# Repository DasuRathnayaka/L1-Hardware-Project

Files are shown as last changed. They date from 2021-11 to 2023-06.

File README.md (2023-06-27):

# Automated Camera Stand
## What is this?
This is an Automated camera stand which possible to guide using GPS coordinates with an obstacle avoidance navigation system. This is made to help wildlife photographers to take good photographs in insecure environments.

## Why is this?
We mainly focused on avoiding danger for the wildlife photographer and the safety of the camera. In this period many wildlife photographers are facing danger while taking photos due to animal attacks. We are going to introduce a new device to avoid such a problem.

## 3D Model




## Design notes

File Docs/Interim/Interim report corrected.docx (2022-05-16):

Faculty of Information Technology

Automated Camera Stand

Group 47

P.A.U.D. Herath | 204074M
P.H.P. Jayathilaka | 204087F
D.M.B.M. Dissanayake | 204047J
S.P.S.N. Pathirana | 204150T
A.M.D.B. Rathnayaka | 204179N
Supervisor’s Name: Mr. B.H. Sudantha Dean/Senior Lecturer Faculty of Information Technology Signature of Supervisor: ……………………………. | Ms. Chanduni Gamage Lecturer Dept. of Information Technology …………………………….

Date of Submission: 30/11/2021

# Table of Content

# Table of Figures

# 1 Introduction

Wildlife photography is a popular category of photography, done by beginners, enthusiasts, and professionals. When taken technically, it involves capturing any type of animal, from birds to insects to butterflies to mammals. But wildlife photographers most commonly take photos of mammals, reptiles, amphibians, and birds. Wildlife photography is a loosely defined profession that demands a passion for nature and art. These photographers make a career of traveling to remote areas and taking pictures of wild animals and natural scenery with a risk.[01]

Wildlife photographers are some of the world’s most valued professionals. According to the U.S. Bureau of Labor Statistics, the average annual wage of most wildlife photographers was $50,290 per year, or $24.18 per hour, as of May 2020. So, this is a higher-paying job. Due to this reason, many new photographers have come to this field. And most wildlife photographers are freelancers. The amount of money that a freelance wildlife photographer makes is largely determined by his talent and ability to get decent-paying work. From all these things it is crystal clear that wildlife photography is one of the best careers in the world.

Wildlife photography is one of the most dangerous professions in the world. The following instances are examples of the dangerous which happen for wildlife photographers. One such incident happened in May of 2000 when a female wildlife photographer was attacked and partially eaten by a 112-pound female black bear in Tennessee. Last year in Colorado a wildlife biologist and photographer, Tom Mussel, got too close to a cow elk and her calf, and he was attacked when he stumbled as he tried to escape the charging cow. Elk and deer will attack humans when they feel cornered or threatened. A southern California man killed by a grizzly bear in Alaska's backcountry was shooting photos of the animal that killed him just moments before the attack, a National Park Service official said Sunday. The bear that killed Richard White, 49, was still with his body when rangers found him in Danail National Park, the official said. Photographs found in his camera revealed that White was watching the bear for at least eight minutes near a river before the attack [02].

From our project, we mainly focused on avoiding the danger for the wildlife photographer and the safety of the camera. In this period many wildlife photographers are dying while taking photos due to animal attacks. We are going to introduce a new device to avoid such a problem.

It is an Automated Camera Stand.

# 2 Literature Survey

In modern cameras, we have the feature to take remote photos. We call it remote photography. Therefore, we can take pictures even if we are far from the camera. But there is no way to bring the camera near to the animals rather than a person carrying the camera.

From the photographer’s side:

- Danger to the life of the photographer.
- Time wastage of the photographer.
- Can’t find a good angle to take a photo.
- Can’t get close enough to the animal.
- Constantly changing lighting conditions.
- No safety to the camera.

From the animal’s side:

- Animals get scared when we try to reach them.
- The behaviors of the animals may change. From the environment side:
- Bad impact on biodiversity.

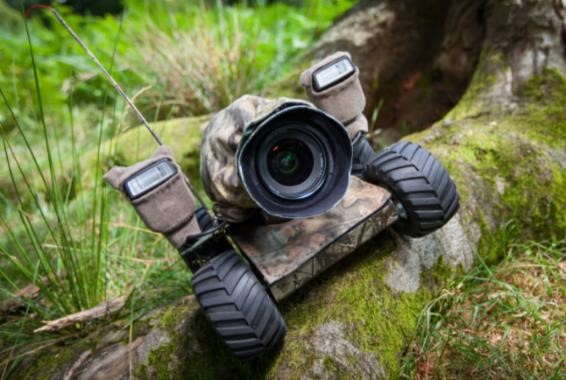
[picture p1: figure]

Therefore, when we try to find out a solution for this we came across with some similar projects.

## 2.1 Beetle cam for wildlife photography

Beetle cam has designed to take wildlife photographs. Wildlife photographer Will Burrard-Lucas had long wanted to add up-close-and-personal images of iconic African animals to his portfolio. But to get those intimate shot of lions and leopards, he would need to crawl up right next to their sharp-toothed faces [03]

Figure 2-1 Beetle cam

This beetle cam can move forward and backward by using the remote controller. And also, beetle cam can be turned by using the wheels.

In our product we have all the functionalities same as the beetle cam. But there are some uncommon functionalities rather than this beetle cam. There is a special feature that can move the camera to the location easily by using GPS location guiding and can avoid obstacles itself. And also, can rotate the camera vertically using the remote controller. There is a siren for the safety of the camera.

## 1.1 VCT-VPR1 Remote Control Tripod

This tripod has been designed to hold a camera and this is controlled by a remote controller. This tripod can check vertical and horizontal alignment using a grid line button. And also bring the subject closer with the zoom controller in the remote.

# 3 Aim & Objectives

## 3.1 Aim

This project aims to the distance photography process to make sure it is safer and effective.

## 3.2 Objectives

The objectives of the project are as follows,

- Rotate the camera both vertically and horizontally.
- Move the stand according to the given GPS coordinates.
- Reach the target safely.
- Protect the camera from the animals by using the alarm.
- Control the camera holder using a remote controller.

# 4 Analysis and Design

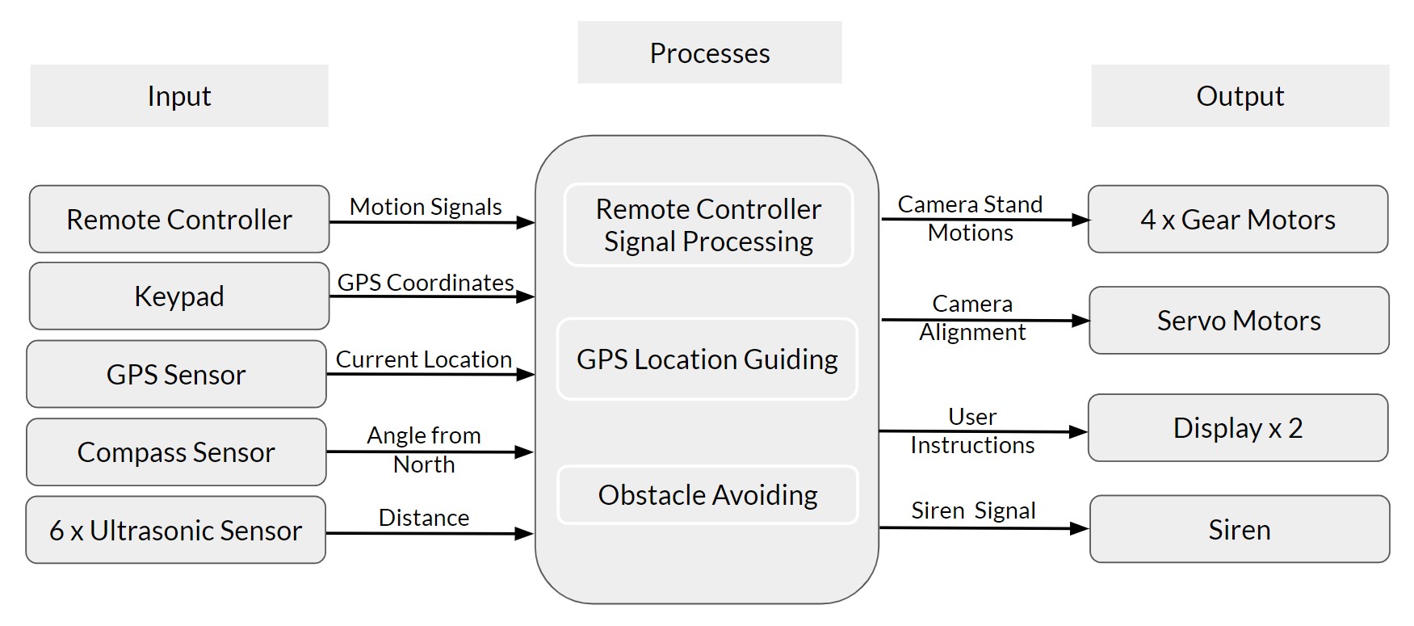
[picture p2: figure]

Figure 4-1 Block Diagram of Proposed System

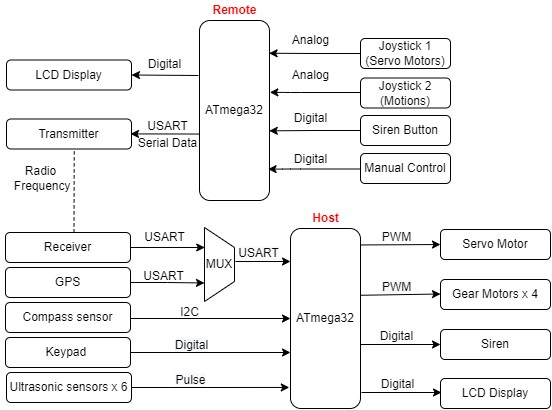
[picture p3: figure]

Figure 4-2 System Diagram of Proposed System

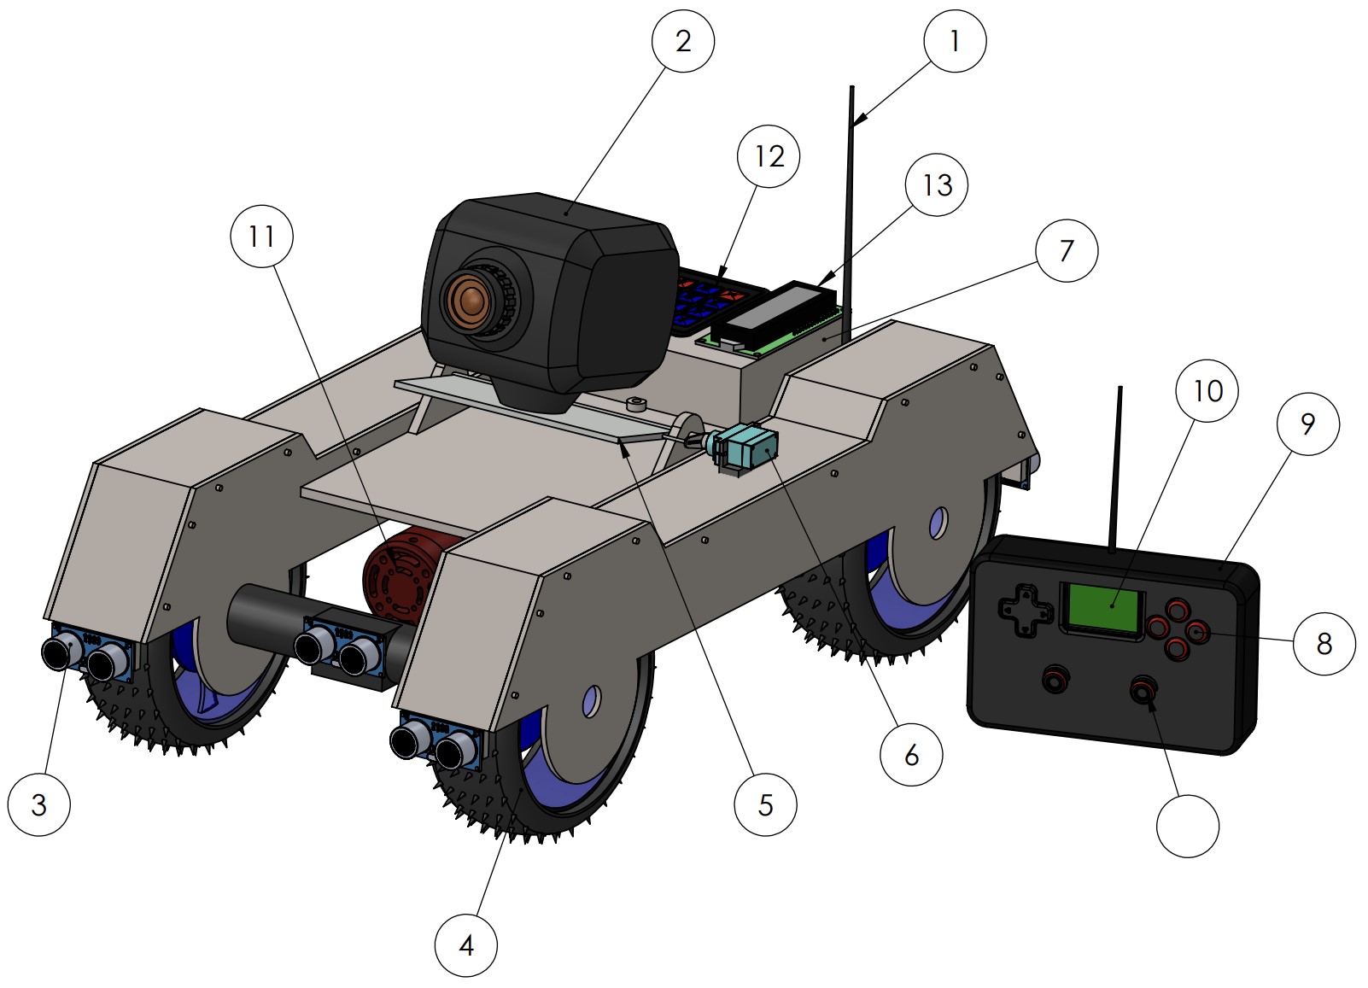
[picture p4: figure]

14

Figure 4-7 Named Camera Stand 3D view

1. RF Antenna
2. Camera
3. Ultrasonic sensors
4. Wheels with gear motors
5. Universal camera mount
6. Servo motor
7. Project box
  a. Atmega32 IC
  b. Compass sensor
  c. RF receiver
  d. GPS module
8. Remote controller buttons
9. Remote controller
10. LCD Display
11. Siren
12. 4x4 Numpad
13. LCD Display
14. Joystick

# 5 Testing and Implementation

In our project, there are two ATmega32 microcontrollers, one is for remote controller and the other one is for the host (Camera stand). The microcontroller takes inputs related to motions and angles from two joysticks. The microcontroller of the remote processes the data and transmit from remote to host through RF (Radio Frequency) modules.

Then the microcontroller of the host gets data from the RF receiver module and GPS module using a 2×1 multiplexer. And also, the microcontroller of the host takes inputs from ultrasonic sensors, compass sensor and the keypad. The microcontroller of the host processes that data and send data to the servo motors and gear motors. And also send digital signals to the display and the siren.

## 5.1 Thumb Joystick

These joystick modules are used to control movements of the camera stand and the vertical camera angle.

Joystick is an input device. Analog joystick is sometimes called as Control Stick. It is used to control the pointer movement in 2-dimension axis. It is made by mounting two potentiometers at a 90 degrees angle to read user’s input. The potentiometers are connected to a short stick centered by springs. One potentiometer is used to get the analog output voltage for X-Direction movement related to move the camera stand forward backward and the other potentiometer is used to get the analog output voltage for Y-Direction movement related to move the camera stand left right. The potentiometers are connected between +VCC and Ground. They simply behave as voltage divider network. The joystick has one freewheeling Holder. According to the holder movement, the potentiometer knob changes its position and resistance of the potentiometer. This module produces an output of around 2.5V from X and Y when it is in resting position. Moving the joystick will cause the output to vary from 0v to 5V depending on its direction. If we connect this module to a microcontroller, we can expect to read a value of around 512 in its resting position. When we move the joystick, we should see the values change from 0 to 1023 depending on its position. Operating Voltage is 5V. Operating current is 3.5 mA. Internal potentiometer value is 10kΩ.Operating Temperature is 0 to 70°C. There are five pins such that Ground pin, Vcc, VRx, VRy and Switch pin.

## 5.2 Liquid Crystal 16 × 2 Display

These LCD displays are used to show GPS coordinates and the current remote's configurations. By using this we can convert camera stand more user friendly.

## 5.3 Motor drive

Motor drive is used to amplify the PWM signal from the Atmega32 and supply it to the gear motors.

## 5.4 Servo Motor

This servo motor is used to change the vertical angle of the camera. Servo motor is used to change the vertical angle of the camera. A servo motor is an electromechanical device that produces torque and the velocity based on the supplied current and voltage. A servo motor works as part of a closed loop system providing torque and velocity as command from a servo controller utilizing a feedback device to close the loop. The feedback device supplies information such as current, velocity or position to the servo controller, which adjusts the motor action depending on the command parameters.

In our project, Servo motors is used for changing the vertical angle of the camera within 90 degrees. When we take a photo of a wild animal, we have to change the orientation of the camera according to the orientation of the animal.

When the signal is received to the Atmega32 microcontroller in the host, it provides a signal to the servo motors to make the correct angle of the servo motors. For that we use the PWM method to process that.

Servo motor has three colour wires. The red colour wire should be connected to the power supply. Brown colour wire connects to the Ground and the Orange colour wire connects to the PWM signal given by the Atmega32 in the host. These are the specifications of the servo motor, speed is 0.1 per second, torque is 2.5kg per cm, weight is 14.7 g and operating voltage is 4.8V to 6V.

## 5.5 Siren

The siren is used to protect the camera stand. when the wild animals come to the attack the camera stand, just sound the siren for run off the animals. These are the specifications of the siren , operating maximum voltage is 12V, operating maximum current is 6 A, Sound intensity is 112 -116 decibels and speed is 1000 rpm.

## 5.6 RF Receiver and Transmitter

We use a 433 MHz RF module to maintain the communication between the remote controller and the host. RF module, as the name suggests, uses radio frequency to send signals. These signals are transmitted at a particular frequency and a baud rate. A receiver can receive these signals only if it is configured for that frequency. Out of that I am responsible for transmitter module. The transmitter module takes serial input and transmits these signals through RF.

The transmitter module consists of four pins namely Vcc, ground, ATAD, and optional ANT pin as shown. The Vcc pin has a wide range input voltage from 3V to 12V. The transmitter consumes a minimum current of 9mA and can go as high as 40mA during transmission. The ATAD pin is the data pin to transmit the signal. This signal modulated and then sent on air at a frequency of 433MHz. This module has an antenna pin which helps to connect the external wire to extend the range up to 100 meters. The size of the antenna will depend on the operating frequency.

The RF transmitter receives serial data and transmits it wirelessly through its RF antenna. The transmission occurs at the rate of 1 Kilobits per second to 10 Kilobits per second.

## 5.7 Gear motor

A gear motor is an all-in-one combination of a motor and gearbox. The addition of a gear head to a motor reduces the speed while increasing the torque output. The most important parameters in regard to gear motors are speed (rpm), torque and efficiency. In order to select the most suitable gear motor load, speed and torque required for the application have to be measured correctly. Most of DC motors can be complemented with unique gearheads.

Reference for the gear motor: https://islproducts.com/design-note/dc-motor-dc-gear-motor-basics/

## 5.8 Ultrasonic sensor

An ultrasonic sensor is an electronic device which measures the distance to an object by emitting an ultrasonic sound wave and converts the reflected sound into an electrical signal. Ultrasonic waves travel faster than the speed of audible sound. Ultrasonic sensors have two parts as the transmitter and receiver. Transmitter send an ultrasonic sound wave and then the receiver receives that wave and calcite the time took to come back to the receiver. And using these data ultrasonic sensor calculates the distance which have to that particular object. This is the way how the ultrasonic sensor works.

Reference for the gear motor: https://www.fierceelectronics.com/sensors/what-ultrasonic-sensor

## 5.9 4x4 Keypad

This is consist of 4 rows and 4 columns which consist of

## 5.10 GPS module

The GPS module uses the USART technology to communicate with the microcontroller. And when taking the specifications of the microcontroller, the operating voltage lies between 2.7V to 3.6V.In the GPS module, there is a GPS antenna to take GPS signals through Radio Frequency which are sent from the GPS satellites. Its serial baud rate lies between 4800 bits per second to two lakhs thirty thousand four hundred bits per second. But the default serial baud rate is nine thousand six hundred. The max supply current for this module is 67 mA.

When taking the pin configuration of the GPS module, there are 4 pins. Vcc pin is for power supply and GND pin is used to ground the GPS module. TXD pin is for the transmission of data and the RXD pin is for the receiving of data. In this project, I have only to transfer data from the GPS module to the Atmega32 chip, and therefore I was only needed to connect the TXD pin of the GPS module with the atmega32 RXD pin. RXD pin is the 14th pin. This is all about the pin configuration of the GPS module.

## 5.11 Compass sensor

For the GPS location guiding algorithm, identifying the current facing direction of the camera stand is a must. The module used is the HMC5883L magnetometer module. This uses the I2C protocol for communication with the Atmega32 microcontroller. According to the documentation, the supply voltage for the magnetometer module lies between 2.7 V to 6.5 V. The max voltage is 6.5 V. The frequency to pass serial data is up to 400kHz and the operating temperature is between -22 to 185 Fahrenheit. The pin configuration is that there are 5 pins in the magnetometer module. The Vcc pin takes power to the module, and the GND pin is to ground. SCL is the serial clock pin, and the SDA is the serial data pin. DRDY is the data-ready interrupt pin.

# 6 Previous Action Plan

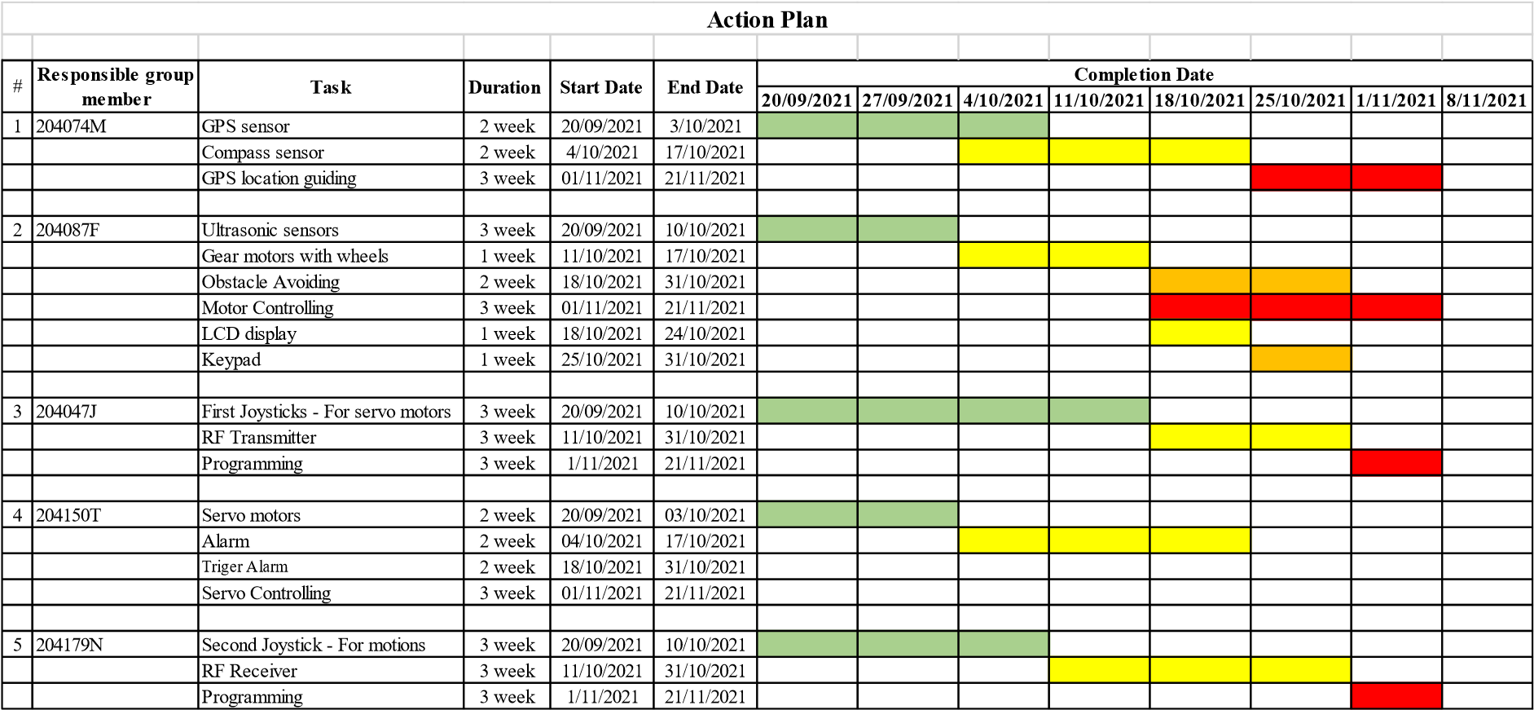
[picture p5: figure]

# 7 Action Plan for Remaining Work

| | | Action Plan
| Responsible group member | Task | Duration | Start Date | End Date | Completion Date
| | | | | | 31/12/2021 | 31/1/2022 | 1/2/2022 | 1/3/2022 | 1/4/2022 | 9/5/2022
1 | 204074M | Compass sensor | 1 month | 31/12/2021 | 31/1/2022
| | GPS location guiding | 1 month | 1/2/2022 | 1/3/2022
| | Test and implementation | 2 months | 2/3/2022 | 9/5/2022
2 | 204087F | Obstacle Avoiding | 1 month | 31/12/2021 | 31/1/2022
| | Motor Controlling | 1 month | 1/2/2022 | 1/3/2022
| | Test and implementation | 2 months | 2/3/2022 | 9/5/2022
3 | 204047J | First Joysticks - For servo motors | 1 month | 31/12/2021 | 31/1/2022
| | RF Transmitter | 1 month | 1/2/2022 | 1/3/2022
| | Test and implementation | 2 months | 2/3/2022 | 9/5/2022
4 | 204150T | Servo motors | 1 month | 31/12/2021 | 31/1/2022
| | Test and implementation | 1 month | 1/2/2022 | 1/3/2022
| | Trigger Alarm | 1 month | 2/3/2022 | 1/4/2022
| | Servo Controlling | 1 month | 2/4/2022 | 9/5/2022
5 | 204179N | Second Joystick - For motions | 1 month | 31/12/2021 | 31/1/2022
| | RF Receiver | 1 month | 1/2/2022 | 1/3/2022
| | Test and implementation | 2 months | 2/3/2022 | 9/5/2022

# Appendix A

# 8 Cost Estimation and Expenditure so far

Component | Unit Price | Quantity | Price (LKR)
68mm RC Car Tire Wheel | Rs. 300.00 | 4 | Rs. 1,200.00
Liquid Crystal 16x2 Display Module | Rs. 300.00 | 1 | Rs. 300.00
2 Pin Switch | Rs. 15.00 | 2 | Rs. 30.00
Thumb Joystick Module | Rs. 150.00 | 2 | Rs. 300.00
RF 433MHz Transmitter/Receiver | Rs. 200.00 | 1 | Rs. 200.00
GY-271 Electronic Triple Axis Compass Module | Rs. 700.00 | 1 | Rs. 700.00
Membrane Keypad - 16 Key | Rs. 180.00 | 1 | Rs. 180.00
HC-SR04 Ultrasonic Sensor Module | Rs. 200.00 | 6 | Rs. 1,200.00
NEO-6M GPS Module | Rs. 1,850.00 | 1 | Rs. 1,850.00
L298N DC Motor Driver Module | Rs. 350.00 | 2 | Rs. 700.00
Servo Motor | Rs. 750.00 | 1 | Rs. 750.00
Atmega32 Microcontroller | Rs. 550.00 | 2 | Rs. 1,100.00
11.1V 2200mAh 3S 25C Li-Po Battery | Rs. 2,800.00 | 1 | Rs. 2,800.00
12V 2000mAh Li-Po Battery | Rs. 1,750.00 | 1 | Rs. 1,750.00
DC Gear Motor 12v 180 RPM | Rs. 950.00 | 4 | Rs. 3,800.00
| | Total | Rs. 16,860.00

[4],[5]

# Appendix B

# 9 Individual Contribution to the Project

## 9.1 P.A.U.D. Herath - 204074M

I studied about the GPS module. Studied about the way how the GPS signals generate and the way of GPS working. Learned about the theory regarding the USART communication. Understood the theory behind the multiplexer to connect the GPS module and the compass sensor module.

### 9.1.1 GPS module (NEO-6M)

The GPS module has a GPS antenna, battery, an EEPROM and a position fix LED indicator. The pins in the NEO-6M are VCC, Tx, Rx and GND. Understood that the D0 and D1 pins must be used to take the serial data using the GPS module. Specifications are that the Operating Voltage is 2.7V - 3.6V. The serial Baud rate lies between 4800 and 230400. The default baud rate is 9600. The operating current of the NEO-6M GPS module is 45mA.

### 9.1.2 Multiplexer

When taking the inputs related to the GPS module and the receiver, I had to use the same pins D0 and D1. Therefore, I used a multiplexer to carry this out.

### 9.1.3 USART communication

To take the serial inputs from the GPS module, I used the USART method.

## 9.2 P.H.P. Jayathilaka 204087F

I have studied about Ultrasonic sensors, Display, Keypad, ADC, PWM. I have started studying about USART. Also, started to study interfacing components with the ATmega32 microcontroller and how to connect components to the microcontroller.

### 9.2.1 Ultrasonic sensor (HC-SR04)

I am using 6 ultrasonic sensors to avoid obstacles. There are 4 pins in the ultrasonic sensor. (VCC, Trig Pin, Echo Pin, GND)

These are the specifications of Ultrasonic sensor. The working power of the ultrasonic sensor is DC 5Vand 15mA,

Working frequency is 40Hz, accurate range is 2cm – 40cm,

Measuring angle is 15 degrees, trigger input signal is 10µS TTL pulse

echo output signal input TTL lever signal and the range in proportion

### 9.2.2 Gear Motors

Due to lack of eight PWM pins for four motors, I had to couple motors as left and right. Then needed PWM pins reduced to four. Furthermore, I used only one PWM pin and a digital pin per side. It is configured by code.

These are the specifications of gear motors

the working voltage is 12V DC, Speed is 180 RPM,

It is a high torque motor and use L298NH – bridge motor drive

## 9.3 D.M.B.M. Dissanayake - 204047J

I have studied about Joystick, RF Transmitter and ADC. I have started to study interfacing components with the ATmega32 microcontroller and how to connect components to the microcontroller.

In our project, I used a joystick to get inputs related to the angle of servo motors. The microcontroller of the remote gets analog inputs from this joystick. We need knowledge about ADC on AVR ATmega32 to process that analog signal. To get this analog input, I had to use A0 pin in the ATmega32 microcontroller. Furthermore, I used a 433 MHz RF transmitter to transmit the above-processed data from the microcontroller.

### 9.3.1 Thumb Joystick

There are 5 pins in the joystick module.

VCC, GND, VRx, VRy, SW

Specifications of thumb joystick module, operating voltage is 5V. Internal potentiometer value is 10kΩ. Operating Temperature is 0 to 70 C֩.

There is no joystick module in proteus. Therefore, I used a variable resistor to connect with the microcontroller.

## 9.4 S.P.S.N. Pathirana 204150T

As a member of our group, I have to work with a servo motor and a siren. First, I studied about the servo motor, and the siren. Second, I selected a suitable type of servo motor and a siren. After that, I started to learn about how they are working. Finally ,started to learn about how they are interfacing with Atmega32 microcontroller

In this project, servo motor is used to change the vertical angle of the camera, according to the signal of the joystick.

### 9.4.1 Servo Motors

These are the specifications of servo motor:

The speed of the servo motor is 0.1 per second.

Torque is 2.5 kg/cm. The weight is 14.7g and

the voltage is 4.8V – 6V

### 9.4.2 Siren

We used a siren to protect the camera stand. when the wild animals come to the attack the camera stand, we just sound the siren for run off the animals. The siren sounds according to the signal given by the siren button in the remote controller. These are the specifications of the siren, operating maximum voltage is 12V, operating maximum current is 6 A, Sound intensity is 112 -116 decibels and speed is 1000 rpm.

## 9.5 A.M.D.B. Rathnayaka 204179N

I studied about the joystick, RF receiver, ADC Technology and started to learn about how the components are working and interfacing with ATmega32 microcontroller. In our project, I have to give inputs to the ATmega32 microcontroller of the remote from the joystick. Moreover, it gives inputs to the microcontroller of the host from the RF receiver.

### 9.5.1 433 MHz Receiver

Receiver uses the USART communication to communicate with the Atmega32 microcontroller of the host. The operating frequency is 433 MHz, the operating voltage is 5V and the supply current is 3.5 mA.

### 9.5.2 Thumb Joystick

There are 5 pins in the joystick module. And the pins in this module are VCC, GND, VRx, VRy, SW. The Operating Voltage is 5V. The Internal potentiometer value is 10kΩ and the operating temperature is 0 to 70 C֩. There is no joystick module in proteus. Therefore, I used two variable resistors to connect with the microcontroller.

# Appendix C

# References

[1] A. Duke, “Hiker photographs bear just before fatal grizzly attack,” CNN, 26-Aug-2012.
[2] J. Dempsey, “Introduction to wildlife photography: A guide for beginners,” Phototraces.com, 03-Jan-2020. [Online]. Available:

https://www.phototraces.com/b/wildlife-photography/. [Accessed: 28-Nov-2021].

[3] M. Gallucci, “These robots are transforming how we see wildlife,” Mashable, 12-Jan2017. [Online]. Available: https://mashable.com/article/robots-wildlife-photography. [Accessed: 28-Nov-2021].
[4] “Microchip.lk – one stop for all your electronics…,” Microchip.lk. [Online]. Available: https://microchip.lk/. [Accessed: 28-Nov-2021].
[5] “TRONIC.LK,” Lankatronics.com. [Online]. Available: https://lankatronics.com/. [Accessed: 28-Nov-2021].

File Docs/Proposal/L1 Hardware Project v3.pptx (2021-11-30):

## Automated Camera Stand

IN 1900 (ICT Project)

Group - 47

Hardware Project

## Group Members

Name | Registration Number | Photos
P.A.U.D. Herath (Team Leader) | 204074M
D.M.B.M. Dissanayake | 204047J
P.H.P. Jayathilaka | 204087F
S.P.S.N. Pathirana | 204150T
A.M.D.B.Rathnayaka | 204179N

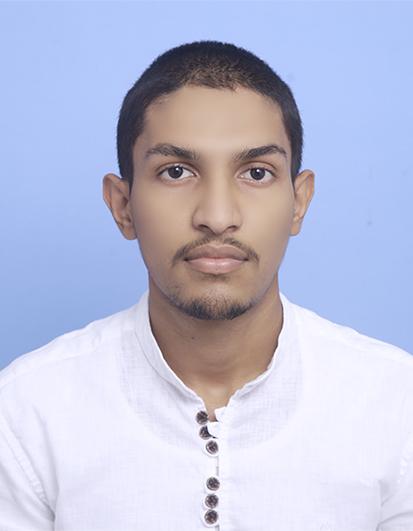
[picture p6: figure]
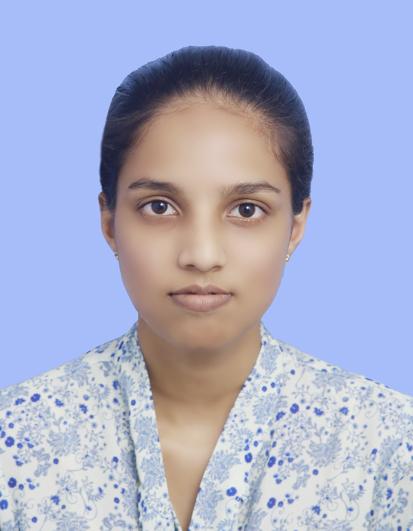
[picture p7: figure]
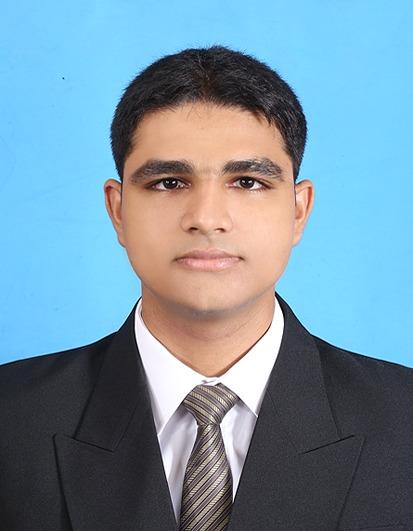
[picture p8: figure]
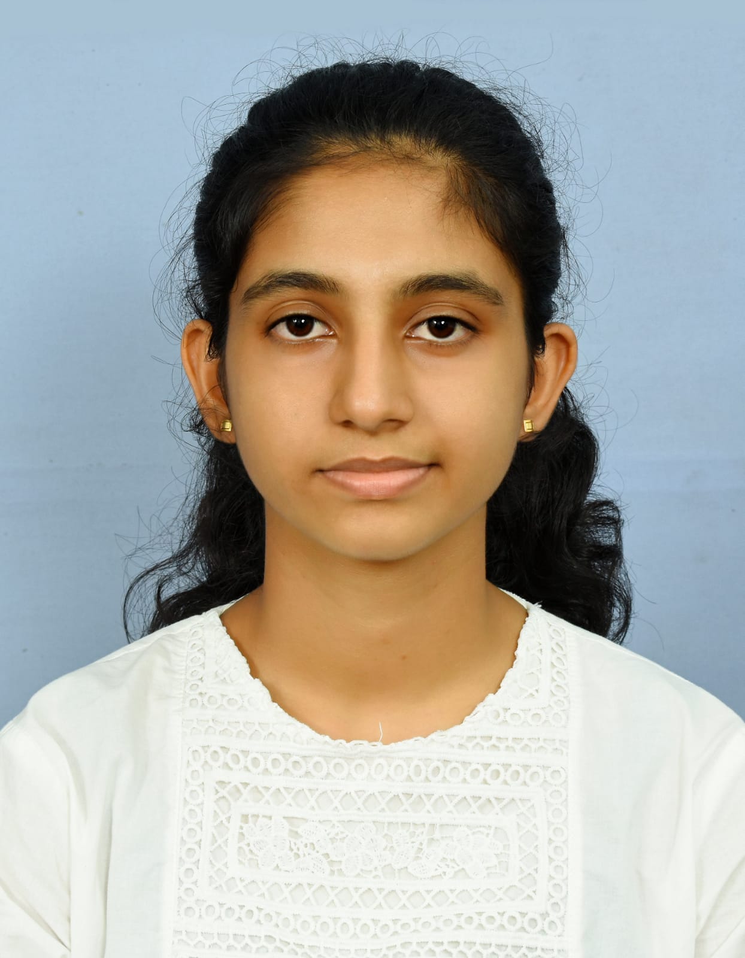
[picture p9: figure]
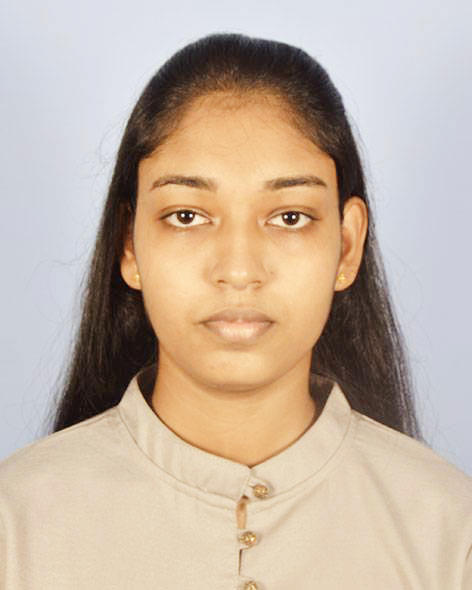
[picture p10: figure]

## Problem in Brief…

Not having a proper mechanism to bring the camera near to the required places or animals rather than a person carrying the camera.

- From photographer’s side :
  - Danger to the life.
  - Time wastage.
  - Can’t find a good angle.
  - Can’t get close enough.
  - Constantly changing lighting conditions.
- From animal’s side :
  - Animals get fear when we try to reach them.
  - Behaviours of the animals may get changed.
- From environment side :
  - Bad impact on biodiversity.

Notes: In modern cameras we have the feature to take remote photos (remote photography). Therefore, we can take pictures even we are far from the camera. But there is not a way to bring the camera near to the animals rather than a person carry the camera.
When we analyze the problem we found 3 main sides of this problem.
When we take from the photographer’s side; Imagine we need to capture a very close wild animal photo, we can’t reach it. Because It will be very dangerous. In past few years many wildlife photographers has died due to animal attacks.
We have to spend lot of time, until the required animals come, to capture their photos.
When the photographer need to take a good quality photograph, taking a close correct angle is an essential thing. But the photographers can’t go near the animals to achieve those requirements.
From animal’s side : If the animal is an innocent one, it does not stay until we go near them.

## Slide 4

Project Aim

- Automate the distance photography process to make sure it is safer and effective.

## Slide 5

Project Objectives

- Rotate the camera both vertically and horizontally.
- Move the stand according to given GPS coordinates.
- Reach the target safely.
- Adjust the height of the rod.
- Protect the camera from the animals by using the alarm.
- Control the camera holder using a remote controller.

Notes: If an animal try to attack the camera holder then we can sound the alarm. Like that we can ensure the safety of the camera.

## Proposed Solution

Processes

Remote Controller Signal Processing

GPS Location Guiding

Obstacle Avoiding

Input

Output

Remote Controller

Motion Signals

Camera Stand Motions

4 x Gear Motors

Keypad

GPS Coordinates

Camera Alignment

Servo Motors

GPS Sensor

Current Location

Compass Sensor

Angle from North

User Instructions

Display x 2

6 x Ultrasonic Sensor

Distance

Siren Signal

Siren

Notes: Remote Controller sends motion signals and processes the remote controller signals to rotate the motors and also the alarm.
We can input the GPS coordinates by using the Keypad.

## Sketch of the camera stand

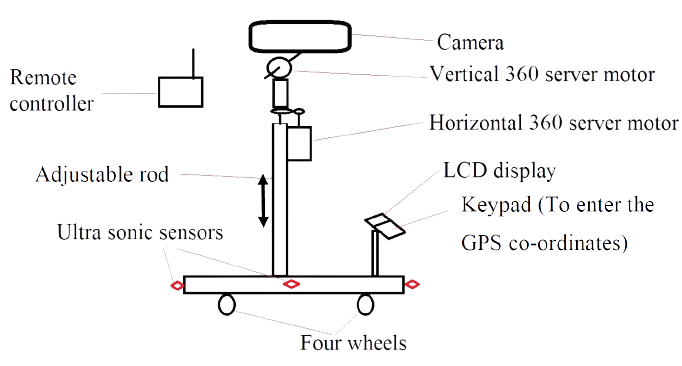
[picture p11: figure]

Siren

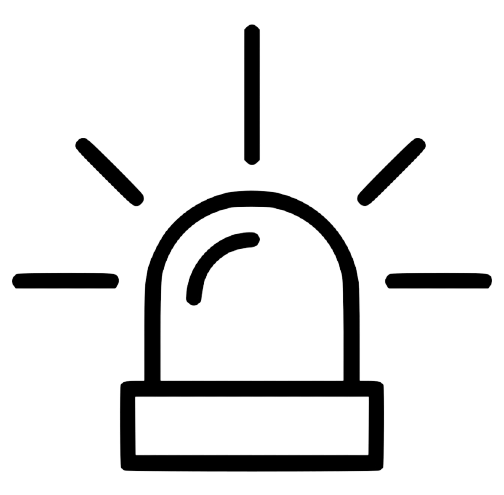
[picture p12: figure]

Project Box

- This head section fits with the stage

))

RF antenna

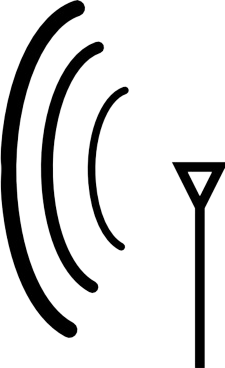
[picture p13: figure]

## Resources (Software)

- Atmel Studio (Microcontroller Coding)

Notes: Up to this state we identified only these softwares. And it may be changed. The softwares are ; 1. 2. 3.

## Resources (Hardware)

- Microcontroller
- GPS Module
- RF Transmitter and Receiver
- Ultrasonic sensor
- Gear Motors
- Servo Motors
- LCD Module
- Motor Driver Module
- Electronic Compass Module
- Keypad
- Li-Po Batteries
- Joystick Module

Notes: These are the hardwares which we suppose to use.

## Cost Estimation

Component | Unit Price | Quantity | Price (LKR)
Membrane Keypad - (https://lankatronics.com/Membrane-Keypad-16-key) 16 Key (https://lankatronics.com/Membrane-Keypad-16-key) | 180 | 1 | 180
HC (https://lankatronics.com/HC-SR04-Ultrasonic-Sensor-module)-SR (https://lankatronics.com/HC-SR04-Ultrasonic-Sensor-module)04 Ultrasonic Sensor Module (https://lankatronics.com/HC-SR04-Ultrasonic-Sensor-module) | 200 | 6 | 1200
NEO-6M GPS Module (https://lankatronics.com/index.php?route=product/product&product_id=469&search=gps&description=true) | 1850 | 1 | 1850
L298N DC Motor Driver Module (https://lankatronics.com/L298-DC-Motor-Driver-Module-Normal) | 350 | 2 | 700
Servo Motor (https://lankatronics.com/MG995-Servo-Digital-Metal-Gear-Servo-Motor) | 750 | 2 | 1500
Atmega32 Microcontroller (https://lankatronics.com/Atmega32A-PU-PDIP) | 550 | 2 | 1100
11.1V 2200mAh 3S 25C Li-Po Battery (https://microchip.lk/product/11-1v-2200mah-3s-25c-lipo-battery-local/) | 2800 | 1 | 2800
12V 2000mAh Li-Po Battery (https://microchip.lk/product/12v-2000mah-rechargeable-lithium-polymer-battery-li-po-lipo-li-po/) | 1750 | 1 | 1750
DC Gear Motor 12v 180 RPM (https://lankatronics.com/370-DC-Gear-Motor-12V-180rpm) | 950 | 4 | 3800

## Cost Estimation (Contd.)

Component | Unit Price | Quantity | Price (LKR)
68mm RC Car Tire Wheel (https://lankatronics.com/68mm-RC-Car-Tire-Wheel) | 300 | 4 | 1200
Liquid Crystal 16x2 Display Module (https://lankatronics.com/index.php?route=product/product&product_id=480) | 300 | 1 | 300
2 Pin Switch (https://lankatronics.com/Rocker-Switch-ON-OFF) | 15 | 2 | 30
Thumb Joystick Module (https://lankatronics.com/index.php?route=product/product&product_id=434) | 150 | 2 | 300
RF 433MHz Transmitter/Receiver (https://lankatronics.com/433Mhz-RF-transmitter-and-receiver-kit) | 200 | 1 | 200
28BYJ-48 Stepper Motor with Driver (https://microchip.lk/product/28byj-48-stepper-motor-with-driver/) | 370 | 1 | 370
GY-271 Electronic Triple Axis Compass Module (https://microchip.lk/product/gy-271/) | 700 | 1 | 700
Total | | | 17,980

Lankatronics (Pvt) Ltd (https://lankatronics.com), Microchip.lk

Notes: The total cost which we suppose to spend for this project is Seven thousand nine hundred and eighty rupees.
And we took all these unit prices referring the Lanka tronics private limited and Microchip.lk web sites.

## How the works are divided…?

| Hardware Part | Software Part
Member - 01 | Servo motors Alarm | Servo Controlling Trigger Alarm
Member - 02 | GPS sensor Compass sensor | GPS location guiding
Member - 03 | Ultrasonic sensors Gear motors with wheels. LCD display and Keypad. | Obstacle Avoiding Motor Controlling Get Inputs from keypad and display
Member - 04 , 05 | Custom remote controller RF Transmitter and Receiver | Communication between Remote and Camera stand

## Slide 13

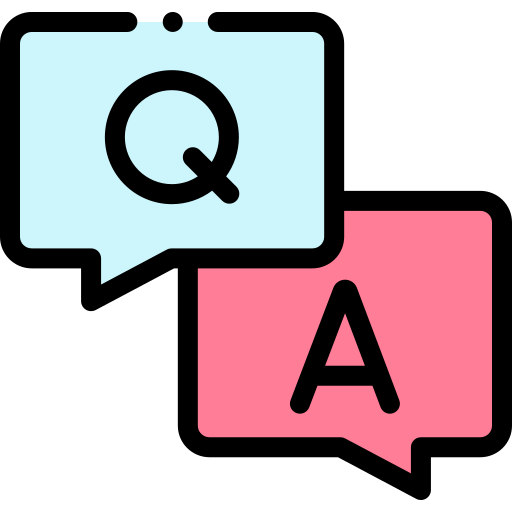
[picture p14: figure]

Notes: Sir , madam ; If there are any questions about the project we will be happy to answer them.

https://www.youtube.com/watch?v=cZm4ZjE-zaU

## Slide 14

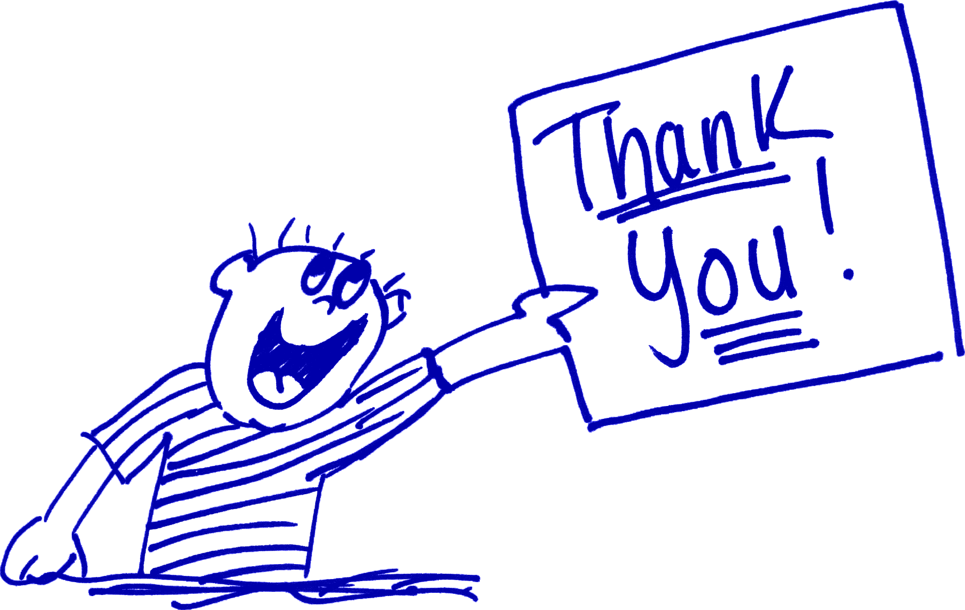
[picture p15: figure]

Group - 47

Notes: Our presentation is over, thank you !!

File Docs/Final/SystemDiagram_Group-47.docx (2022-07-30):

System Diagram

System Diagram of Remote Controller

Digital Signal

Display the auto and manual mode of the camera stand

Auto/Manual Button

DistanceJJ

Digital Signal

Changing the current state of the camera stand as auto and manual.

Siren Button

DistanceJJ

Digital Signal

On and off the siren in the camera stand.

16 x 2 LCD Display

User Instructions

nRF24L01 Transceiver Module

Distance

Sending the Radio Frequency signals to the camera stand through the nRF24L01 module of the remote controller.

Serial Data

Joystick-1

DistanceJJ

Analog Signal

Changing the vertical angle of the camera within 90 degrees.

Joystick-2

DistanceJJ

Analog Signal

Moving the camera stand forward and backward as well as left and right.

Output

Input

Processes

Process 3: Send serial data to the transceiver module using SPI.

Process 1: Get analog signal from two joysticks and convert it to Digital value using ADC.

Process 2: Get digital signals from two buttons and display it using I2C.

Maintain the connection with the Camera stand by using Radio Frequency

See Next Page

See Next Page

4 x Gear Motors

Camera Stand Motions

Digital Signal

To move the camera, stand by rotating the wheels.

Serial Data

NEO-6M GPS Module

To take the real time GPS coordinates which we need to calculate the angle to the user inputted GPS coordinate (user inputted GPS coordinates through the keypad.)

Digital Signal

Keypad

To take the GPS coordinates of the place which we need to move our camara stand.

Serial Data

HMC5883L Magnetometer

To take the current facing direction of the camera stand according to the true North.

Digital Pulse

4 x Ultrasonic Sensor

To detect and avoid obstacles while camera stand is moving.

Siren

Digital Signal

To chase away harmful animals when they try to attack the camera stand.

16 x 2 LCD Display

Serial Data

To display GPS coordinates, to display the status (auto or manual) and to display user messages.

Servo Motor

Camera Alignment

Digital Signal

To lift the camera according to the given angle by the remote controller.

Receiving the Radio Frequency signals which are coming from the nRF module of the remote controller.

Serial Data

nRF24L01 Transceiver Module

Distance

Process 3: If the mode is auto, the GPS coordinates will take from the user.

Process 2: If the mode is manual, get serial data from transceiver (related to joysticks) using SPI and process them.

Process 1: Get received serial data (related to auto/manual button) from transceiver module and according to that, initialize the manual and auto mode.

Process 4: By taking inputs from the GPS module, magnetometer module, and ultrasonic sensor detect the correct path to move the camera stand.

Process 6: While happening this process when the RF module sends a signal siren will be sounded.

Process 5: While finding the correct path according to the process-4 moving the camera stand by using the gear motors (wheels).

Process 7: While happening all these processes the user instructions are given through the LCD Display to the users.

System Diagram of Camera Stand

Group-47 IN1900 Hardware Project

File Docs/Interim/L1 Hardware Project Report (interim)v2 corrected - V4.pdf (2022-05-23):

## Faculty of Information Technology

## Automated Camera Stand

Group 47

P.A.U.D. Herath | 204074M
P.H.P. Jayathilaka | 204087F
D.M.B.M. Dissanayake | 204047J
S.P.S.N. Pathirana | 204150T
A.M.D.B. Rathnayaka | 204179N
Supervisor’s Name: | Mr. B.H. Sudantha
| Dean/Senior Lecturer
| Faculty of Information Technology
Signature of Supervisor: |

Ms. Chanduni Gamage
Lecturer
Dept. of Information Technology

Date of Submission: 30/11/2021

i

Table of Content

ii

Table of Figures

### 1 Introduction

Wildlife photography is a popular category of photography, done by beginners, enthusiasts,

and professionals. When taken technically, it involves capturing any type of animal, from birds

to insects to butterflies to mammals. But wildlife photographers most commonly take photos

of mammals, reptiles, amphibians, and birds. Wildlife photography is a loosely defined

profession that demands a passion for nature and art. These photographers make a career of

traveling to remote areas and taking pictures of wild animals and natural scenery with a risk.[01]

Wildlife photographers are some of the world’s most valued professionals. According to the

U.S. Bureau of Labor Statistics, the average annual wage of most wildlife photographers was

$50,290 per year, or $24.18 per hour, as of May 2020. So, this is a higher-paying job. Due to

this reason, many new photographers have come to this field. And most wildlife photographers

are freelancers. The amount of money that a freelance wildlife photographer makes is largely

determined by his talent and ability to get decent-paying work. From all these things it is crystal

clear that wildlife photography is one of the best careers in the world.

Wildlife photography is one of the most dangerous professions in the world. The following

instances are examples of the dangers which happen for wildlife photographers. One such

incident happened in May of 2000 when a female wildlife photographer was attacked and

partially eaten by a 112-pound female black bear in Tennessee. Last year in Colorado a wildlife

biologist and photographer, Tom Mussel, got too close to a cow elk and her calf, and he was

attacked when he stumbled as he tried to escape the charging cow. Elk and deer will attack

humans when they feel cornered or threatened. A southern California man killed by a grizzly

bear in Alaska's backcountry was shooting photos of the animal that killed him just moments

before the attack, a National Park Service official said Sunday. The bear that killed Richard

White, 49, was still with his body when rangers found him in Danail National Park, the official

said. Photographs found in his camera revealed that White was watching the bear for at least

eight minutes near a river before the attack [02].

From our project, we mainly focused on avoiding danger for the wildlife photographer and the

safety of the camera. In this period many wildlife photographers are dying while taking photos

due to animal attacks. We are going to introduce a new device to avoid such a problem.

It is an Automated Camera Stand.

### 2 Literature Survey

In modern cameras, we have the feature to take remote photos. We call it remote photography.

Therefore, we can take pictures even if we are far from the camera. But there is no way to bring

the camera near to the animals rather than a person carrying the camera.

From the photographer’s side:

- Danger to the life of the photographer.
- Time wastage of the photographer.
- Can’t find a good angle to take a photo.
- Can’t get close enough to the animal.
- Constantly changing lighting conditions.
- No safety to the camera.

From the animal’s side:

- Animals get scared when we try to reach them.
- The behaviors of the animals may change. From the environment side:
- Bad impact on biodiversity.

Therefore, when we try to find out a solution for this, we come across with some similar

projects as following.

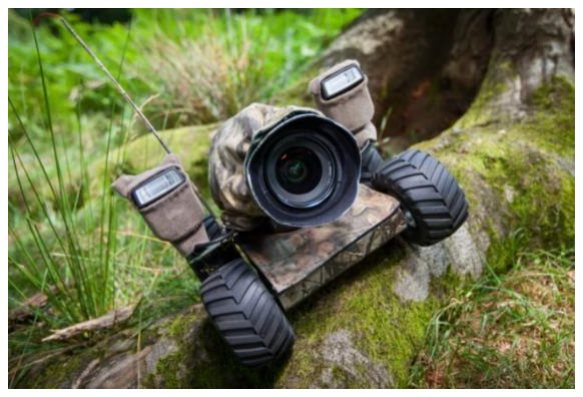
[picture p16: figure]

### 2.1 Beetle cam for wildlife photography

Beetle cam has designed to take wildlife photographs.

Wildlife photographer Will Burrard-Lucas had long

wanted to add up-close-and-personal images of iconic

African animals to his portfolio. But to get those

intimate shot of lions and leopards, he would need to

crawl up right next to their sharp-toothed faces [03]

This beetle cam can move forward and backward by

using the remote controller. And also, beetle cam can be turned by using the wheels.

Figure 2-1 Beetle Cam

### 2.2 VCT-VPR1 Remote Control Tripod

This tripod has been designed to hold a camera and this is controlled by a remote controller.

This tripod can check vertical and horizontal alignment using a grid line button. And also bring

the subject closer with the zoom controller in the remote.

In our product we have all the functionalities same as the beetle cam and the VCT-VPR1

Remote Control Tripod. But there are some uncommon functionalities rather than these

products. In our project, there is a special feature that can move the camera to the location

easily by using GPS location guiding and can avoid obstacles itself. And also, can rotate the

camera vertically using the remote controller. There is a siren for the safety of the camera. Both

these products are foreign products. And we were unable to find out a Sri Lankan product.

### 3 Aim & Objectives

### 3.1 Aim

This project aims to the distance photography process to make sure it is safer and effective.

### 3.2 Objectives

The objectives of the project are as follows,

- Rotate the camera both vertically and horizontally.
- Move the stand according to the given GPS coordinates.
- Reach the target safely.
- Protect the camera from the animals by using the alarm.
- Control the camera holder using a remote controller.

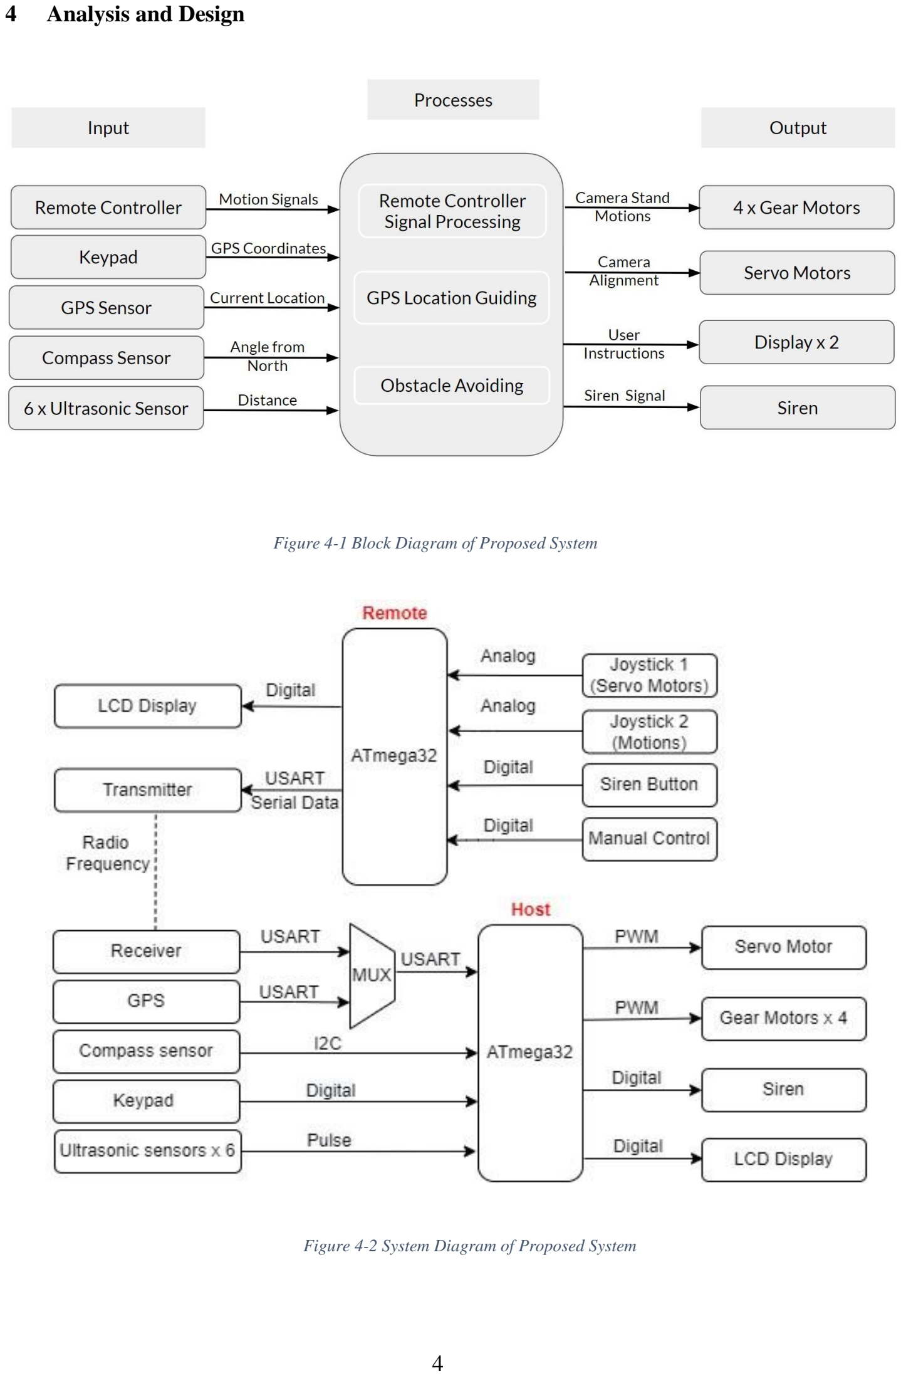
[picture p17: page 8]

### 4 Analysis and Design

Figure 4-1 Block Diagram of Proposed System

Figure 4-2 System Diagram of Proposed System

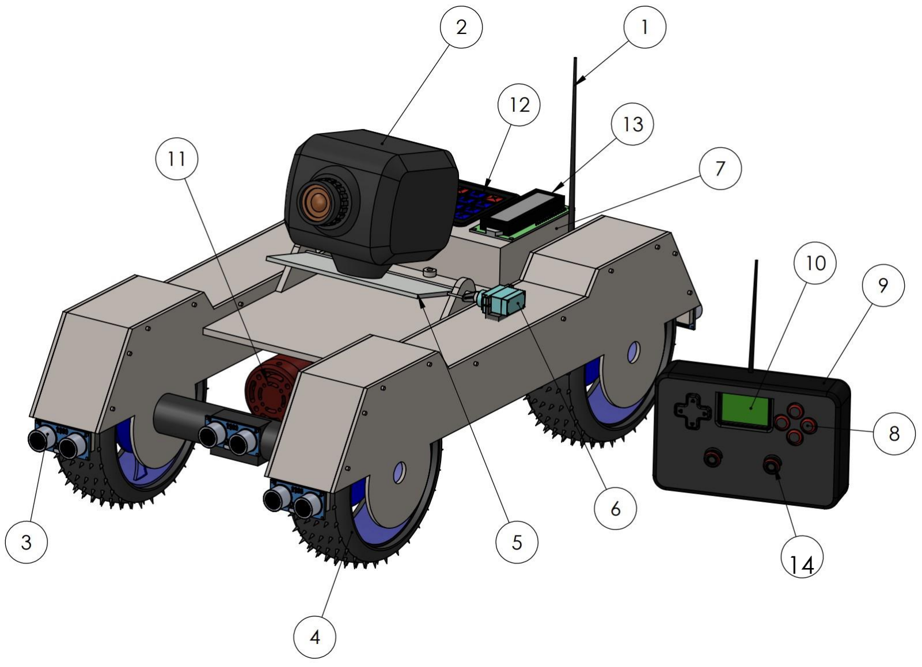
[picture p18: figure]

Figure 4-7 Named Camera Stand 3D view

1. RF Antenna
2. Camera
3. Ultrasonic sensors
4. Wheels with gear motors
5. Universal camera mount
6. Servo motor
7. Project box
a. Atmega32 IC
b. Compass sensor
c. RF receiver
d. GPS module
8. Remote controller buttons
9. Remote controller
10. LCD Display
11. Siren
12. 4x4 Numpad
13. LCD Display
14. Joystick

### 5 Testing and Implementation

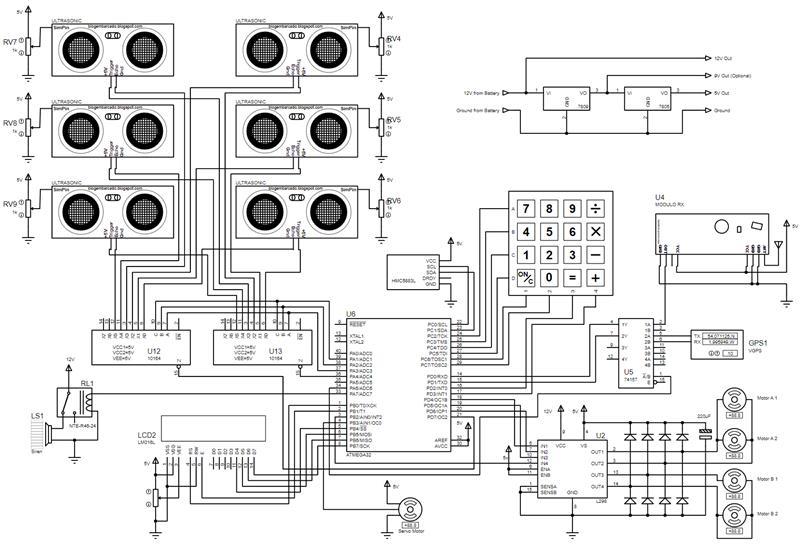
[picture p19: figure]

Figure 5-1 Schematic View of Circuit Diagram

In our project, there are two ATmega32 microcontrollers, one is for remote controller and the other

one is for the host (Camera stand). The microcontroller takes inputs related to motions and angles

from two joysticks. The microcontroller of the remote processes the data and transmits from remote

to host through RF (Radio Frequency) modules.

Then the microcontroller of the host gets data from the RF receiver module and GPS module using

a 2×1 multiplexer. And also, the microcontroller of the host takes inputs from ultrasonic sensors,

compass sensor, and the keypad. The microcontroller of the host processes that data and send data

to the servo motors and gear motors. And also send digital signals to the display and the siren.

### 5.1 Thumb Joystick

Joystick is an input device. It is used to control the pointer movement in 2-direction axis. It is made

by mounting two potentiometers at a 90 degrees angle to read user’s input. The potentiometers are

connected between +VCC and Ground. They simply behave as voltage divider network. The joystick

has one freewheeling holder. According to the holder movement, the potentiometer knob changes

its position and resistance of the potentiometer. This module produces an output of around 2.5V

from X and Y when it is in resting position. The output varies from 0v to 5V depending on its

direction according to the holder movements. If this module connect to a microcontroller, then can

expect to read a value of around 512 in its resting position. Operating Voltage is 5V. Operating

current is 3.5 mA. Internal potentiometer value is 10kΩ. Operating Temperature is 0 to 70°C. There

are five pins such that Ground pin, Vcc, VRx, VRy and Switch pin. In the project, thumb joysticks

are used to get the analog output voltage related to move the camera stand forward backward, to get

the analog output voltage related to move the camera stand left right and to give the analog inputs

to the servo motor related to changing the angle.

### 5.2 Liquid Crystal 16 × 2 Display

LCD displays are used to show GPS coordinates and the current remote's configurations. By using

this LCD display, the camera stand becomes more user friendly. The LCDs have a parallel interface

that the microcontroller has to manipulate several interface pins at once to control the display.

The interface consists of many numbers of pins. A register selection (RS) pin that controls writing

data in the LCD's memory. There is a capability of selecting either the data register, which holds

what goes on the screen, or an instruction register, which is where the LCD's controller looks for

instructions on what to do next. There is a pin named Read/Write (R/W) to select the reading mode

or writing mode and has an enable pin that enables writing to the registers. There are 8 data pins (D0

-D7). The states of these pins (high or low) are the bits that user is writing to a register when write,

or the values user is reading when read. There is a display contrast pin (Vo), power supply pins (+5V

and GND) and LED Backlight pins that can use to power the LCD, control the display contrast, and

turn on and off the LED backlight, respectively. The process of controlling the display involves

putting the data that formsthe image of what user wantsto display into the data registers, then putting

instructions in the instruction register.

### 5.3 Motor drive

Motor drive is used to amplify the PWM signal from the Atmega32 and supply it to the gear motors.

This drive can handle up to 50V and a maximum of 2.5A. Maximum logical supply and enable

voltages are 7V. This is a dual full-bridge driver. So, both sides can be handled by a single drive.

Pin configuration is quite simple. There are two input pins, two output pins and a single enable pin

for each side.

### 5.4 Servo Motor

Servo motor is used to change the vertical angle of the camera within 90 degrees. A servo motor is

an electromechanical device that produces torque and velocity based on the supplied current and

voltage. A servo motor works as part of a closed loop system providing torque and velocity as

command from a servo controller utilizing a feedback device to close the loop. The feedback device

supplies information such as current, velocity or position to the servo controller, which adjusts the

motor action depending on the command parameters. When taking a photo of a wild animal, have

to change the direction of the camera according to the direction of the animal.

When the signal is received to the Atmega32 microcontroller in the host, it provides a signal to the

servo motors to make the correct angle of the servo motors. To process that we use the PWM method.

Servo motor has three wires with different. The red colour wire should be connected to the power

supply. Brown colour wire connects to the Ground and the orange colour wire connects to the PWM

signal given by the Atmega32 in the host. These are the specifications of the servo motor, speed is 0.1 per second, torque is 2.5kgcm⁻¹
, weight is 14.7 g and operating voltage is 4.8V to 6V.

### 5.5 Siren

The siren is used to protect the camera stand. When the wild animals come to attack the camera

stand, then sound the siren to run off the animals. The specifications of the siren are the operating

maximum voltage is 12V, operating maximum current is 6A, sound intensity is 112 -116 decibels,

and the speed is 1000 rpm.

### 5.6 RF Receiver and Transmitter

In this project there is a 433 MHz RF module to maintain communication between the remote

controller and the host. RF module, as the name suggests, uses radio frequency to send signals. These

signals are transmitted at a particular frequency and a baud rate. A receiver can receive these signals

only if it is configured for that frequency. The transmitter module takes serial input and transmits

these signals through RF.

The transmitter module consists of four pins namely Vcc, Ground, ATAD, and optional ANT pin as

shown. The Vcc pin has a wide range of input voltage from 3V to 12V. The transmitter consumes a

minimum current of 9mA and can go as high as 40mA during transmission. The ATAD pin is the data

pin to transmit the signal. This signal modulated and then sent on air at a frequency of 433MHz.

This module has an antenna pin which helps to connect the external wire to extend the range up to

100 meters. The size of the antenna will depend on the operating frequency.

The RF transmitter receives serial data and transmits it wirelessly through its RF antenna. The

transmission occurs at the rate of 1 Kbps to 10 Kbps.

RF receiver gets signal from the RF transmitter and gives data to the microcontroller. The receiver

module receives the data in the form of a signal and sends it to the data pin. The data received by

the module is always in an encoded form which can be decoded by using the microcontroller.

Receiver operating voltage is 3V to 12V. Receiver operating current is 5.5mA. And the operating

frequency is 433 MHz. There are five pins such that Vcc pin, GND pin, two Data pins and antenna

pin.

### 5.7 Gear motor

A gear motor is an all-in-one combination of a motor and gearbox. The addition of a gear head to a

motor reduces the speed while increasing the torque output. The most important parameters

regarding gear motors are speed (rpm), torque and efficiency. To select the most suitable gear motor

load, speed and torque required for the application have to be measured correctly. Most DC motors

can be complemented with unique gearheads.

By considering all these features in the gear motor, it’s better to use that type of motor for the wheels

of the camera holder. [2]

### 5.8 Ultrasonic sensor

An ultrasonic sensor is an electronic device which measures the distance to an object by emitting an

ultrasonic sound wave and converts the reflected sound into an electrical signal. Ultrasonic waves

travel faster than the speed of audible sound. Ultrasonic sensors have two parts as the transmitter

and receiver. Transmitter sends an ultrasonic sound wave and then the receiver receives that wave

and calculate the time took to come back to the receiver. And using these data, ultrasonic sensor

calculates the distance which has to that particular object. This is the way how the ultrasonic sensor

works.

By considering all these features of the ultrasonic sensor it can be used to detect obstacles.[7]

5.9 4x4 Keypad

The working voltage of the keypad is 5V. This consists of four rows and four columns and due to

that there are sixteen buttons too. Keypad is used to take GPS coordinates as the user inputs from

the user.

### 5.10 NEO -6M GPS module

The GPS module uses the USART technology to communicate with the microcontroller. And when

taking the specifications of the GPS module, the operating voltage lies between 2.7V to 3.6V. In the

GPS module, there is a GPS antenna to take GPS signals through Radio Frequency which are sent

from the GPS satellites. Its serial baud rate lies between 4800 bits per second to two lakhs thirty

thousand four hundred bits per second. But the default serial baud rate is nine thousand six hundred.

The max supply current for this module is 67 mA.

When taking the pin configuration of the GPS module, there are 4 pins. Vcc pin is for power supply

and GND pin is used to ground the GPS module. TXD pin is for the transmission of data and the

RXD pin is for the receiving of data. In this project, the only target is to transfer data from the GPS

module to the Atmega32 chip, and therefore it is only needed to connect the TXD pin of the GPS module with the atmega32 RXD pin. RXD pin is the 14th pin. This is all about the pin configuration

of the GPS module.

### 5.11 Compass sensor

For the GPS location guiding algorithm, identifying the current facing direction of the camera stand

is a must. The module used is the HMC5883L magnetometer module. This uses the I2C protocol for

communication with the Atmega32 microcontroller. According to the documentation, the supply

voltage for the magnetometer module lies between 2.7 V to 6.5 V. The max voltage is 6.5 V. The

frequency to pass serial data is up to 400kHz and the operating temperature is between -22 to 185

Fahrenheit. The pin configuration is that there are 5 pins in the magnetometer module. The Vcc pin

takes power to the module, and the GND pin is to ground. SCL is the serial clock pin, and the SDA

is the serial data pin. DRDY is the data-ready interrupt pin.

### 6 Previous Action Plan

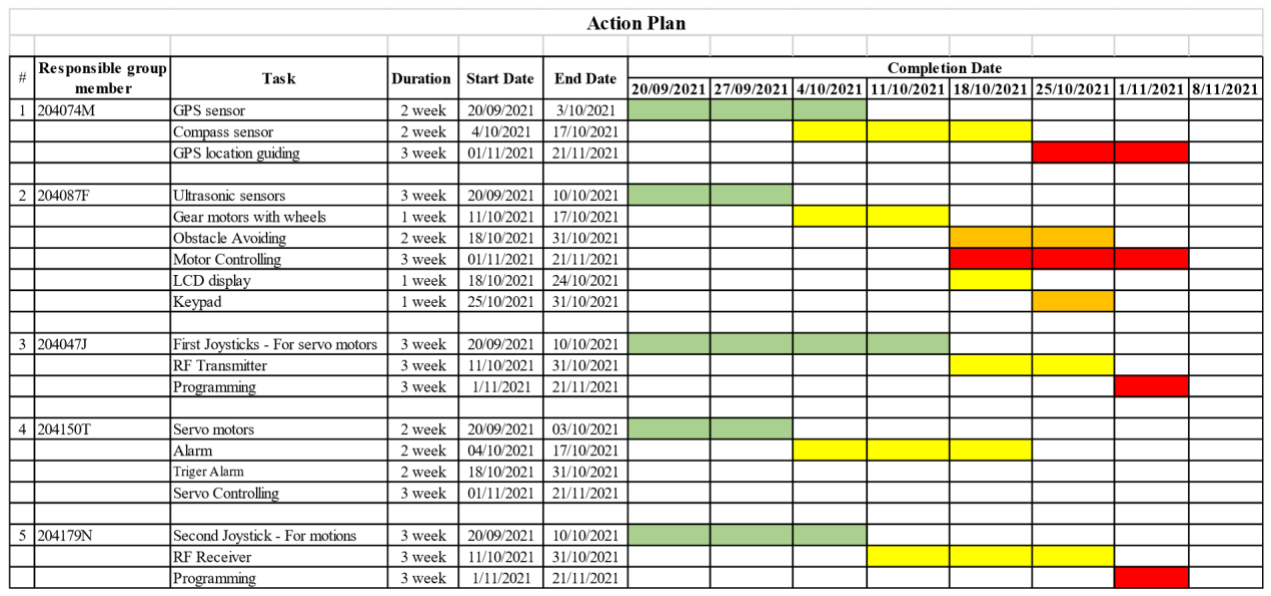
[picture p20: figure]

### 7 Action Plan for Remaining Work

Action Plan

| Responsible group member | Task | Duration | Start Date | End Date | Completion Date
31/12/2021 | 31/1/2022 | 1/2/2022 | 1/3/2022 | 1/4/2022 | 9/5/2022
1 | 204074M | Compass sensor | 1 month | 31/12/2021 | 31/1/2022
| | GPS location guiding | 1 month | 1/2/2022 | 1/3/2022
| | Test and implementation | 2 months | 2/3/2022 | 9/5/2022
2 | 204087F | Obstacle Avoiding | 1 month | 31/12/2021 | 31/1/2022
| | Motor Controlling | 1 month | 1/2/2022 | 1/3/2022
| | Test and implementation | 2 months | 2/3/2022 | 9/5/2022
3 | 204047J | First Joysticks - For servo motors | 1 month | 31/12/2021 | 31/1/2022
| | RF Transmitter | 1 month | 1/2/2022 | 1/3/2022
| | Test and implementation | 2 months | 2/3/2022 | 9/5/2022
4 | 204150T | Servo motors | 1 month | 31/12/2021 | 31/1/2022
| | Test and implementation | 1 month | 1/2/2022 | 1/3/2022
| | Trigger Alarm | 1 month | 2/3/2022 | 1/4/2022
| | Servo Controlling | 1 month | 2/4/2022 | 9/5/2022
5 | 204179N | Second Joystick - For motions | 1 month | 31/12/2021 | 31/1/2022
| | RF Receiver | 1 month | 1/2/2022 | 1/3/2022
| | Test and implementation | 2 months | 2/3/2022 | 9/5/2022

Appendix A

### 8 Cost Estimation and Expenditure so far

Component | Unit Price | Quantity | Price (LKR)
68mm RC Car Tire Wheel | Rs. 300.00 | 4 | Rs. 1,200.00
Liquid Crystal 16x2 Display Module | Rs. 300.00 | 1 | Rs. 300.00
2 Pin Switch | Rs. 15.00 | 2 | Rs. 30.00
Thumb Joystick Module | Rs. 150.00 | 2 | Rs. 300.00
RF 433MHz Transmitter/Receiver | Rs. 200.00 | 1 | Rs. 200.00
GY-271 Electronic Triple Axis Compass Module | Rs. 700.00 | 1 | Rs. 700.00
Membrane Keypad - 16 Key | Rs. 180.00 | 1 | Rs. 180.00
HC-SR04 Ultrasonic Sensor Module | Rs. 200.00 | 6 | Rs. 1,200.00
NEO-6M GPS Module | Rs. 1,850.00 | 1 | Rs. 1,850.00
L298N DC Motor Driver Module | Rs. 350.00 | 2 | Rs. 700.00
Servo Motor | Rs. 750.00 | 1 | Rs. 750.00
Atmega32 Microcontroller | Rs. 550.00 | 2 | Rs. 1,100.00
11.1V 2200mAh 3S 25C Li-Po Battery | Rs. 2,800.00 | 1 | Rs. 2,800.00
12V 2000mAh Li-Po Battery | Rs. 1,750.00 | 1 | Rs. 1,750.00
DC Gear Motor 12v 180 RPM | Rs. 950.00 | 4 | Rs. 3,800.00
Total | | | Rs. 16,860.00

[4],[5]

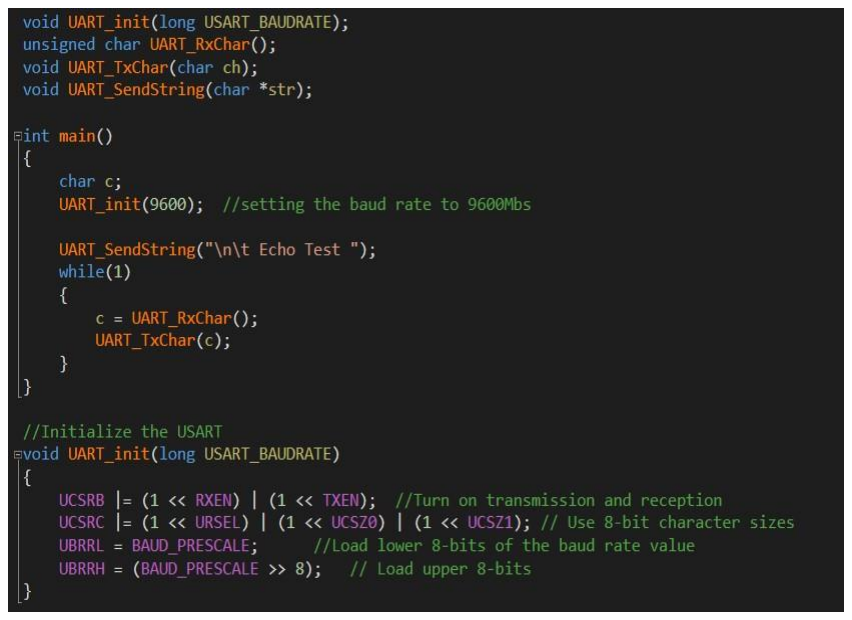
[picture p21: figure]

14

Appendix B

### 9 Individual Contribution to the Project

### 9.1 P.A.U.D. Herath - 204074M

I studied about the GPS module. Studied about the way how the GPS signals generate, and the way

GPS works. Learned about the theory regarding the USART communication. Understood the theory

behind the multiplexer to connect the GPS module and the compass sensor module.

### 9.1.1 GPS module (NEO-6M)

The GPS module has a GPS antenna, battery, an EEPROM and a position fix LED indicator. The

pins in the NEO-6M are Vcc, Tx, Rx and GND. Understood that the D0 and D1 pins must be used

to take the serial data using the GPS module. Specifications are that the operating voltage is 2.7V -

3.6V. The serial baud rate lies between 4800 and 230400. The default baud rate is 9600. Theoperating

current of the NEO-6M GPS module is 45mA.

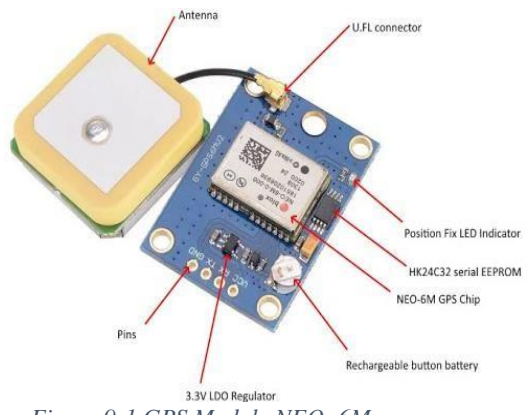
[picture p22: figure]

### 9.1.2 Multiplexer

When taking the inputs related to the GPS module and the

receiver, I had to use the same pins D0 and D1. Therefore, I

used a multiplexer to carry this out.

### 9.1.3 USART communication

To take the serial inputs from the GPS module, I used the

USART method.

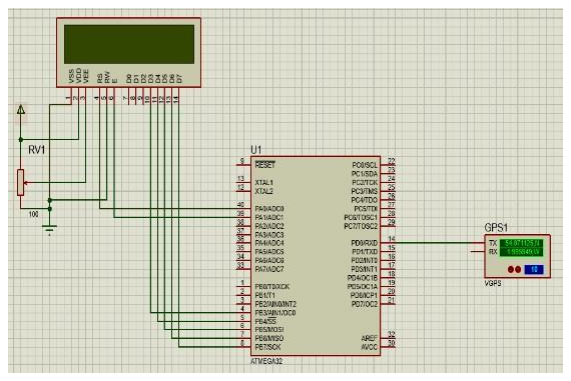
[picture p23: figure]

Figure 9-2 GPS Module Proteus Schematic View

Figure 9-3 USART Sample Code

Figure 9-1 GPS Module NEO -6M

15

### 9.2 P.H.P. Jayathilaka 204087F

I have studied about ultrasonic sensors, display, keypad, ADC, PWM. I have started studying about

USART. Also, started to study interfacing components with the ATmega32 microcontroller and how

to connect components to the microcontroller.

### 9.2.1 Ultrasonic sensor (HC-SR04)

I am using 6 ultrasonic sensors to avoid obstacles. There are 4 pins in the ultrasonic sensor. (VCC,

Trig Pin, Echo Pin, GND)

The working power of the ultrasonic sensor is DC 5V and operating current 15mA. The working

frequency is 40Hz, accurate range is 2cm – 40cm, the measuring angle is 15 degrees, trigger input

signal is 10µS TTL pulse echo output signal input TTL lever signal and the range in proportion.

### 9.2.2 Gear Motors

Due to lack of eight PWM pins for four motors, I had to couple motors as left and right. Then needed

PWM pins reduced to four. Furthermore, I used only one PWM pin and a digital pin per side. It is

configured by code.

The working voltage is 12V DC. Speed is 180 RPM.

It is a high torque motor and using L298NH – bridge

motor drive.

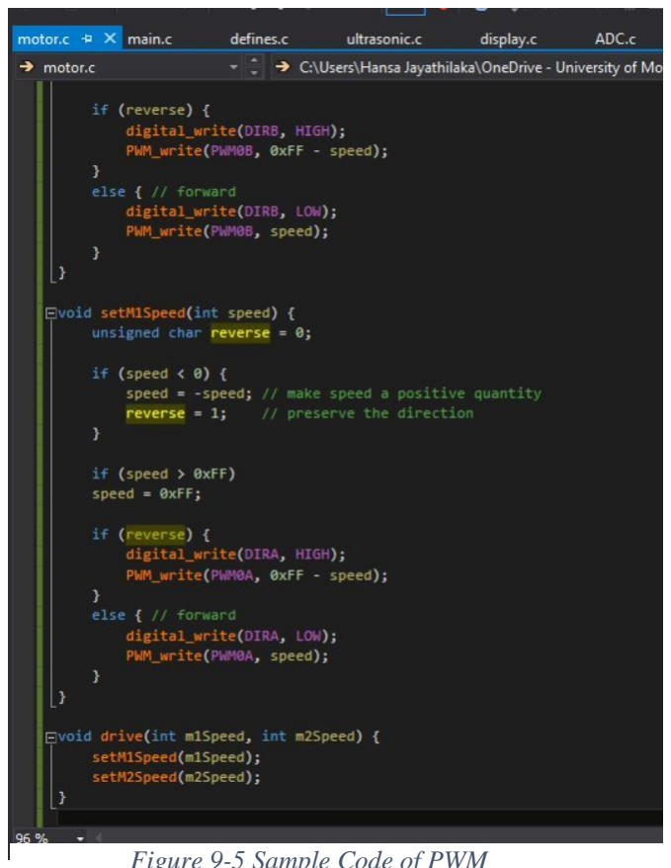
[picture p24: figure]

Figure 9-4 Sample Code of Ultrasonic Sensor | Figure 9-5 Sample Code of PWM


16

### 9.3 D.M.B.M. Dissanayake - 204047J

I have studied about Joystick, RF Transmitter and ADC. I have started to study interfacing

components with the ATmega32 microcontroller and how to connect components to the

microcontroller.

In our project, I used a joystick to get inputs related to the angle of servo motors. The

microcontroller of the remote gets analog inputs from this joystick. We need knowledge about

ADC on AVR ATmega32 to process that analog signal. To get this analog input, I had to use

A0 pin in the ATmega32 microcontroller. Furthermore, I used a 433 MHz RF transmitter to

transmit the above-processed data from the microcontroller.


### 9.3.1 Thumb Joystick

There are 5 pins in the joystick module. There are VCC, GND,

VRx, VRy, SW.

The operating voltage is 5V. Internal potentiometer value is 10kΩ

and the operating Temperature is 0 to 70 C֩.

There is no joystick module in proteus. Therefore, I used a

variable resistor to connect with the microcontroller.

Figure 9-7 Use Variable Resister for Joystick


Figure 9-8 ADC configuration and Read

Figure 9-6 Thumb Joystick Physical View


17

### 9.4 S.P.S.N. Pathirana 204150T

As a member of our group, I have to work with a servo motor and a siren. I studied about the servo

motor, and the siren. Then, I selected a suitable type of servo motor and a siren. After that, I started

to learn about how they are working and interfacing with Atmega32 microcontroller.

In this project, servo motor is used to change the vertical angle of the camera, according to signal

of the joystick.

### 9.4.1 Servo Motors

These are the specifications of servo motor: The speed of the

servo motor is 0.1 per second. The torque is 2.5 kg/cm. The

weight is 14.7g and the voltage is 4.8V – 6V.

### 9.4.2 Siren

We used a siren to protect the camera stand. When the wild

animals come to attack the camera stand, we just sound the siren

to run off the animals. The siren sounds according to the signal

given by the siren button in the remote controller.

Figure 9-9 Motor Controlling Code

These are the specifications of the siren, operating maximum

voltage is 12V, operating maximum current is 6 A, sound intensity is 112 -116 decibels, and the

speed is 1000 rpm.


Figure 9-12 Physical View of Siren

Figure 9-10 Sample Code of Servo Motors

Figure 9-11 Siren Proteus schematic view

18

### 9.5 A.M.D.B. Rathnayaka 204179N

I studied about the joystick, RF receiver, ADC Technology and started to learn about how the

components are working and interfacing with ATmega32 microcontroller. In our project, I have to

give inputs to the ATmega32 microcontroller of the remote from the joystick. Moreover, it gives


inputs to the microcontroller of the host from the RF receiver.

9.5.1 433 MHz Receiver

Receiver uses the USART communication to communicate

with the Atmega32 microcontroller of the host. The operating

frequency is 433 MHz, the operating voltage is 5V and the

supply current is 3.5 mA.

### 9.5.2 Thumb Joystick

There are 5 pins in the joystick module. And the pins in this module are VCC, GND, VRx, VRy,

SW. The Operating Voltage is 5V. The Internal potentiometer value is 10kΩ and the operating

temperature is 0 to 70 C֩. There is no joystick module in proteus. Therefore, I used two variable

resistors to connect with the microcontroller.

Figure 9-13 RF Receiver Physical view


Figure 9-14 ADC initializing code

19

Appendix C

References

[1] A. Duke, “Hiker photographs bear just before fatal grizzly attack,” CNN, 26-Aug-2012.
[2] "DC Motor & DC Gear Motor Basics | ISL Products International Ltd.", ISL Products
International, 2022. [Online]. Available: https://islproducts.com/design-note/dc-motor-dc-gear-motor-basics/.
[3] J. Dempsey, “Introduction to wildlife photography: A guide for beginners,” Phototraces.com, 03-Jan-2020. [Online]. Available:

https://www.phototraces.com/b/wildlife-photography/.

[4] M. Gallucci, “These robots are transforming how we see wildlife,” Mashable, 12-Jan2017. [Online]. Available: https://mashable.com/article/robots-wildlife-photography.
[5] “Microchip.lk – one stop for all your electronics…,” Microchip.lk. [Online]. Available: https://microchip.lk/.
[6] “TRONIC.LK,” Lankatronics.com. [Online]. Available: https://lankatronics.com/.
[7] "What is an Ultrasonic Sensor?", Fierce Electronics, 2022. [Online]. Available: https://www.fierceelectronics.com/sensors/what-ultrasonic-sensor.

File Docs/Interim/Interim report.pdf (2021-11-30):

## Faculty of Information Technology

## Automated Camera Stand

Group 47

P.A.U.D. Herath | 204074M
P.H.P. Jayathilaka | 204087F
D.M.B.M. Dissanayake | 204047J
S.P.S.N. Pathirana | 204150T
A.M.D.B. Rathnayaka | 204179N
Supervisor’s Name: | Mr. B.H. Sudantha
| Dean/Senior Lecturer
| Faculty of Information Technology
Signature of Supervisor: |

Date of Submission: 24/09/2021

Ms. Chanduni Gamage
Lecturer
Dept. of Information Technology

i

Table of Content

ii

Table of Figures

iii

Introduction

Wildlife photography is a popular category of photography, done by beginners, enthusiasts,

and professionals. When taken technically, it involves capturing any type of animal, from birds

to insects to butterflies to mammals. But wildlife photographers most commonly take photos

of mammals, reptiles, amphibians, and birds. Wildlife photography is a loosely defined

profession that demands a passion for nature and art. These photographers make a career of

traveling to remote areas and taking pictures of wild animals and natural scenery with a risk.[01]

Wildlife photographers are some of the world’s most valued professionals. According to the

U.S. Bureau of Labor Statistics, the average annual wage of most wildlife photographers was

$50,290 per year, or $24.18 per hour, as of May 2020. So, this is a higher-paying job. Due to

this reason, many new photographers have come to this field. And most wildlife photographers

are freelancers. The amount of money that a freelance wildlife photographer makes is largely

determined by his talent and ability to get decent-paying work. From all these things it is crystal

clear that wildlife photography is one of the best careers in the world.

Wildlife photography is one of the most dangerous professions in the world. The following

instances are examples of the dangerous which happen for wildlife photographers. One such

incident happened in May of 2000 when a female wildlife photographer was attacked and

partially eaten by a 112-pound female black bear in Tennessee. Last year in Colorado a wildlife

biologist and photographer, Tom Mussel, got too close to a cow elk and her calf, and he was

attacked when he stumbled as he tried to escape the charging cow. Elk and deer will attack

humans when they feel cornered or threatened. A southern California man killed by a grizzly

bear in Alaska's backcountry was shooting photos of the animal that killed him just moments

before the attack, a National Park Service official said Sunday. The bear that killed Richard

White, 49, was still with his body when rangers found him in Danail National Park, the official

said. Photographs found in his camera revealed that White was watching the bear for at least

eight minutes near a river before the attack [02].

From our project, we mainly focused on avoiding the danger for the wildlife photographer and

the safety of the camera. In this period many wildlife photographers are dying while taking

photos due to animal attacks. We are going to introduce a new device to avoid such a problem.

It is an Automated Camera Stand.

Literature Survey

In modern cameras, we have the feature to take remote photos. We call it remote photography.

Therefore, we can take pictures even if we are far from the camera. But there is no way to bring

the camera near to the animals rather than a person carrying the camera.

From the photographer’s side:

- Danger to the life of the photographer.
- Time wastage of the photographer.
- Can’t find a good angle to take a photo.
- Can’t get close enough to the animal.
- Constantly changing lighting conditions.
- No safety to the camera.
From the animal’s side:
- Animals get scared when we try to reach them.
- The behaviors of the animals may change. From the environment side:
- Bad impact on biodiversity.

Therefore, when we try to find out a solution for this we came across with some similar

projects.

Beetle cam for wildlife photography

Beetle cam has designed to take wildlife photographs.

Wildlife photographer Will Burrard-Lucas had long

wanted to add up-close-and-personal images of iconic

African animals to his portfolio. But to get those

intimate shot of lions and leopards, he would need to

crawl up right next to their sharp-toothed faces [03].


This beetle cam can move forward and backward by using the remote controller. And also,

beetle cam can be turned by using the wheels.

In our product we have all the functionalities same as the beetle cam. But there are some

uncommon functionalities rather than this beetle cam. There is a special feature that can move

the camera to the location easily by using GPS location guiding and can avoid obstacles itself.

And also, can rotate the camera vertically using the remote controller. There is a siren for the

safety of the camera.

Figure 1 Beetle cam

Aim & Objectives

Aim

This project aims to the distance photography process to make sure it is safer and effective.

Objectives

The objectives of the project are as follows,

- Rotate the camera both vertically and horizontally.
- Move the stand according to the given GPS coordinates.
- Reach the target safely.
- Protect the camera from the animals by using the alarm.
- Control the camera holder using a remote controller.


Analysis and Design

Figure 2 Block Diagram of Proposed System

Figure 3 System Diagram of Proposed System


Figure 6 Back upper 3D view | Figure 7 Front lower 3D view
Figure 4 Back lower 3D view | Figure 5 Remote controller 3D view


14

1. RF Antenna
2. Camera
3. Ultrasonic sensors
4. Wheels with gear motors
5. Universal camera mount
6. Servo motor
7. Project box
a. Atmega32 IC
b. GPS module
c. Compass sensor
d. RF receiver
8. Remote controller buttons
9. Remote controller
10. LCD Display
11. Siren
12. 4x4 Numpad
13. LCD Display
14. Joystick

Figure 8 Named Camera Stand 3D view


Figure 9 Atmega32 Pin Configuration

Testing and Implementation

In our project, there are two ATmega32 microcontrollers, one is for remote controller and the

other one is for the host (Camera stand). The microcontroller takes inputs related to motions

and angles from two joysticks. The microcontroller of the remote processes the data and

transmit from remote to host through RF (Radio Frequency) modules.

Then the microcontroller of the host gets data from the RF receiver module and GPS module

using a 2×1 multiplexer. And also, the microcontroller of the host takes inputs from ultrasonic

sensors, compass sensor and the keypad. The microcontroller of the host processes that data

and send data to the servo motors and gear motors. And also send digital signals to the display

and the siren.

ATmega32 Microcontroller

Thumb Joystick

These joystick modules are used to

control movements of the camera

stand and the vertical camera angle.

Figure 10 Atmega32 Physical view


Figure 12 Thumb Joystick | Figure 11 Read ADC value code sample


Liquid Crystal 16 × 2 Display

These LCD displays are used to show GPS coordinates and

the current remote’s configurations. By using this we can

convert camera stand more user friendly.

Figure 14 Code for LCD Display

Figure 13 LCD Display Physical view


Servo motor

This servo motor is used to change the vertical angle of the camera.

Moter drive

Motor drive is used to amplify the PWM signal from the Atmega32 and supply it to the gear motors.

Figure 15 Servo motor Physical view

Figure 16 Servo motors proteus schematic view

Figure 17 L298N IC Config for motors


Screen shots of the project.

Figure 19 Digital input and output code

Figure 18 4x4 Keypad and RF receiver Proteus view

Figure 20 Remote controller circuit Proteus schematic view

Previous Action Plan

20/09/2021 | 27/09/2021 | 4/10/2021 | 11/10/2021 | 18/10/2021 | 25/10/2021 | 1/11/2021 | 8/11/2021
1 | 204074M | GPS sensor | 2 week | 20/09/2021 | 3/10/2021
| | Compass sensor | 2 week | 4/10/2021 | 17/10/2021
| | GPS location guiding | 3 week | 01/11/2021 | 21/11/2021
2 | 204087F | Ultrasonic sensors | 3 week | 20/09/2021 | 10/10/2021
| | Gear motors with wheels | 1 week | 11/10/2021 | 17/10/2021
| | Obstacle Avoiding | 2 week | 18/10/2021 | 31/10/2021
| | Motor Controlling | 3 week | 01/11/2021 | 21/11/2021
| | LCD display | 1 week | 18/10/2021 | 24/10/2021
| | Keypad | 1 week | 25/10/2021 | 31/10/2021
3 | 204047J | First Joysticks - For servo motors | 3 week | 20/09/2021 | 10/10/2021
| | RF Transmitter | 3 week | 11/10/2021 | 31/10/2021
| | Programming | 3 week | 1/11/2021 | 21/11/2021
4 | 204150T | Servo motors | 2 week | 20/09/2021 | 03/10/2021
| | Alarm | 2 week | 04/10/2021 | 17/10/2021
| | Triger Alarm | 2 week | 18/10/2021 | 31/10/2021
| | Servo Controlling | 3 week | 01/11/2021 | 21/11/2021
5 | 204179N | Second Joystick - For motions | 3 week | 20/09/2021 | 10/10/2021
| | RF Receiver | 3 week | 11/10/2021 | 31/10/2021
| | Programming | 3 week | 1/11/2021 | 21/11/2021

Action Plan

# | Responsible group

member | Task | Duration | Start Date | End Date | Completion Date

Action Plan for Remaining Work

31/12/2021 | 31/1/2022 | 1/2/2022 | 1/3/2022 | 1/4/2022 | 9/5/2022
1 | 204074M | Compass sensor | 1 month | 31/12/2021 | 31/1/2022
| | GPS location guiding | 1 month | 1/2/2022 | 1/3/2022
| | Test and implementation | 2 month | 2/3/2022 | 9/5/2022
2 | 204087F | Obstacle Avoiding | 1 month | 31/12/2021 | 31/1/2022
| | Motor Controlling | 1 month | 1/2/2022 | 1/3/2022
| | Test and implementation | 2 month | 2/3/2022 | 9/5/2022
3 | 204047J | First Joysticks - For servo motors | 1 month | 31/12/2021 | 31/1/2022
| | RF Transmeter | 1 month | 1/2/2022 | 1/3/2022
| | Test and implementation | 2 month | 2/3/2022 | 9/5/2022
4 | 204150T | Servo motors | 1 month | 31/12/2021 | 31/1/2022
| | Test and implementation | 1 month | 1/2/2022 | 1/3/2022
| | Trigger Alarm | 1 month | 2/3/2022 | 1/4/2022
| | Servo Controlling | 1 month | 2/4/2022 | 9/5/2022
5 | 204179N | Second Joystick - For motions | 1 month | 31/12/2021 | 31/1/2022
| | RF Receiver | 1 month | 1/2/2022 | 1/3/2022
| | Test and implementation | 2 month | 2/3/2022 | 9/5/2022

Action Plan

Responsible group member | Task | Duration | Start Date | End Date | Completion Date #

References

[1] A. Duke, “Hiker photographs bear just before fatal grizzly attack,” CNN, 26-Aug-2012.
[2] J. Dempsey, “Introduction to wildlife photography: A guide for
beginners,” Phototraces.com, 03-Jan-2020. [Online]. Available: https://www.phototraces.com/b/wildlife-photography/. [Accessed: 28-Nov-2021].
[3] M. Gallucci, “These robots are transforming how we see wildlife,” Mashable, 12-Jan-2017. [Online]. Available: https://mashable.com/article/robots-wildlife-photography. [Accessed: 28-Nov-2021].
[4] “Microchip.lk – one stop for all your electronics…,” Microchip.lk. [Online]. Available: https://microchip.lk/. [Accessed: 28-Nov-2021].
[5] “TRONIC.LK,” Lankatronics.com. [Online]. Available: https://lankatronics.com/. [Accessed: 28-Nov-2021].

APPENDIX A

Cost Estimation and Expenditure so far

Component | Unit Price | Quantity | Price (LKR)
68mm RC Car Tire Wheel | Rs. 300.00 | 4 | Rs. 1,200.00
Liquid Crystal 16x2 Display Module | Rs. 300.00 | 1 | Rs. 300.00
2 Pin Switch | Rs. 15.00 | 2 | Rs. 30.00
Thumb Joystick Module | Rs. 150.00 | 2 | Rs. 300.00
RF 433MHz Transmitter/Receiver | Rs. 200.00 | 1 | Rs. 200.00
GY-271 Electronic Triple Axis Compass Module | Rs. 700.00 | 1 | Rs. 700.00
Membrane Keypad - 16 Key | Rs. 180.00 | 1 | Rs. 180.00
HC-SR04 Ultrasonic Sensor Module | Rs. 200.00 | 6 | Rs. 1,200.00
NEO-6M GPS Module | Rs. 1,850.00 | 1 | Rs. 1,850.00
L298N DC Motor Driver Module | Rs. 350.00 | 2 | Rs. 700.00
Servo Motor | Rs. 750.00 | 1 | Rs. 750.00
Atmega32 Microcontroller | Rs. 550.00 | 2 | Rs. 1,100.00
11.1V 2200mAh 3S 25C Li-Po Battery | Rs. 2,800.00 | 1 | Rs. 2,800.00
12V 2000mAh Li-Po Battery | Rs. 1,750.00 | 1 | Rs. 1,750.00
DC Gear Motor 12v 180 RPM | Rs. 950.00 | 4 | Rs. 3,800.00
Total | | | Rs. 16,860.00

[4],[5]

APPENDIX B

Individual Contribution to the Project

P.A.U.D. Herath - 204074M

- Studied about the GPS module.
- Studied about the way how the GPS signals generate and the way of GPS working.
- Learnt about the theory regarding the USART communication.
- Understood the theory behind the multiplexer.

GPS module (NEO-6M)

The GPS module has a GPS antenna, battery, an EEPROM and a position fix LED indicator.

The pins in the NEO-6M are Vcc, Tx, Rx and GND. Understood that the D0 and D1 pins

Figure 21 GPS Module NEO-6M

must be used to take the serial data using the GPS module.

Specifications are,

- Operating Voltage: 2.7V - 3.6V
- Serial Baud Rate: 4800-230400(default 9600)
- Operating Current: 45mA

Multiplexer

When taking the inputs related to the GPS module and the

receiver, I have to use the same pins (D0, D1). Therefore, I

used a multiplexer to carry this out.

USART communication

To take the serial inputs from the GPS module, I used the USART method.


Figure 22 USART sample code


Figure 23 GPS Module Proteus Schematic view

Figure 26 Motor Controlling code

Figure 27 High torque gear motor Physical view

P.H.P. Jayathilaka 204087F

- Studied about Ultrasonic sensors
- Studied about Display, Keypad, ADC, PWM
- Started studying about USART
- Started to study interfacing components with the ATmega32 microcontroller and how

to connect components to the microcontroller.

Ultrasonic sensor (HC-SR04)


I am using 6 ultrasonic sensors to avoid obstacles. There are 4 pins in the

ultrasonic sensor. (VCC, TrigPin, EchoPin, GND)

Specifications of Ultrasonic sensor:

- Working Power: DC 5V; 15mA
- Working Frequency: 40Hz
- Accurate Range: 2cm – 40cm
- Measuring Angle: 15 degrees
- Trigger Input Signal: 10µS TTL pulse
- Echo Output Signal Input TTL lever signal and

the range in proportion

Gear Motors

Due to the lack of 8 PWM pins for four motors, I had to

couple motors as left and right. Then needed PWM pins

reduced to 4. furthermore, I used only 1 PWM pin and a

digital pin per side. It is configured by code.

Specifications of Gear motors:

- Working voltage: 12v DC
- Speed: 180RPM
- High torque motors
- Use L298N H-bridge motor drive

Figure 24 Ultrasonic sensor Physical view

Figure 25 Ultrasonic sensor Code

D.M.B.M. Dissanayake - 204047J

- Studied about Joystick and RF Transmitter
- Studied about ADC
- Started to study interfacing components with the ATmega32 microcontroller and how

to connect components to the microcontroller.

In our project, I used a joystick to get inputs related to the angle of servo motors. The

microcontroller of the remote gets analog inputs from this joystick. We need knowledge

about ADC on AVR ATmega32 to process that analog signal. To get this analog input, I had

to use A0 pin in the ATmega32 microcontroller. Furthermore, I used a 433 MHz RF

transmitter to transmit the above-processed data from the microcontroller.

Thumb Joystick

There are 5 pins in the joystick module.

VCC, GND, VRx, VRy, SW

Specifications:

- Operating Voltage: 5V
- Internal potentiometer value: 10kΩ
- Operating Temperature: 0 to 70 ֩C

Figure 28 Thumb Joystick Physical view

There is no joystick module in proteus. Therefore, I used a variable resistor to connect with

the microcontroller.


Figure 30 Use variable resister for Joystick


Figure 29 ADC configuration and read


Figure 31 Servo motor physical view

Figure 34 Siren Proteus schematic view

S.P.S.N. Pathirana 204150T

- Studied about the Servo motors
- Studied about the Siren
- Started to learn about how they are working
- Started to learn about how they are interfacing with Atmega32 microcontroller

In this project, Servo motor is used to change the angle of the camera, according to the signal

of joystick.

Servo Motor

- Speed: 0.1 s
- Torque: 2.5 kg/cm
- Weight: 14.7 g
- Voltage: 4.8v - 6v

Siren

The siren is used for protecting the camera stand from the wild animals. When they come to

attack it. The siren sounds according to the signal given by the siren button in the remote

controller.

Figure 32 Servo motor sample code

Figure 33 Servo motor Proteus schematic view

Figure 35 Siren Physical view

A.M.D.B. Rathnayaka 204179N

- Studied about the joystick
- Studied about the RF receiver
- Started to study about ADC
- Started to learn about how the components are working and interfacing with

ATmega32 microcontroller

In our project, I have to give inputs to the ATmega32 microcontroller of the remote from

joystick. Moreover, it gives inputs to the microcontroller of the host from the RF receiver.

433 MHz Receiver

Receiver uses the USART communication to communicate

with the Atmega32 microcontroller of the host.

Specifications:

- Frequency: 433 MHz
- Operating voltage: 5V
- Supply current: 3.5 mA

Thumb Joystick


There are 5 pins in the joystick module. And the pins in this module are VCC, GND, VRx,

VRy, SW.

Specifications:

- Operating Voltage: 5V
- Internal potentiometer value: 10kΩ
- Operating Temperature: 0 to 70 ֩C

Figure 36 RF Receiver Physical view


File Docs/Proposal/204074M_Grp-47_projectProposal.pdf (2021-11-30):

## Faculty Of Information Technology

## Automated Camera Stand

Group 47

P.A.U.D. Herath | 204074M
P.H.P. Jayathilaka | 204087F
D.M.B.M. Dissanayake | 204047J
S.P.S.N. Pathirana | 204150T
A.M.D.B. Rathnayaka | 204179N
Supervisor’s Name: | Mr. B.H. Sudantha Dean/Senor Lecturer Faculty of Information Technology
| Ms. Chanduni Gamage Lecturer Dept. Of Information Technology
Date of Submission: | 24/09/2021

Signature of Supervisor:

Table of Content

Introduction

1

Problem In Brief

2

Aim & Objectives

3

Project Aim

3

Project Objectives

3

Proposed Solution

4

Block Diagram

5

Resource Requirement

5

Action Plan (Appendix)

6

References

7

Introduction

Wildlife photography is a popular category of photography, done by beginners, enthusiasts, and professionals. When taken technically, it involves shooting any type of animal. From birds to insects to butterflies to mammals. But wildlife photographers most commonly take photos of mammals, reptiles, amphibians, and birds. Wildlife photography is a loosely defined profession that demands a passion for nature and art. These photographers make a career of traveling to remote areas and taking pictures of wild animals and natural scenery with a risk.

Wildlife photographers are some of the world’s most valued professionals. According to the U.S. Bureau of Labor Statistics, the average annual wage of most wildlife photographers was $50,290 per year, or $24.18 per hour, as of May 2020. So, this is a higher-paying job. Due to this reason, many new photographers have come to this field. And most wildlife photographers are freelancers. The amount of money that a freelance wildlife photographer makes is largely determined by his talent and ability to get decent-paying work. From all these things it is crystal clear that wildlife photography is one of the best careers in the world.

Wildlife photography is one of the most dangerous professions in the world. The following instances are examples of the dangerous which happen for wildlife photographers. One such incident happened in May of 2000 when a female wildlife photographer was attacked and partially eaten by a 112-pound female black bear in Tennessee. Last year in Colorado a wildlife biologist and photographer, Tom Mussel, got too close to a cow elk and her calf, and he was attacked when he stumbled as he tried to escape the charging cow. Elk and deer will attack humans when they feel cornered or threatened. A southern California man killed by a grizzly bear in Alaska's backcountry was shooting photos of the animal that killed him just moments before the attack, a National Park Service official said Sunday. The bear that killed Richard White, 49, was still with his body when rangers found him in Danail National Park, the official said. Photographs found in his camera revealed that White was watching the bear for at least eight minutes near a river before the attack.

From our project, we mainly focused on avoiding the danger for the wildlife photographer and the safety of the camera. In this period many wildlife photographers are dying while taking photos due to animal attacks. We are going to introduce a new device to avoid such a problem. It is an Automated Camera Stand.

Problem In Brief

In modern cameras, we have the feature to take remote photos. We call it remote photography. Therefore, we can take pictures even if we are far from the camera. But there is no way to bring the camera near to the animals rather than a person carrying the camera.

❖ | From the photographer’s side: ○ Danger to the life of the photographer. ○ Time wastage of the photographer. ○ Can’t find a good angle to take a photo. ○ Can’t get close enough to the animal. ○ Constantly changing lighting conditions. ○ No safety to the camera.
❖ | From the animal’s side: ○ Animals get scared when we try to reach them. ○ The behaviors of the animals may change.
❖ | From the environment side: ○ Bad impact on biodiversity

Aim & Objectives

Project Aim

Automate the distance photography process to make sure it is safer and effective.

Project Objectives

- Rotate the camera both vertically and horizontally.
- Move the stand according to the given GPS coordinates.
- Reach the target safely.
- Protect the camera from the animals by using the alarm.
- Control the camera holder using a remote controller.

Proposed Solution

As the input, we use a Remote Controller, Keypad, GPS Sensors, Compass Sensors, and six Ultrasonic Sensors. The output devices are Gear Motors, Servo Motors, Display, and a Siren.

In these processes, the remote controller provides the motion signals to gear motors and servo motors. We use radiofrequency technology to communicate with remote controller and camera stand. And provides a signal to sound the siren when the animals come to attack the camera stand. By rotating these servo motors, we can rotate the camera 360 degrees horizontally and vertically using the remote controller. The camera stand can move forward using gear motors.

The keypad gets the GPS coordinates that need to go to a required place. To find the current location we use GPS sensors. Then the camera stand finds the current location and reaches the required place accurately. When we get GPS coordinate inputs form the user, we can see these coordinates in the LCD display. By using the compass sensor, we can take the angle which we need to implement a GPS location guiding algorithm. By using ultrasonic sensors, the camera stand can avoid obstacles and go ahead according to the given GPS coordinates. This is our overall proposed solution.

Things which we can do using the remote controller are as follows. We can rotate the camera vertically and horizontally 360 degrees. And we can move the camera using the wheels (That part can also be done using the GPS guiding method too). And the siren works only by using the remote controller.


Block Diagram


Resource Requirement

- Atmel Studio (Microcontroller Coding)
- Membrane Keypad - 16 Key
- HC-SR04 Ultrasonic Sensor Module
- NEO-6M GPS Module
- L298N DC Motor Driver Module
- Servo Motor
- Atmega32 Microcontroller
- 11.1V 2200mAh 3S 25C Li-Po Battery
- 12V 2000mAh Li-Po Battery
- 68mm RC Car Tire Wheel
- Liquid Crystal 16x2 Display Module
- 2 Pin Switch
- Thumb Joystick Module
- RF 433MHz Transmitter/Receiver
- GY-271 Electronic Triple Axis Compass Module

Action Plan (Appendix)

Responsible group member | Task | Duration | Start Date | End Date
1 | 204074M | GPS sensor | 2 week | 20/09/2021 | 3/10/2021
| | Compass sensor | 2 week | 4/10/2021 | 17/10/2021
| | LCD display | 1 week | 18/10/2021 | 24/10/2021
| | Keypad | 1 week | 25/10/2021 | 31/10/2021
| | GPS location guiding | 3 week | 01/11/2021 | 21/11/2021
2 | 204087F | Ultrasonic sensors | 3 week | 20/09/2021 | 10/10/2021
| | Gear motors with wheels | 1 week | 11/10/2021 | 17/10/2021
| | Obstacle Avoiding | 2 week | 18/10/2021 | 31/10/2021
| | Motor Controlling | 3 week | 01/11/2021 | 21/11/2021
3 | 204047J | First Joysticks - For servo motors | 3 week | 20/09/2021 | 10/10/2021
| | RF Transmitter | 3 week | 11/10/2021 | 31/10/2021
| | Programming | 3 week | 1/11/2021 | 21/11/2021
4 | 204150T | Servo motors | 2 week | 20/09/2021 | 03/10/2021
| | Alarm | 2 week | 04/10/2021 | 17/10/2021
| | Triger Alarm | 2 week | 18/10/2021 | 31/10/2021
| | Servo Controlling | 3 week | 01/11/2021 | 21/11/2021
5 | 204179N | Second Joystick - For motions | 3 week | 20/09/2021 | 10/10/2021
| | RF Receiver | 3 week | 11/10/2021 | 31/10/2021
| | Programming | 3 week | 1/11/2021 | 21/11/2021

Action Plan

Completion Date

References

[01] https://www.phototraces.com/b/wildlife-photography/
[02] https://lankatronics.com/
[03] https://microchip.lk/
[04] https://edition.cnn.com/2012/08/26/us/alaska-bear-attack/index.html

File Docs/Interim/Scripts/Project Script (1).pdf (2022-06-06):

# Presentation Script

1

st slide: Title

Good morning, madam/sir, I’m Binari Dissanayake.

In this period many wildlife photographers are facing severe threats while taking photos due to animal attacks. So, we are going to introduce a new device to avoid such kind of problem. It is Automated Camera Stand.

2

nd slide: Group Members

These are our group members.

3

rd slide: Problem In brief

Let’s go through our problem.

In modern cameras, we have the feature to take remote photos we called it remote photography. Therefore, we can take pictures even we are far from the camera. But there is no way to bring the camera near to the animals rather than a person carry the camera.

- When we analyze the problem, we found 3 main sides of this problem.
- When we take from the photographer’s side; Imagine we need to capture a very close wild animal photo, we can’t reach the animal. Because it will be very dangerous. In the past few years, many wildlife photographers have died due to animal attacks.
- We have to spend a lot of time, until the required animals come, to capture their photos.
- When the photographer needs to take a good quality photograph, taking a close correct angle is an essential thing. But the photographers can’t go near the animals to achieve those requirements. Furthermore, from time to time light conditions is constantly changed.
- From the animal’s side: If the animal is an innocent one, it does not stay until we go near them.
- When we get the environmental side: the photographer’s behavior caused to change the biodiversity.

This is our problem in brief.

4

th slide: Project Aim
Now we come to our project aim. Our aim is Automate the distance photography process to make sure it is safer and effective.

5

th slide: Objectives
When we discuss our project objectives, we mainly expect 6 objectives.
Those are ,
- Rotate the camera both vertically and horizontally,
- Move the stand according to given GPS coordinates,
- Reach the target safely,
- If an animal tries to attack the camera holder, then we can sound the siren. Like that we can ensure the safety of the camera.

- Control the camera holder using a remote controller.

6

th slide: Proposed solution

Let’s move to proposed solution.

As the input we use Remote Controller, Keypad, GPS Sensors, magnetometer module and four Ultrasonic Sensors. The output devices are gear motors, servo motors, Display and siren.

In these processes,

- The Remote Controller provides the signals related to motions Gear motors and Servo motors. We use radio frequency technology to communicate with remote controller and camera stand. And also, provides signals to sound the siren when the animals come to attack the camera stand.
- By rotating these servo motors,, we can rotate the camera 90 degrees vertically.
- The camera stand can move forward, backward and left and right .
- The keypad gets the GPS coordinates which need to go to a required place. To find the current location we use the GPS sensors. When the camera stand finds the current location and reaches the required place accurately. When we get user GPS coordinates inputs, we can see these coordinates in the LCD Display.
- By using the magnetometer module, we can take the angle from the north which we need to implement GPS location guiding algorithm.
- By using Ultrasonic Sensors, the camera stand can avoid the obstacles and go ahead.

- This is our overall proposed solution.

Thank you, I give my chance to Dasuni Rathanayake.

Thank you Binari

Lets see how this works In the real time scenario

- Capturing the amazing photographs and the behavior of the wild life is the dream of a wildlife photographer.
- So, our invention reveals the path to that amazing work.
- Lets take a scenario like this.
- Okay lets assume that we are seeing a beautiful bird is on a tree branch too much far away and we want to take a photograph of it.
- But practically there may be lots of difficulties to reach that place where the bird is. as an example, bird may be frightened and flies away.
- So that is the best time to get the usage of our invention.
- First we send our device that means the camera stand in auto mode to the desired destination very easily avoiding obstacles.
- we use GPS coordinates for ease of that process. But if the user prefers to send the camera stand manually through the remote controller it is also possible in our device.
- Now it's time to capture wildlife photographs.
- Before that, the user should change the mode to manual mode.
- And the camera should be a remote controlled camera. It is required.
- Then we can change the angle to focus the camera to the bird using the joystick in the remote controller.
- Not only that then let's assume a big animal as an example an elephant comes near to our camera stand and tries to harm it.
- Okay we can avoid that harm by using the siren. The sound of the siren is enough to chase away harmful animals.

## Upeksha

I’m Upeksha

## Circuit Diagram

In our project, the automated camera stand, mainly there are two parts. They are the Host and the remote controller. Therefore, we designed two circuit diagrams. One for the host and the other one for the remote controller. And also, there is a power circuit too. We use each ATmega32 microcontroller for the host and the remote controller.

Now let’s move to the circuit diagram of the remote controller.

## Remote

This is the circuit diagram of the remote controller. Here we have used two joysticks to give inputs to ADC pins of the microcontroller. And the LCD display is connected to SDA and SCL pins using I2C to give digital outputs. The nRF transceiver module is connected to SPI pins that facilitate serial data communication. And also, there is one switch connected to configure the mode of auto/manual and the other switch for configure the siren’s on and off status. These two switches are connected to Port D. We have supply power for each and every component by using the power supply circuit.

## Circuit Diagram (camera stand) - pins

These are the pins of different components which are connected to the atmega32 which is in the remote controller.

### Camera Stand

Now let’s move to the circuit diagram of the Camera stand. Here we have used another ATmega32 microcontroller to connect the components of the camera stand’s circuit. There is a 4x4 keypad that is connected using 8 pins of Port A. And the nRF transceiver has connected to the SS,MISO,MOSI,SCK,INT2 and PB1 pins. And the GPS module has connected to the RXD and TXD which are facilitated for serial data communication. 4 ultrasonic sensors have been connected by using one multiplexer due to the lack of pins. Trigger pins of all the four ultrasonic sensors are connected through a multiplexer to PC6. And all four echo pins are connected from the multiplexer through the INT0 pin.

We use the Magnetometer module to detect the facing direction of the camera stand according to the true North.

We connected the servo motor to the PWM pin, that means the PB3 pin. And also, 5V power supply has been supplied for each of the above components.

And also, the 4 gear motors have connected to the motor driver module and the motor driver module has connected to the PD4, PD5, PD6 and PD7 pins. 12V and 5V are supplied to the motor driver. The siren connected to the PA7 pin and 12V has been supplied for that pin.

## Circuit Diagram (camera stand) - pins

These are the pins of different components which are connected to the atmega32 in the camera stand.

I’m Sadini Pathirana,

Let’s move to the 3D Animation of the camera stand.

1st animation-this is the infront of the camera stand ,here you can see ultrasonic sensors.the red colour one is the siren.
there is a camera on the camera stand,which is connected to the servo motor.these are lcd display and the keypad.
this is the backside of the camera stand.

2nd Animation-In this video,you can see the functionality of the camera stand,
the wheels are working with the help of the gear motors.the camera changes the vertical angle with help of servo motors.

3rd Animation-In this video,you can see how the internal parts are fixed together.
This is the project box,it has magnetometer module,motor drive,atmega32 ,nRF transceiver and the GPS module

Now you can see how the camera stand avoid the obstacles.
Next you can see how the camera capture the objects by changing the vertical angle.

Resources-Software

These softwares are,
proteus -for circuit simulation
Solidworks and blender -to design the 3D diagram and animation Microchip studio-Microcontroller coding
Git -GitHub-for version controlling
KiCad - PCB layout designing

Resourse - Hardware

These are the h to use
Microcontroller - ATmega32 GPS Module
nRF transceiver
Ultrasonic sensors
Gear Motors
Servo Motor
LCD display
Motor Driver Module
Magnetometer Module
4x4 Keypad
Li-Po Batteries
Joystick Module
siren

Cost Estimation

Our expected cost estimation is nineteen thousand seven hundred and forty rupees.
These all prices of components are taken by referring Lanka tronics Pvt Ltd and microchip.lk,Tronics.lkwebsite.
It’s time to test and implement. I’ll hand over this presentation to Upeksha to carry out

## Upeksha

# Test and Implementation

In our project, there are mainly two components, and one is the remote controller, and that part is done by two members and the other part is the host and that is done by three members.

Ok, let’s go to my individual contribution. I’m Upeksha

I’m responsible for the NEO-6M GPS module and the HMC5883L Magnetometer module in our project. Therefore, I have to understand the concepts of USART and I2C protocol. Because the GPS module communicates with the microcontrollers using the USART communication and the magnetometer module communicates with the microcontroller using the I2C protocol.

GPS module

If I go through with the GPS module this uses the USART communication to communicate with the microcontroller. And when thinking about the specifications of the microcontroller, the operating voltage is 3.3V.

Its serial baud rate lies between 4800 bits per second to two lacks thirty thousand four hundred bits per second. But the default serial baud rate is nine thousand six hundred. I used that value for my coding stuff too.

The max supply current for this module is 67 mA.

When taking the pin configuration of the GPS module, there are 4 pins. Vcc pin is for power supply and GND pin is used to ground the GPS module. TXD pin is for the transmission of data and the RXD pin is for the receiving of data. In this project, I have only to transfer data from the GPS module to the Atmega32 chip, and therefore I was only needed to connect the TXD pin of the GPS module with the atmega32 RXD pin. RXD pin is the 14

th pin.
This is all about the pin configuration of the GPS module.

Internal structure of the GPS module

In the GPS module, there is a GPS antenna to take GPS signals through Radio Frequency which are sent from the GPS satellites. The SAW filter is placed in the GPS antenna. This SAW filter is known as the GPS filter too.

RF front end, short for radio frequency front end, is a generic term for all the circuitry between a receiver's antenna and the particular module.

A digital filter is a system that performs mathematical operations on a sampled, discrete-time signal to reduce or enhance certain aspects of that signal.

SRAM or static ram is use to store the gps coordinates or whatever the data temporarily inside the GPS module.

GPS engine provides superior navigation performance under dynamic conditions in areas with limited sky view like urban canyons.

The ARM7TDMI processor implements the ARMv4 instruction set. And this is a 16 bit fast ICE.

The backup RAM is a volatile memory. The backup RAM provides a limited number of bytes of RAM that are retained during the Lightning Protection Measures System.

A real-time clock (RTC) is a battery-powered clock that is included in a microchip in a computer motherboard. This microchip is usually separate from the microprocessor and other chips and is often referred to simply as "the CMOS" .

This is the internal structure of the GPS module.

From the GPS module it will transfer series of characters and when taking GPS coordinates we have to filter the correct characters which we need by using conditional statements with the help of USART communication.

Circuit Diagram

When talking about the circuit diagram. For USART communication we use four pins in the Atmega32 microcontroller. They are RX, TX, XCK and XDIR. Here RX pin is used to take inputs to the Atmega32 in the USART communication and the TX pin is used to transmit data from the Atmega32 microcontroller in the USART communication. XCK pin is used to send the clock signal and the XDIR pin is used to set the direction. When we take the Atmega32 microcontroller RXD pin is the 14

th pin. I only needed to take inputs from the GPS module and that’s why I only used RXD pin. I connected the GPS module’s TX pin to the Atmega RXD pin. Then the GPS module’s output will be taken as an input in the microcontroller. That’s how this circuit diagram works.

As the inputs for the GPS module, we only supply the power. As the outputs from the GPS module, I take the latitude and longitude values. Because we need the current location’s GPS coordinates to build our GPS location guiding algorithm.

Here I have used a 16 by 2 LCD-display module to display the latitude and longitude values that are outputted from the GPS module. That goanna bee uses for testing purposes.

Compiled Code

This is the compiled code that I used for the UART. USART stands for Universal Synchronous Asynchronous Receiver Transmitter. To do the serial communication we use USART technology. Here we do not need the Synchronous data transmission to work with the GPS module. Because we do not need the clock for taking outputs from the GPS module. And therefore, there will be no synchronous data transmission between the GPS module and the microcontroller. That’s why we can say that there is a UART communication in here.

For the UART communication, we use 5 basic registers. They are the UDR register, UCSRA register, UCSRB register, UCSRC register, and the UBRR register. Here I have used two macros to define the USART board rate and the BAUD_PRESCALE. Here first, we have to initialize the UART, it’s just like that we make the path between the GPS module and the microcontroller. For that, I wrote the function UART_init. The data are passed like characters in this communication method. And therefore, to receive a character from the USART Dara Register I wrote a function called UART_RxChar, and to transmit a character wrote a function called UART_TxChar. To send a whole string through UART I wrote the function UART_sendString.

Magnetometer module

For the GPS location guiding algorithm, we need to identify the current facing direction of the camera stand. For that, I’m using an HMC5883L magnetometer module. This uses the I2C protocol for communication with the Atmega32 microcontroller.

According to the documentation, the supply voltage for the magnetometer module is 3.6V. The frequency to pass serial data is up to 400kHz and the operating temperature is between -22 to 185 Fahrenheit. And the supply current is 2 micro Ampiers. And the power consumed by this module is 360 micro wot.

Magnetometer module pin configuration

When we think about the pin configuration there are 5 pins in the magnetometer module. The Vcc pin takes power to the module, and the GND pin is to ground. SCL is the serial clock pin, and the SDA is the serial data pin. DRDY is the data-ready interrupt pin. But I only needed the SCL and SDA pins to connect with the I2C buss.

Internal Structure Magnetometer module (HMC5883L)

Earth’s magnetic field is present in space which points towards the magnetic north. Current carrying conductor also generates a magnetic field around itself. Hence, whenever a current carrying conductor is placed in space, it experiences the effect of the earth’s magnetic field affecting the flow of the electrons through that conductor. These changes in the flow of the electrons are used for identifying the heading or direction of the magnetic field. This is the basic working principle of the magnetometer.
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

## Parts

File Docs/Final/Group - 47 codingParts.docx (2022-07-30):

IN1900 - Hardware Project

Batch 20 – IT

Group 47

2021 - 2022

# Herath P.A.U.D – 204074M

/*

* CFile1.c

*

* Created: 11/29/2021 5:49:16 AM

* Author: Upeksha Herath

*/

#include "../defines.h"

#define BAUD_PRESCALE (((F_CPU / (USART_BAUDRATE * 16UL))) - 1)

/*

To initialize the USART connection between two components

=========================================================

UCSRB register the most used bits are the RXEN and TXEN

UCSRC and the UBRRH share same address. To select the UCSRC we have to give 1 to URSEL else it will write in UBRRH register (because default value is 0).

UCSZ0 and UCSZ1 sets the frame size. We have set that to 8 bits in this function 2nd line.

*/

void UART_init(long USART_BAUDRATE) {

UCSRB |= (1 << RXEN) | (1 << TXEN); // Enable USART transmission (of transmitter) and reception (of receiver)

UCSRC |= (1 << URSEL) | (1 << UCSZ0) | (1 << UCSZ1); // Use 8-bit character sizes

UBRRL = BAUD_PRESCALE; // Load lower 8-bits of the baud rate value

UBRRH = (BAUD_PRESCALE >> 8); // Load upper 8-bits

}

/*

To receive data

===============

*/

unsigned char UART_RxChar() {

while ((UCSRA & (1 << RXC)) == 0); // Wait till data is received

return(UDR); // Return the byte

}

/*

To Transmit data

=================

*/

void UART_TxChar(char ch) {

while (! (UCSRA & (1<<UDRE))); // Wait for empty transmit buffer

UDR = ch ;

}

/*

To send String data

===================

*/

void UART_SendString(char *str) {

unsigned char j=0; //because int allocate more memory unsigned char can be used to store the int values

while (str[j]!=0) { // Send string till null

UART_TxChar(str[j]);

j++;

}

}

/*

GPS Information extraction using ATmega16/32

Author : Upeksha Herath

*/

#include "../defines.h"

#define BAUD 9600 //BAUDRATE = 9600

//This will initialize the GPS values according to the current GPS coordinates

void GPS_init() {

int flag = 0;

while (flag != 1) {

value = UART_RxChar();

if (value == '$') {

value = UART_RxChar();

if (value == 'G') {

value = UART_RxChar();

if (value == 'P') {

value = UART_RxChar();

if (value == 'G') {

value = UART_RxChar();

if (value == 'G') {

value = UART_RxChar();

if (value == 'A') {

value = UART_RxChar();

if (value == ',') {

value = UART_RxChar();

while (value != ',') {

value = UART_RxChar();

}

lati_value[0] = UART_RxChar();

value = lati_value[0];

for (int i = 1; value != ','; i++) {

lati_value[i] = UART_RxChar();

value = lati_value[i];

}

lati_dir = UART_RxChar();

value = UART_RxChar();

while (value != ',') {

value = UART_RxChar();

}

longi_value[0] = UART_RxChar();

value = longi_value[0];

for(int i = 1; value != ','; i++) {

longi_value[i] = UART_RxChar();

value = longi_value[i];

}

longi_dir = UART_RxChar();

flag = 1;

} else {

continue;

}

} else {

continue;

}

} else {

continue;

}

} else {

continue;

}

} else {

continue;

}

} else {

continue;

}

} else {

continue;

}

}

}

//give latitude value as a string

char* get_lati_str() {

return lati_value; //lati_value;

}

//give longitude value as a string

char* get_longi_str() {

return longi_value; //longi_value;

}

//give latitude value as a double

float get_lati_float() {

for (int i = 0; i < 15; i++) {

if (lati_value[i] == ',') {

lati_value[i] = '0';

}

}

float correct_lati_value = atof(lati_value) / 100;

return correct_lati_value;

}

//give longitude value as a double

float get_longi_float() {

for (int i = 0; i < 15; i++) {

if (longi_value[i] == ',') {

longi_value[i] = '0';

}

}

/*how to convert a latitude value to degrees*/

float correct_longi_value = atof(longi_value) / 100;

return correct_longi_value;

}

/* take the inputed GPS coordinate and value and compare with inputted*/

int angle_from_north(float lati_input, float longi_input) {

float dy = lati_input - get_lati_float();

float dx = cos(PI / 180 * get_lati_float()) * (longi_input - get_longi_float());

float angle = dy / dx;

int temp = angle;

return angle;

}

/*

* I2C.c

*

* Created: 5/10/2022 8:59:24 PM

* Author: Hansa Jayathilaka, Upeksha Herath

*/

#include "../defines.h"

void I2C_wait_to_process() {

while ((TWCR & (1 << TWINT)) == 0);

}

/************************************************************************/

/* Master */

/************************************************************************/

void I2C_master_init() {

TWBR = 0x62; // Baud rate is set by calculating

TWCR = (1 << TWEN); // Enable I2C

TWSR = 0x00; // Pre-scaler set to 1

}

//Start condition

void I2C_start() {

TWCR = (1 << TWINT) | (1 << TWEN) | (1 << TWSTA); //start condition

I2C_wait_to_process();

}

//I2C stop condition

void I2C_write(unsigned char x) {

TWDR = x; //Move value to I2C

TWCR = (1 << TWINT) | (1 << TWEN); //Enable I2C and clear interrupt

I2C_wait_to_process();

}

void I2C_select_slave(unsigned char address, int mode) {

I2C_write(address + mode);

}

void I2C_stop() {

TWCR = (1 << TWINT) | (1 << TWEN) | (1 << TWSTO);

// while((TWCR & (1<<TWSTO)) == 1); // No need to wait

}

void I2C_master_write_buffer(unsigned char address, char* buffer, int length) {

I2C_start();

I2C_select_slave(address, WRITE);

for(char* i = buffer; i < buffer + length; i++) {

I2C_write(*i);

}

I2C_stop();

}

/************************************************************************/

/* End Master */

/************************************************************************/

/************************************************************************/

/* Slave */

/************************************************************************/

void I2C_slave_init(unsigned char address) {

TWAR = address; // Set slave address

}

void I2C_listen(void) {

TWCR = (1 << TWEN) | (1 << TWINT) | (1 << TWEA); // Enable; Interrupt; Acknowledgment;

I2C_wait_to_process();

}

// Read byte with NACK

unsigned char I2C_read() {

TWCR = (1 << TWEN) | (1 << TWINT) | (1 << TWEA); // Enable; Interrupt; Acknowledgment;

I2C_wait_to_process();

return TWDR;

}

void I2C_slave_read_buffer(char* buffer, int length) {

I2C_listen();

for(char* i = buffer; i < buffer + length; i++) {

*i = I2C_read();

}

I2C_listen();

}

/************************************************************************/

/* End Slave */

/************************************************************************/

/*

* magnetometer.c

*

* Created: 5/20/2022 9:53:22 AM

* Author: Upeksha Herath

*/

#include "../defines.h"

/* Define declination of location from where measurement going to be done. we can get it from http://www.magnetic-declination.com */

#define Declination -0.00669

void Magneto_init() /* Magneto initialize function */

{

I2C_select_slave(0x3C, WRITE); /* Start and write SLA+W */

I2C_write(0x00); /* Write memory location address */

I2C_write(0x70); /* Configure register A as 8-average, 15 Hz default, normal measurement */

I2C_write(0xA0); /* Configure register B for gain */

I2C_write(0x00); /* Configure continuous measurement mode in mode register */

I2C_stop(); /* Stop I2C */

}

int Magneto_GetHeading()

{

int x, y, z;

double Heading;

I2C_start();

I2C_select_slave(0x3C, WRITE);

I2C_write(0x3C); /* Start and wait for acknowledgment */

I2C_write(0x03); /* Write memory location address */

/* Read 16 bit x,y,z value (2's complement form) */

x = (((int)I2C_read()<<8) | (int)I2C_read());

z = (((int)I2C_read()<<8) | (int)I2C_read());

y = (((int)I2C_read()<<8) | (int)I2C_read());

I2C_stop(); /* Stop I2C */

Heading = atan2((double)y,(double)x) + Declination;

if (Heading>2*PI) /* Due to declination check for >360 degree */

Heading = Heading - 2*PI;

if (Heading<0) /* Check for sign */

Heading = Heading + 2*PI;

return (Heading* 180 / PI);/* Convert into angle and return */

}

# Dissanayake D.M.B.M – 204047J

/*

* joystick.c

*

* Created: 5/18/2022 7:53:34 PM

* Author: Dasuni Rathnayaka, Binari Dissanayake

*/

#include "../defines.h"

void joystick_init(void) {

pin_mode(A0, INPUT); // Up / Down

pin_mode(A1, INPUT); // Left / Right

pin_mode(A2, INPUT); // Forward / Backward

}

/*

* Get angle for camera

*/

uint8_t get_joystick_up_down() {

return ADC_read(A0);

}

/*

* Get turn

*/

uint8_t get_joystick_left_right() {

return ADC_read(A1);

}

/*

* Get forward and backward speed

*/

uint8_t get_joystick_forward_backward() {

return ADC_read(A2);

}

/* nrf24101_reg.h

*

* Created: 5/12/2022 7:53:26 AM

* Author: Binari Dissanayake, Dasuni Rathnayaka

*/

/**

* Register definitions with bit definitions for the nRF24L01

*

*/

#ifndef NRF24L01_REG_H

#define NRF24L01_REG_H

/* nRF24L01 Instruction Definitions */

#define WRITE_REG 0x20

#define RD_RX_PLOAD_W 0x60

#define RD_RX_PLOAD 0x61

#define WR_TX_PLOAD 0xA0

#define WR_ACK_PLOAD 0xA8

#define WR_NAC_TX_PLOAD 0xB0

#define FLUSH_TX 0xE1

#define FLUSH_RX 0xE2

#define REUSE_TX_PL 0xE3

#define LOCK_UNLOCK 0x50

#define NOP 0xFF

/* nRF24L01 Register address definitions */

#define CONFIG 0x00

#define EN_AA 0x01

#define EN_RXADDR 0x02

#define SETUP_AW 0x03

#define SETUP_RETR 0x04

#define RF_CH 0x05

#define RF_SETUP 0x06

#define STATUS 0x07

#define OBSERVE_TX 0x08

#define CD 0x09

#define RX_ADDR_P0 0x0A

#define RX_ADDR_P1 0x0B

#define RX_ADDR_P2 0x0C

#define RX_ADDR_P3 0x0D

#define RX_ADDR_P4 0x0E

#define RX_ADDR_P5 0x0F

#define TX_ADDR 0x10

#define RX_PW_P0 0x11

#define RX_PW_P1 0x12

#define RX_PW_P2 0x13

#define RX_PW_P3 0x14

#define RX_PW_P4 0x15

#define RX_PW_P5 0x16

#define FIFO_STATUS 0x17

#define DYNPD 0x1C

#define FEATURE 0x1D

/********** Register bit definitions **************/

/* STATUS Reg bits */

#define STAT_MAX_RT (1 << 4)

#define STAT_TX_DS (1 << 5)

#define STAT_RX_DR (1 << 6)

#define STAT_RX_P_NO (7 << 1)

#define STAT_TX_FULL (1 << 0)

/* CONFIG register bits */

#define CONFIG_RX_DR (1 << 6)

#define CONFIG_TX_DS (1 << 5)

#define CONFIG_MAX_RT (1 << 4)

#define CONFIG_EN_CRC (1 << 3)

#define CONFIG_CRCO (1 << 2)

#define CONFIG_PWR_UP (1 << 1)

#define CONFIG_PRIM_RX (1 << 0)

/* RF_SETUP register bit definitions */

#define RF_CONT_WAVE (1 << 7)

#define RF_DR_LOW (1 << 5)

#define RF_PLL_LOCK (1 << 4)

#define RF_DR_HIGH (1 << 3)

#define RF_PWR1 (1 << 2)

#define RF_PWR0 (1 << 1)

#define RF_LNA (1 << 0)

/* FIFO_STATUS register bits */

#define TX_REUSE (1 << 6)

#define TX_FIFO_FULL (1 << 5)

#define TX_EMPTY (1 << 4)

#define RX_FULL (1 << 1)

#define RX_EMPTY (1 << 0)

/* Operation mode */

typedef enum {

NRF_MODE_PTX = 0,

NRF_MODE_PRX

} nrf_opmode_t;

/* Output power modes */

typedef enum {

NRF_PWR_18DBM = 0,

NRF_PWR_12DBM,

NRF_PWR_6DBM,

NRF_PWR_0DBM

} nrf_power_t;

/* data rate */

typedef enum {

NRF_RATE_250KBPS = 0,

NRF_RATE_1MBPS,

NRF_RATE_2MBPS

} nrf_datarate_t;

/* pipe numbers */

typedef enum {

NRF_PIPE0 = 0,

NRF_PIPE1,

NRF_PIPE2,

NRF_PIPE3,

NRF_PIPE4,

NRF_PIPE5,

NRF_TX_PIPE,

NRF_TX_PLOAD, /* for writing tx payload */

NRF_TX_PLOAD_NOACK, /* for tx payload with no ACK */

NRF_RX_PLOAD, /* for reading rx payload */

NRF_PIPE_ALL = 0xFF

} nrf_pipe_t;

#endif // NRF24L01_REG_H

/*

* NRF24L01+ library header file

* nrf24101.h

*

* Created: 5/11/2022 6:53:26 PM

* Author: Binari Dissanayake, Dasuni Rathnayaka

*

*

*/

#include "../../defines.h"

#ifndef NRF24L01_H

#define NRF24L01_H

/* Public functions */

void nrf_init(nrf_opmode_t mode, uint8_t *address);

uint8_t nrf_transmit_packet(uint8_t *packet, uint8_t length);

uint8_t nrf_receive_packet(uint8_t *buf, uint8_t *length);

void nrf_set_ack_payload(uint8_t pipe, uint8_t *buf, uint8_t length);

void nrf_tx_data(uint8_t up_down, uint8_t left_right, uint8_t forward_backward, uint8_t siren, uint8_t auto_manual_mode);

int nrf_rx_data(uint8_t *up_down, uint8_t *left_right, uint8_t *forward_backward, uint8_t *siren, uint8_t *auto_manual_mode);

#endif // NRF24L01_H

/*

* ultrasonic.c

*

* Created: 11/1/2021 10:49:53 PM

* Author: Binari Dissanayake

*/

#include "../defines.h"

#define trigPin C6

#define echoPin D6

#define mux1 C4

#define mux2 C5

int TimerOverflow = 0;

void ultrazonic_init() {

pin_mode(trigPin, OUTPUT);

pin_mode(echoPin, INPUT_PULLUP);

pin_mode(mux1, OUTPUT);

pin_mode(mux2, OUTPUT);

}

double ultrazonic_distance(void) {

char string[10];

long count;

double distance;

uint8_t _TCCR1B = TCCR1B;

uint8_t _TCCR1A = TCCR1A;

uint8_t _TIMSK = TIMSK;

sei(); /* Enable global interrupt */

TIMSK = (1 << TOIE1); /* Enable Timer1 overflow interrupts */

TCCR1A = 0; /* Set all bit to zero Normal operation */

/* Give 10us trigger pulse on trig. pin to HC-SR04 */

digital_write(C6, HIGH);

_delay_us(10);

digital_write(C6, LOW);

TCNT1 = 0; /* Clear Timer counter */

TCCR1B = 0x41; /* Capture on rising edge, No prescaler*/

TIFR = 1<<ICF1; /* Clear ICP flag (Input Capture flag) */

TIFR = 1<<TOV1; /* Clear Timer Overflow flag */

/*Calculate width of Echo by Input Capture (ICP) */

while ((TIFR & (1 << ICF1)) == 0);/* Wait for rising edge */

TCNT1 = 0; /* Clear Timer counter */

TCCR1B = 0x01; /* Capture on falling edge, No prescaler */

TIFR = 1<<ICF1; /* Clear ICP flag (Input Capture flag) */

TIFR = 1<<TOV1; /* Clear Timer Overflow flag */

TimerOverflow = 0;/* Clear Timer overflow count */

while ((TIFR & (1 << ICF1)) == 0);/* Wait for falling edge */

count = ICR1 + (65535 * TimerOverflow); /* Take count */

/* 8MHz Timer freq, sound speed =343 m/s */

distance = (double)count / 466.47;

TCCR1B = _TCCR1B;

TCCR1A = _TCCR1A;

TIMSK = _TIMSK;

// PWM_init();

return distance;

}

int ultrazonic_error() {

digital_write(mux1, LOW);

digital_write(mux2, LOW);

double left = ultrazonic_distance();

digital_write(mux1, LOW);

digital_write(mux2, HIGH);

double right = ultrazonic_distance();

char string[16];

LCD_clear();

LCD_line_1();

dtostrf(left, 2, 2, string);/* distance to string */

strcat(string, " cm "); /* Concat unit i.e.cm */

LCD_msg(string);

dtostrf(right, 2, 2, string);/* distance to string */

strcat(string, " cm"); /* Concat unit i.e.cm */

LCD_line_2();

LCD_msg(string);

digital_write(mux1, LOW);

digital_write(mux2, LOW);

int error = right - left;

return error;

}

ISR(TIMER1_OVF_vect)

{ TimerOverflow++; /* Increment Timer Overflow count */ }

# Rathnayaka A.M.D.B – 204179N

/*

* joystick.c

*

* Created: 5/18/2022 7:53:34 PM

* Author: Dasuni Rathnayaka, Binari Dissanayake

*/

#include "../defines.h"

void joystick_init(void) {

pin_mode(A0, INPUT); // Up / Down

pin_mode(A1, INPUT); // Left / Right

pin_mode(A2, INPUT); // Forward / Backward

}

/*

* Get angle for camera

*/

uint8_t get_joystick_up_down() {

return ADC_read(A0);

}

/*

* Get turn

*/

uint8_t get_joystick_left_right() {

return ADC_read(A1);

}

/*

* Get forward and backward speed

*/

uint8_t get_joystick_forward_backward() {

return ADC_read(A2);

}

/* nrf24101_reg.h

*

* Created: 5/12/2022 7:53:26 AM

* Author: Binari Dissanayake, Dasuni Rathnayaka

*/

/**

* Register definitions with bit definitions for the nRF24L01

*

*/

#ifndef NRF24L01_REG_H

#define NRF24L01_REG_H

/* nRF24L01 Instruction Definitions */

#define WRITE_REG 0x20

#define RD_RX_PLOAD_W 0x60

#define RD_RX_PLOAD 0x61

#define WR_TX_PLOAD 0xA0

#define WR_ACK_PLOAD 0xA8

#define WR_NAC_TX_PLOAD 0xB0

#define FLUSH_TX 0xE1

#define FLUSH_RX 0xE2

#define REUSE_TX_PL 0xE3

#define LOCK_UNLOCK 0x50

#define NOP 0xFF

/* nRF24L01 Register address definitions */

#define CONFIG 0x00

#define EN_AA 0x01

#define EN_RXADDR 0x02

#define SETUP_AW 0x03

#define SETUP_RETR 0x04

#define RF_CH 0x05

#define RF_SETUP 0x06

#define STATUS 0x07

#define OBSERVE_TX 0x08

#define CD 0x09

#define RX_ADDR_P0 0x0A

#define RX_ADDR_P1 0x0B

#define RX_ADDR_P2 0x0C

#define RX_ADDR_P3 0x0D

#define RX_ADDR_P4 0x0E

#define RX_ADDR_P5 0x0F

#define TX_ADDR 0x10

#define RX_PW_P0 0x11

#define RX_PW_P1 0x12

#define RX_PW_P2 0x13

#define RX_PW_P3 0x14

#define RX_PW_P4 0x15

#define RX_PW_P5 0x16

#define FIFO_STATUS 0x17

#define DYNPD 0x1C

#define FEATURE 0x1D

/********** Register bit definitions **************/

/* STATUS Reg bits */

#define STAT_MAX_RT (1 << 4)

#define STAT_TX_DS (1 << 5)

#define STAT_RX_DR (1 << 6)

#define STAT_RX_P_NO (7 << 1)

#define STAT_TX_FULL (1 << 0)

/* CONFIG register bits */

#define CONFIG_RX_DR (1 << 6)

#define CONFIG_TX_DS (1 << 5)

#define CONFIG_MAX_RT (1 << 4)

#define CONFIG_EN_CRC (1 << 3)

#define CONFIG_CRCO (1 << 2)

#define CONFIG_PWR_UP (1 << 1)

#define CONFIG_PRIM_RX (1 << 0)

/* RF_SETUP register bit definitions */

#define RF_CONT_WAVE (1 << 7)

#define RF_DR_LOW (1 << 5)

#define RF_PLL_LOCK (1 << 4)

#define RF_DR_HIGH (1 << 3)

#define RF_PWR1 (1 << 2)

#define RF_PWR0 (1 << 1)

#define RF_LNA (1 << 0)

/* FIFO_STATUS register bits */

#define TX_REUSE (1 << 6)

#define TX_FIFO_FULL (1 << 5)

#define TX_EMPTY (1 << 4)

#define RX_FULL (1 << 1)

#define RX_EMPTY (1 << 0)

/* Operation mode */

typedef enum {

NRF_MODE_PTX = 0,

NRF_MODE_PRX

} nrf_opmode_t;

/* Output power modes */

typedef enum {

NRF_PWR_18DBM = 0,

NRF_PWR_12DBM,

NRF_PWR_6DBM,

NRF_PWR_0DBM

} nrf_power_t;

/* data rate */

typedef enum {

NRF_RATE_250KBPS = 0,

NRF_RATE_1MBPS,

NRF_RATE_2MBPS

} nrf_datarate_t;

/* pipe numbers */

typedef enum {

NRF_PIPE0 = 0,

NRF_PIPE1,

NRF_PIPE2,

NRF_PIPE3,

NRF_PIPE4,

NRF_PIPE5,

NRF_TX_PIPE,

NRF_TX_PLOAD, /* for writing tx payload */

NRF_TX_PLOAD_NOACK, /* for tx payload with no ACK */

NRF_RX_PLOAD, /* for reading rx payload */

NRF_PIPE_ALL = 0xFF

} nrf_pipe_t;

#endif // NRF24L01_REG_H

/*

* NRF24L01+ library header file

* nrf24101.h

*

* Created: 5/11/2022 6:53:26 PM

* Author: Binari Dissanayake, Dasuni Rathnayaka

*

*

*/

#include "../../defines.h"

#ifndef NRF24L01_H

#define NRF24L01_H

/* Public functions */

void nrf_init(nrf_opmode_t mode, uint8_t *address);

uint8_t nrf_transmit_packet(uint8_t *packet, uint8_t length);

uint8_t nrf_receive_packet(uint8_t *buf, uint8_t *length);

void nrf_set_ack_payload(uint8_t pipe, uint8_t *buf, uint8_t length);

void nrf_tx_data(uint8_t up_down, uint8_t left_right, uint8_t forward_backward, uint8_t siren, uint8_t auto_manual_mode);

int nrf_rx_data(uint8_t *up_down, uint8_t *left_right, uint8_t *forward_backward, uint8_t *siren, uint8_t *auto_manual_mode);

#endif // NRF24L01_H

/*

* keypad.c

*

* Created: 12/4/2021 3:50:40 PM

* Author: Dasuni Rathnayaka

*/

#include "../defines.h"

#define KEY_PRT PORTA

#define KEY_DDR DDRA

#define KEY_PIN PINA

unsigned char keypad[4][4] = {

{'7','4','1',' '},

{'8','5','2','0'},

{'9','6','3','='},

{'/','*','-','+'},

};

unsigned char colloc, rowloc;

char key_char() {

while(1) {

KEY_DDR = 0xF0; /* set port direction as input-output */

KEY_PRT = 0xFF;

do

{

KEY_PRT &= 0x0F; /* mask PORT for column read only */

asm("NOP");

colloc = (KEY_PIN & 0x0F); /* read status of column */

} while(colloc != 0x0F);

do

{

do

{

_delay_ms(20); /* 20ms key debounce time */

colloc = (KEY_PIN & 0x0F); /* read status of column */

} while(colloc == 0x0F); /* check for any key press */

_delay_ms (40); /* 20 ms key debounce time */

colloc = (KEY_PIN & 0x0F);

} while(colloc == 0x0F);

/* now check for rows */

KEY_PRT = 0xEF; /* check for pressed key in 1st row */

asm("NOP");

colloc = (KEY_PIN & 0x0F);

if(colloc != 0x0F)

{

rowloc = 0;

break;

}

KEY_PRT = 0xDF; /* check for pressed key in 2nd row */

asm("NOP");

colloc = (KEY_PIN & 0x0F);

if(colloc != 0x0F)

{

rowloc = 1;

break;

}

KEY_PRT = 0xBF; /* check for pressed key in 3rd row */

asm("NOP");

colloc = (KEY_PIN & 0x0F);

if(colloc != 0x0F)

{

rowloc = 2;

break;

}

KEY_PRT = 0x7F; /* check for pressed key in 4th row */

asm("NOP");

colloc = (KEY_PIN & 0x0F);

if(colloc != 0x0F)

{

rowloc = 3;

break;

}

}

if(colloc == 0x0E)

return(keypad[rowloc][0]);

else if(colloc == 0x0D)

return(keypad[rowloc][1]);

else if(colloc == 0x0B)

return(keypad[rowloc][2]);

else

return(keypad[rowloc][3]);

}

void key_string(char buffer[], int buff) {

UART_TxChar('\n');

for(int i = 0; i < buff; i++) {

char temp = key_char();

LCD_char(temp);

UART_TxChar(temp);

if (temp == '=') {

buffer[i] = '\0';

break;

}

buffer[i] = temp;

}

}

# Pathirana S.P.S.N – 204150T

/*

* PWM.c

*

* Created: 11/1/2021 10:09:46 PM

* Author: Pathirana S.P.S.N

*/

#include "../defines.h"

/*

* Initialize PWN settings

*

* Parameter

* - None

* Return

* - None

*/

void PWM_init(void) {

// Force compare match

TCCR0 = (1 << FOC0);

// Timer0 mode selection bit; Normal, CTC, PWM-Phase correct, [Fast PWM]

TCCR0 |= (1 << WGM00) | (1 << WGM01);

// Output Mode; Disconnected, Reserved, [Non-inverted], Inverted (This is only for Fast PWM)

TCCR0 |= (1 << COM01) | (0 << COM00);

// Clock Source Select; no pre-scaling

TCCR0 |= (0 << CS02) | (1 << CS01) | (1 << CS00);

// Enable Overflow interrupt

TIMSK |= (1 << TOIE0);

TCCR1A = (1 << COM1A1) | (0 << COM1A0); // A - Compare match mode, Non-Inverted Mode.

TCCR1A |= (1 << COM1B1) | (0 << COM1B0); // B - Compare match mode, Non-Inverted Mode.

TCCR1A |= (1 << WGM11) | (0 << WGM10); // Fast PWM mode

TCCR1B = (1 << WGM13);

TCCR1B |= (1 << WGM12); // Compare mode

TCCR1B |= (0 << CS12) | (0 << CS11) | (1 << CS10); // No pre-scaler

ICR1 = 255;

// Force compare match

TCCR2 = (1 << FOC2);

// Timer0 mode selection bit; Normal, CTC, PWM-Phase correct, [Fast PWM]

TCCR2 |= (1 << WGM20) | (1 << WGM21);

// Output Mode; Disconnected, Reserved, [Non-inverted], Inverted (This is only for Fast PWM)

TCCR2 |= (1 << COM21) | (0 << COM20);

// Clock Source Select; no pre-scaling

TCCR2 |= (0 << CS22) | (1 << CS21) | (1 << CS20);

}

/*

* Analog output from pin

*

* Parameter

* - pin (string) - Input pin eg: B3, D4, D5, D7

* - level (int) - Value between 0 - 255

* Return

* - (int) - 0 if no errors.

*/

int PWM_write(Pin pin, int dutyCyle) {

if (pin.port == 'B' && pin.pin == 3) {

OCR0 = dutyCyle;

} else if (pin.port == 'D' && pin.pin == 4) {

OCR1B = dutyCyle;

} else if (pin.port == 'D' && pin.pin == 5) {

OCR1A = dutyCyle;

} else if (pin.port == 'D' && pin.pin == 7) {

OCR2 = dutyCyle;

} else {

return -1;

}

return 0;

}

/*

* Analog output from register

*

* Parameter

* - regi (string) - Register eg: OCR0, OCR1B, OCR1A, OCR2

* - level (int) - Value between 0 - 255

* Return

* - (int) - 0 if no errors.

*/

int PWM_write_reg(void *regi, int dutyCyle) {

volatile uint8_t *_regi = regi;

*_regi = dutyCyle;

return 0;

}

/*

* servo.c

*

* Created: 5/21/2022 8:55:11 PM

* Author: Sadini Pathirana

*/

#include "../defines.h"

/*

* -90 - 14

* 90 - 31

*/

void servo_init() {

pin_mode(B3, OUTPUT);

}

void servo_write(int angle) {

float val = (31 - 14) / 255 * angle + 14;

PWM_write(B3, val);

}

//siren

// Start siren when remote siren button pressed

if (siren == 1)

digital_write(B0, HIGH);

else

digital_write(B0, LOW);

/*

* Digital output

*

* Parameter

* - pin (string) - Input pin eg: A1, B4

* - level (int) - 1 for high value, 0 for low value

* Return

* - (int) - 0 if no errors.

*/

int digital_write(Pin pin, int level) {

volatile uint8_t *regi = select_register(pin.port, &PORTA, &PORTB, &PORTC, &PORTD); // Select PORT register according to pin

if (level == 1) { // Check weather high or low

*regi |= 1 << pin.pin; // Output high value

} else {

*regi &= ~(1 << pin.pin); // Output low value

}

return 0;

}

# Jayathilaka P.H.P – 204087F

/*

* PWM.c

*

* Created: 11/1/2021 10:09:46 PM

* Author: Hansa Jayathilaka

*/

#include "../defines.h"

/*

* Initialize PWN settings

*

* Parameter

* - None

* Return

* - None

*/

void PWM_init(void) {

// Force compare match

TCCR0 = (1 << FOC0);

// Timer0 mode selection bit; Normal, CTC, PWM-Phase correct, [Fast PWM]

TCCR0 |= (1 << WGM00) | (1 << WGM01);

// Output Mode; Disconnected, Reserved, [Non-inverted], Inverted (This is only for Fast PWM)

TCCR0 |= (1 << COM01) | (0 << COM00);

// Clock Source Select; no pre-scaling

TCCR0 |= (0 << CS02) | (1 << CS01) | (1 << CS00);

// Enable Overflow interrupt

TIMSK |= (1 << TOIE0);

TCCR1A = (1 << COM1A1) | (0 << COM1A0); // A - Compare match mode, Non-Inverted Mode.

TCCR1A |= (1 << COM1B1) | (0 << COM1B0); // B - Compare match mode, Non-Inverted Mode.

TCCR1A |= (1 << WGM11) | (0 << WGM10); // Fast PWM mode

TCCR1B = (1 << WGM13);

TCCR1B |= (1 << WGM12); // Compare mode

TCCR1B |= (0 << CS12) | (0 << CS11) | (1 << CS10); // No pre-scaler

ICR1 = 255;

// Force compare match

TCCR2 = (1 << FOC2);

// Timer0 mode selection bit; Normal, CTC, PWM-Phase correct, [Fast PWM]

TCCR2 |= (1 << WGM20) | (1 << WGM21);

// Output Mode; Disconnected, Reserved, [Non-inverted], Inverted (This is only for Fast PWM)

TCCR2 |= (1 << COM21) | (0 << COM20);

// Clock Source Select; no pre-scaling

TCCR2 |= (0 << CS22) | (1 << CS21) | (1 << CS20);

}

/*

* Analog output from pin

*

* Parameter

* - pin (string) - Input pin eg: B3, D4, D5, D7

* - level (int) - Value between 0 - 255

* Return

* - (int) - 0 if no errors.

*/

int PWM_write(Pin pin, int dutyCyle) {

if (pin.port == 'B' && pin.pin == 3) {

OCR0 = dutyCyle;

} else if (pin.port == 'D' && pin.pin == 4) {

OCR1B = dutyCyle;

} else if (pin.port == 'D' && pin.pin == 5) {

OCR1A = dutyCyle;

} else if (pin.port == 'D' && pin.pin == 7) {

OCR2 = dutyCyle;

} else {

return -1;

}

return 0;

}

/*

* Analog output from register

*

* Parameter

* - regi (string) - Register eg: OCR0, OCR1B, OCR1A, OCR2

* - level (int) - Value between 0 - 255

* Return

* - (int) - 0 if no errors.

*/

int PWM_write_reg(void *regi, int dutyCyle) {

volatile uint8_t *_regi = regi;

*_regi = dutyCyle;

return 0;

}

/*

* motor.c

*

* Created: 11/30/2021 4:54:44 PM

* Author: Hansa Jayathilaka

*/

#include "../defines.h"

#define PWM0A D4 // Left Forward

#define PWM0B D5 // Right Forward

#define DIRA C3 // Left Backward

#define DIRB C7 // Right Backward

void motor_init() {

pin_mode(PWM0A, OUTPUT);

pin_mode(PWM0B, OUTPUT);

pin_mode(DIRA, OUTPUT);

pin_mode(DIRB, OUTPUT);

}

void setM2Speed(int speed) {

unsigned char reverse = 0;

if (speed < 0) {

speed = -speed; // make speed a positive quantity

reverse = 1; // preserve the direction

}

if (speed > 0xFF)

speed = 0xFF;

if (reverse) {

digital_write(DIRB, HIGH);

PWM_write(PWM0B, 0xFF - speed);

}

else { // forward

digital_write(DIRB, LOW);

PWM_write(PWM0B, speed);

}

}

void setM1Speed(int speed) {

unsigned char reverse = 0;

if (speed < 0) {

speed = -speed; // make speed a positive quantity

reverse = 1; // preserve the direction

}

if (speed > 0xFF)

speed = 0xFF;

if (reverse) {

digital_write(DIRA, HIGH);

PWM_write(PWM0A, 0xFF - speed);

}

else { // forward

digital_write(DIRA, LOW);

PWM_write(PWM0A, speed);

}

}

void drive(int m1Speed, int m2Speed) {

setM1Speed(m1Speed);

setM2Speed(m2Speed);

}

/*

* display.c

*

* Created: 10/27/2021 4:00:14 PM

* Author: Hansa Jayathilaka

*/

#include "../defines.h"

#define LCD_ADDRESS 0x70

void toggle() {

I2C_write(TWDR | 0x02); // Set enable pin 1; Latching data in to LCD data register using High to Low signal

I2C_write(TWDR & ~0x02); // Set enable pin 0;

}

void LCD_cmd_hf(char val) {

I2C_write(TWDR & ~0x01); // Set RS pin to 0; Selecting register as Command register

I2C_write(TWDR & 0x0F); // Clearing the Higher 4 bits

I2C_write(TWDR | (val & 0xF0)); //----Masking higher 4 bits and sending to LCD

toggle();

}

void LCD_cmd(char val) {

I2C_write(TWDR & ~0x01); //rs = 0; ----Selecting register as command register

I2C_write(TWDR & 0x0F); //----clearing the Higher 4 bits

I2C_write(TWDR | (val & 0xF0)); //----Masking higher 4 bits and sending to LCD

toggle();

I2C_write(TWDR & 0x0F); //----clearing the Higher 4 bits

I2C_write(TWDR | ((val & 0x0F) << 4)); //----Masking lower 4 bits and sending to LCD

toggle();

}

void LCD_dwr(char val) {

I2C_write(TWDR | 0x01); //rs = 1; ----Selecting register as command register

I2C_write(TWDR & 0x0F); //----clearing the Higher 4 bits

I2C_write(TWDR | (val & 0xF0)); //----Masking higher 4 bits and sending to LCD

toggle();

I2C_write(TWDR & 0x0F); //----clearing the Higher 4 bits

I2C_write(TWDR | ((val & 0x0F) << 4)); //----Masking lower 4 bits and sending to LCD

toggle();

}

void LCD_init() {

I2C_start();

I2C_select_slave(LCD_ADDRESS, WRITE);

LCD_cmd_hf(0x30); //-----Sequence for initializing LCD

LCD_cmd_hf(0x30); //----- " " " "

LCD_cmd_hf(0x20); //----- " " " "

LCD_cmd(0x28); //-----Selecting 16 x 2 LCD in 4Bit mode

LCD_cmd(0x0C); //-----Display ON Cursor OFF

LCD_cmd(0x01); //-----Clear display

LCD_cmd(0x06); //-----Cursor Auto Increment

LCD_cmd(0x80); //-----1st line 1st location of LCD

I2C_stop();

}

void delay(int ms) {

int i,j;

for(i=0;i<=ms;i++)

for(j=0;j<=120;j++);

}

void LCD_msg(char *c) {

I2C_start();

I2C_select_slave(LCD_ADDRESS, WRITE);

while(*c != 0) //----Wait till all String are passed to LCD

LCD_dwr(*c++); //----Send the String to LCD

I2C_stop();

}

void LCD_rig_sh() {

LCD_cmd(0x1C); //----Command for right Shift

delay(400);

}

void LCD_lef_sh() {

LCD_cmd(0x18); //----Command for Left Shift

delay(200);

}

void LCD_clear_msg(char* c) {

I2C_start();

I2C_select_slave(LCD_ADDRESS, WRITE);

LCD_cmd(0x01);

LCD_cmd(0x80);

while(*c != 0) //----Wait till all String are passed to LCD

LCD_dwr(*c++); //----Send the String to LCD

I2C_stop();

}

void LCD_clear() {

I2C_start();

I2C_select_slave(LCD_ADDRESS, WRITE);

LCD_cmd(0x01);

LCD_cmd(0x80);

I2C_stop();

}

void LCD_line_1() {

I2C_start();

I2C_select_slave(LCD_ADDRESS, WRITE);

LCD_cmd(0x80);

I2C_stop();

}

void LCD_line_2() {

I2C_start();

I2C_select_slave(LCD_ADDRESS, WRITE);

LCD_cmd(0xC0);

I2C_stop();

}

Group – 47 codes

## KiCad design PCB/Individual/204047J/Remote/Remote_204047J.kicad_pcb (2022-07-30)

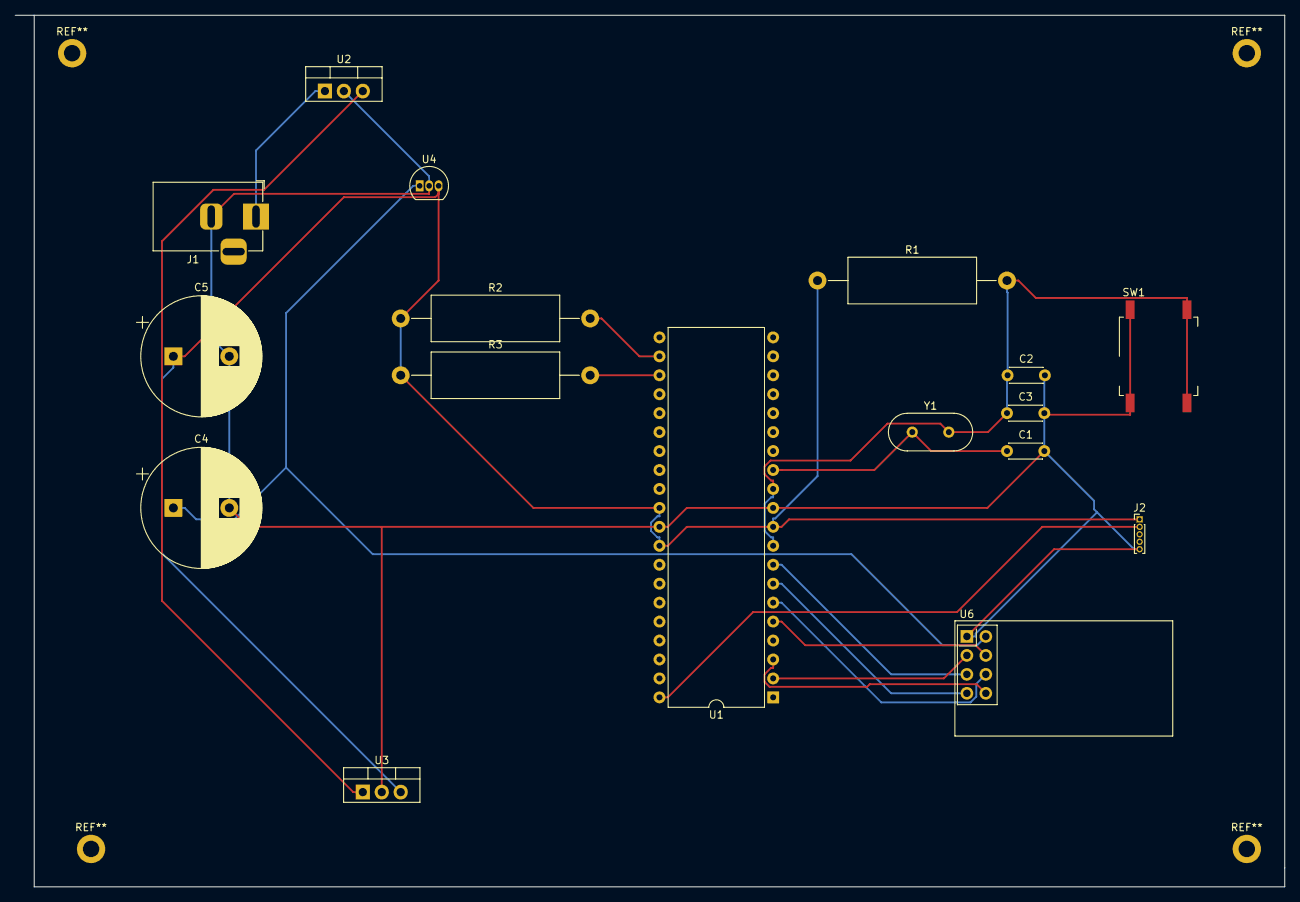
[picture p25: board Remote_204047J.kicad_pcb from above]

Board: 2 copper layers, 170.2 x 116.8 mm, 17 parts (0 on the bottom side), 10 nets.

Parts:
C1, C2: 22pF; C_Disc_D4.3mm_W1.9mm_P5.00mm
C3: 10uF; C_Disc_D4.3mm_W1.9mm_P5.00mm
C4, C5: 470uF; CP_Radial_D16.0mm_P7.50mm
J1: Barrel_Jack; BarrelJack_Horizontal
J2: Joystick (Servo); PinHeader_1x05_P1.00mm_Vertical
R1: 10k; R_Axial_DIN0617_L17.0mm_D6.0mm_P25.40mm_Horizontal
R2, R3: 4.7k; R_Axial_DIN0617_L17.0mm_D6.0mm_P25.40mm_Horizontal
SW1: Reset Button; SW_MEC_5GSH9
U1: ATmega32-16P; DIP-40_W15.24mm
U2: L7809; TO-220-3_Vertical
U3: L7805; TO-220-3_Vertical
U4: L78L33_TO92; TO-92_Inline
U6: NRF24L01; nRF24L01_Breakout
Y1: Crystal; Crystal_HC18-U_Vertical

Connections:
/Atmega32/5V: C5.1, R1.1, R2.1, R3.1, U1.10 (VCC), U1.30 (AVCC), U1.32 (AREF), U3.3 (OUT), U4.3 (VI)
/Atmega32/GND: C1.2, C2.2, C3.2, C4.2, C5.2, J1.2, SW1.1 (A), SW1.2 (A), U1.11 (GND), U1.31 (GND), U2.2 (GND), U3.2 (GND), U4.2 (GND)
/Atmega32/SCL: R2.2, U1.22 (PC0)
/Atmega32/SDA: R3.2, U1.23 (PC1)
/GND: J2.5 (GND), U6.1 (GND)
/Power Supply/3.3V: C4.1, U4.1 (VO)
/Power Supply/12V: J1.1, U2.1 (IN)
unnamed: C1.1, U1.13 (XTAL1), Y1.1
unnamed: C2.1, C3.1, R1.2, SW1.3 (B), SW1.4 (B), U1.9 (~RESET), U1.12 (XTAL2), Y1.2
unnamed: U2.3 (OUT), U3.1 (IN)

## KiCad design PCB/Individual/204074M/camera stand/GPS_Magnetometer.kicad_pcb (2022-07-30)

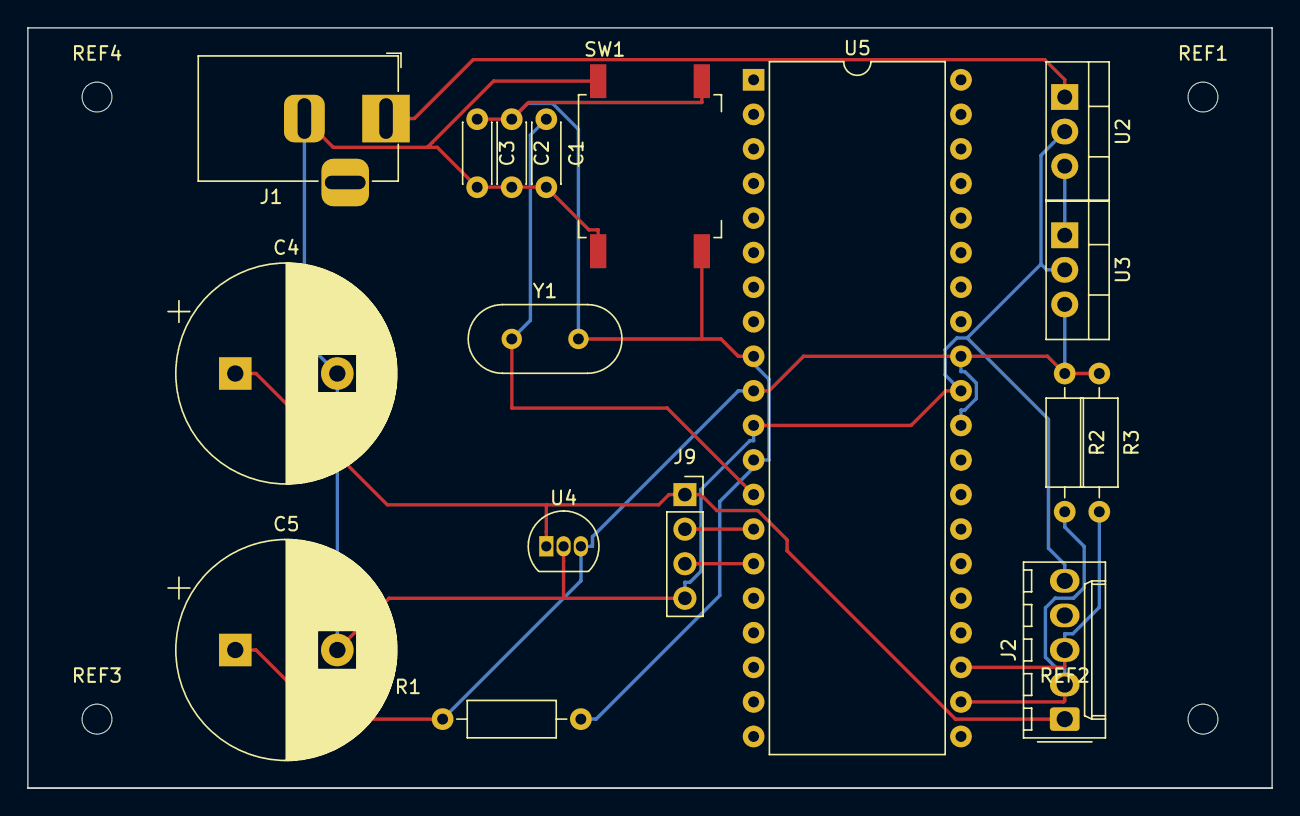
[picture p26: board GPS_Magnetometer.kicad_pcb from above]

Board: 2 copper layers, 91.4 x 55.9 mm, 21 parts (0 on the bottom side), 11 nets.

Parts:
C1, C2: 22pF; C_Disc_D4.3mm_W1.9mm_P5.00mm
C3: 10uF; C_Disc_D4.3mm_W1.9mm_P5.00mm
C4, C5: 470uF; CP_Radial_D16.0mm_P7.50mm
J1: Barrel_Jack; BarrelJack_Horizontal
J2: HMC5883L; Molex_KK-254_AE-6410-05A_1x05_P2.54mm_Vertical
J9: GPS Module; PinSocket_1x04_P2.54mm_Vertical
R1: 10k; R_Axial_DIN0207_L6.3mm_D2.5mm_P10.16mm_Horizontal
R2, R3: 4.7k; R_Axial_DIN0207_L6.3mm_D2.5mm_P10.16mm_Horizontal
REF1, REF2, REF3, REF4: MountingHole_2.2mm_M2
SW1: Reset Button; SW_MEC_5GSH9
U2: L7809; TO-220-3_Vertical
U3: L7805; TO-220-3_Vertical
U4: L78L33_TO92; TO-92_Inline
U5: ATmega32-16P; DIP-40_W15.24mm
Y1: Crystal; Crystal_HC18-U_Vertical

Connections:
/Atmega32/5V: C5.1, R1.1, R2.1, R3.1, U3.3 (OUT), U4.3 (VI), U5.10 (VCC), U5.30 (AVCC), U5.32 (AREF)
/Atmega32/GND: C1.2, C2.2, C3.2, C4.2, C5.2, J1.2, J2.5 (GND), J9.4 (GND), SW1.1 (A), SW1.2 (A), U2.2 (GND), U3.2 (GND), U4.2 (GND), U5.11 (GND), U5.31 (GND)
/Atmega32/Rx: J9.2 (Tx), U5.14 (PD0)
/Atmega32/SCL: J2.2 (SCL), R2.2, U5.22 (PC0)
/Atmega32/SDA: J2.3 (SDA), R3.2, U5.23 (PC1)
/Atmega32/Tx: J9.3 (Rx), U5.15 (PD1)
/Power Supply/3.3V: C4.1, J2.1 (VCC), J9.1 (VCC), U4.1 (VO)
/Power Supply/12V: J1.1, U2.1 (IN)
unnamed: C1.1, U5.13 (XTAL1), Y1.1
unnamed: C2.1, C3.1, R1.2, SW1.3 (B), SW1.4 (B), U5.9 (~RESET), U5.12 (XTAL2), Y1.2
unnamed: U2.3 (OUT), U3.1 (IN)

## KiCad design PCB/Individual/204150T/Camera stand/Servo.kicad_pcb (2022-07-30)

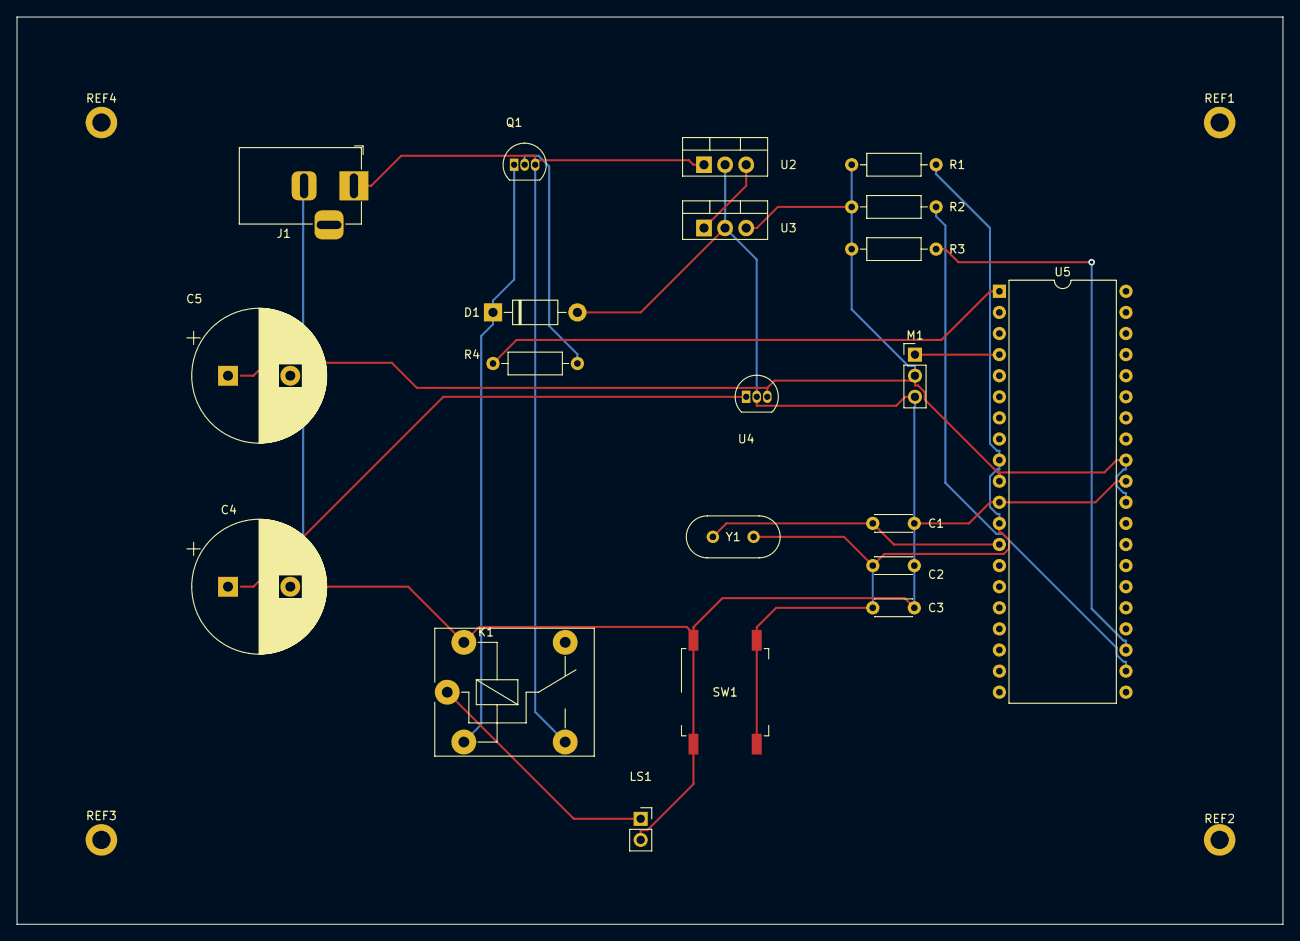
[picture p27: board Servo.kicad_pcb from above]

Board: 2 copper layers, 152.4 x 109.2 mm, 25 parts (0 on the bottom side), 14 nets.

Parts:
C1, C2: 22pF; C_Disc_D4.3mm_W1.9mm_P5.00mm
C3: 10uF; C_Disc_D4.3mm_W1.9mm_P5.00mm
C4, C5: 470uF; CP_Radial_D16.0mm_P7.50mm
D1: 1N4007; D_DO-41_SOD81_P10.16mm_Horizontal
J1: Barrel_Jack; BarrelJack_Horizontal
K1: Relay; Relay_SPDT_Finder_36.11
LS1: Speaker; PinSocket_1x02_P2.54mm_Vertical
M1: Motor_Servo; PinHeader_1x03_P2.54mm_Vertical
Q1: PN2222A; TO-92_Inline
R1: 10k; R_Axial_DIN0207_L6.3mm_D2.5mm_P10.16mm_Horizontal
R2, R3: 4.7k; R_Axial_DIN0207_L6.3mm_D2.5mm_P10.16mm_Horizontal
R4: 100k; R_Axial_DIN0207_L6.3mm_D2.5mm_P10.16mm_Horizontal
REF1: M1; MountingHole_2.2mm_M2_ISO14580_Pad
REF2: M2; MountingHole_2.2mm_M2_ISO14580_Pad
REF3: M3; MountingHole_2.2mm_M2_ISO14580_Pad
REF4: M4; MountingHole_2.2mm_M2_ISO14580_Pad
SW1: Reset Button; SW_MEC_5GSH9
U2: L7809; TO-220-3_Vertical
U3: L7805; TO-220-3_Vertical
U4: L78L33_TO92; TO-92_Inline
U5: ATmega32-16P; DIP-40_W15.24mm
Y1: Crystal; Crystal_HC18-U_Vertical

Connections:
/Atmega32/5V: C5.1, M1.2 (+), R1.1, R2.1, R3.1, U3.3 (OUT), U4.3 (VI), U5.10 (VCC), U5.30 (AVCC), U5.32 (AREF)
/Atmega32/B0: R4.1, U5.1 (PB0)
/Atmega32/B3: M1.1 (PWM), U5.4 (PB3)
/Atmega32/GND: C1.2, C2.2, C3.2, C4.2, C5.2, D1.2 (A), J1.2, K1.A2, LS1.2, M1.3 (-), SW1.1 (A), SW1.2 (A), U2.2 (GND), U3.2 (GND), U4.2 (GND), U5.11 (GND), U5.31 (GND)
/Atmega32/SCL: R2.2, U5.22 (PC0)
/Atmega32/SDA: R3.2, U5.23 (PC1)
/Power Supply/3.3V: C4.1, U4.1 (VO)
/Power Supply/12V: J1.1, K1.14, Q1.3 (C), U2.1 (IN)
unnamed: C1.1, U5.13 (XTAL1), Y1.1
unnamed: C2.1, C3.1, R1.2, SW1.3 (B), SW1.4 (B), U5.9 (~RESET), U5.12 (XTAL2), Y1.2
unnamed: D1.1 (K), K1.A1, Q1.1 (E)
unnamed: K1.11, LS1.1
unnamed: Q1.2 (B), R4.2
unnamed: U2.3 (OUT), U3.1 (IN)

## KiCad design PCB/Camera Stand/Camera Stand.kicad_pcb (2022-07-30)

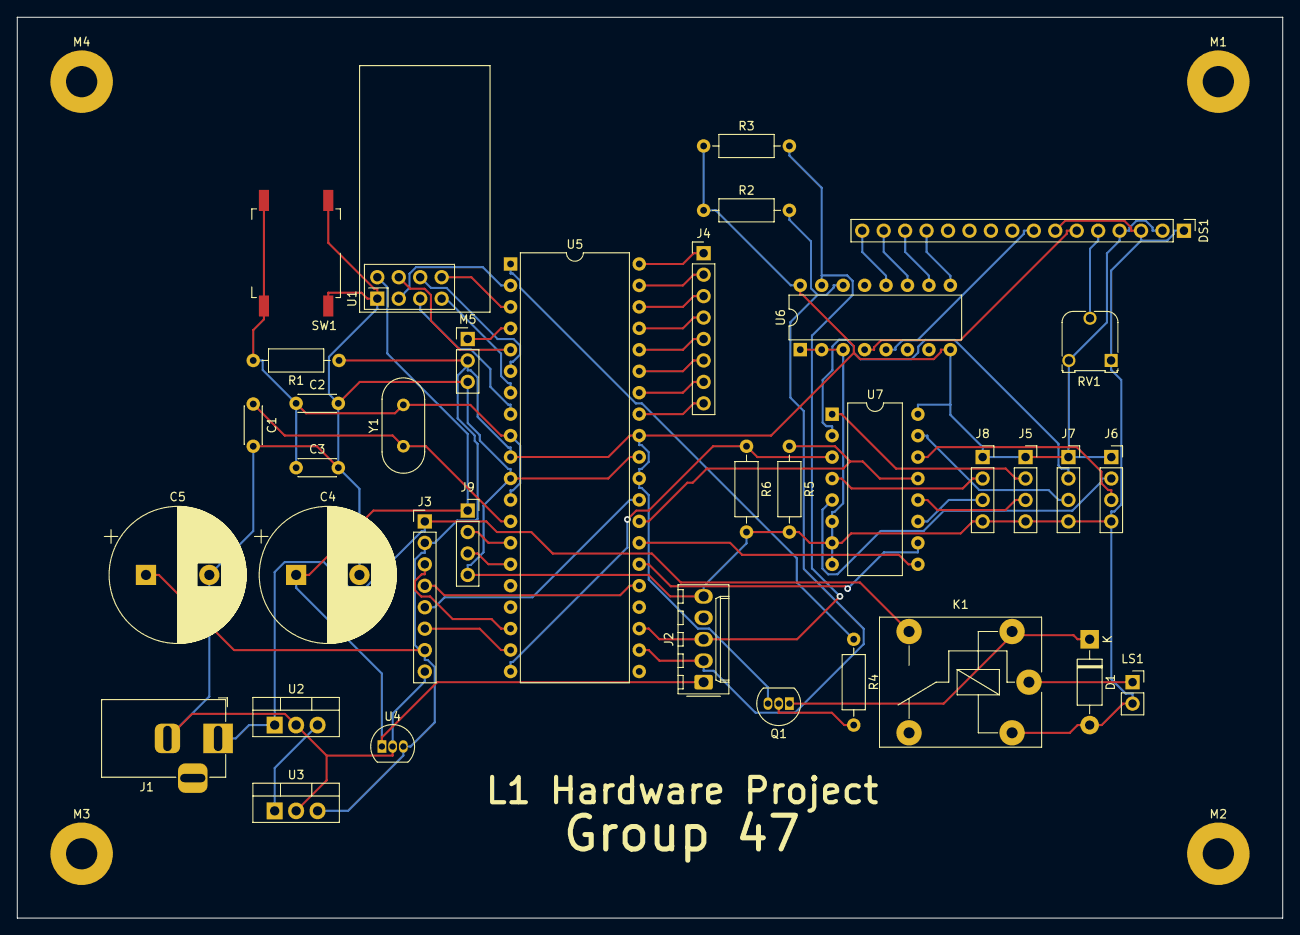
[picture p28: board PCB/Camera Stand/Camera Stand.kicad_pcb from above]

Board: 2 copper layers, 149.9 x 106.7 mm, 40 parts (0 on the bottom side), 53 nets.

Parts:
C1, C2: 22pF; C_Disc_D4.3mm_W1.9mm_P5.00mm
C3: 10uF; C_Disc_D4.3mm_W1.9mm_P5.00mm
C4, C5: 470uF; CP_Radial_D16.0mm_P7.50mm
D1: 1N4007; D_DO-41_SOD81_P10.16mm_Horizontal
DS1: HY1602E; PinHeader_1x16_P2.54mm_Vertical
J1: Barrel_Jack; BarrelJack_Horizontal
J2: HMC5883L; Molex_KK-254_AE-6410-05A_1x05_P2.54mm_Vertical
J3: Motor Drive; PinHeader_1x08_P2.54mm_Vertical
J4: Keypad 4x4; PinHeader_1x08_P2.54mm_Vertical
J5: Ultrasonic Left Front; PinSocket_1x04_P2.54mm_Vertical
J6: Ultrasonic Right Front; PinSocket_1x04_P2.54mm_Vertical
J7: Ultrasonic Left Back; PinSocket_1x04_P2.54mm_Vertical
J8: Ultrasonic Right Back; PinSocket_1x04_P2.54mm_Vertical
J9: GPS Module; PinSocket_1x04_P2.54mm_Vertical
K1: Relay; Relay_SPDT_Finder_36.11
LS1: Speaker; PinSocket_1x02_P2.54mm_Vertical
M1, M2, M3, M4: MountingHole_3.7mm_Pad
M5: Motor_Servo; PinHeader_1x03_P2.54mm_Vertical
Q1: PN2222A; TO-92_Inline
R1, R5, R6: 10k; R_Axial_DIN0207_L6.3mm_D2.5mm_P10.16mm_Horizontal
R2, R3: 4.7k; R_Axial_DIN0207_L6.3mm_D2.5mm_P10.16mm_Horizontal
R4: 100k; R_Axial_DIN0207_L6.3mm_D2.5mm_P10.16mm_Horizontal
RV1: Potentiometer; Potentiometer_Runtron_RM-065_Vertical
SW1: Reset Button; SW_MEC_5GSH9
U1: NRF24L01; nRF24L01_Breakout
U2: L7809; TO-220-3_Vertical
U3: L7805; TO-220-3_Vertical
U4: L78L33_TO92; TO-92_Inline
U5: ATmega32-16P; DIP-40_W15.24mm
U6: PCF8574A; DIP-16_W7.62mm
U7: CD4052B; DIP-16_W10.16mm
Y1: Crystal; Crystal_HC18-U_Vertical

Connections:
/Atmega32/5V: C5.1, DS1.2 (LEDA), DS1.4 (VDD), J3.2 (ENA), J3.7 (ENB), J5.1 (VCC), J6.1 (VCC), J7.1 (VCC), J8.1 (VCC), M5.2 (+), Q1.3 (C), R1.1, R2.1, R3.1, RV1.3, U3.3 (OUT), U4.3 (VI), U5.10 (VCC), U5.30 (AVCC), U5.32 (AREF), U6.8 (VSS), U6.16 (VDD), U7.16 (VDD)
/Atmega32/A0: J4.1 (Col_A), U5.40 (PA0)
/Atmega32/A1: J4.2 (Col_B), U5.39 (PA1)
/Atmega32/A2: J4.3 (Col_C), U5.38 (PA2)
/Atmega32/A3: J4.4 (Col_D), U5.37 (PA3)
/Atmega32/A4: J4.5 (Row_1), U5.36 (PA4)
/Atmega32/A5: J4.6 (Row_2), U5.35 (PA5)
/Atmega32/A6: J4.7 (Row_3), U5.34 (PA6)
/Atmega32/A7: J4.8 (Row_4), U5.33 (PA7)
/Atmega32/B0: R4.1, U5.1 (PB0)
/Atmega32/B3: M5.1 (PWM), U5.4 (PB3)
/Atmega32/C3: J3.4 (INA2), U5.25 (PC3)
/Atmega32/C4: U5.26 (PC4), U7.10 (A)
/Atmega32/C5: U5.27 (PC5), U7.9 (B)
/Atmega32/C6: R5.1, U5.28 (PC6), U7.13 (X)
/Atmega32/C7: J3.5 (INB1), U5.29 (PC7)
/Atmega32/CE: U1.3 (CE), U5.2 (PB1)
/Atmega32/CSN: U1.4 (~CSN), U5.5 (PB4)
/Atmega32/D4: J3.3 (INA1), U5.18 (PD4)
/Atmega32/D5: J3.6 (INB2), U5.19 (PD5)
/Atmega32/D6: R6.1, U5.20 (PD6), U7.3 (Y)
/Atmega32/GND: C1.2, C2.2, C3.2, C4.2, C5.2, D1.2 (A), DS1.1 (LEDK), DS1.3 (VSS), DS1.7 (R/~W), J1.2, J2.5 (GND), J3.8 (GND), J5.4 (GND), J6.4 (GND), J7.4 (GND), J8.4 (GND), J9.4 (GND), K1.A2, LS1.2, M5.3 (-), R5.2, R6.2, RV1.1, SW1.1 (A), SW1.2 (A), U1.1 (GND), U2.2 (GND), U3.2 (GND), U4.2 (GND), U5.11 (GND), U5.31 (GND), U6.1 (A0), U6.2 (A1), U6.3 (A2), U7.6 (INH), U7.7 (VEE), U7.8 (VSS)
/Atmega32/IRQ: U1.8 (IRQ), U5.3 (PB2)
/Atmega32/MISO: U1.7 (MISO), U5.7 (PB6)
/Atmega32/MOSI: U1.6 (MOSI), U5.6 (PB5)
/Atmega32/Rx: J9.2 (Tx), U5.14 (PD0)
/Atmega32/SCK: U1.5 (SCK), U5.8 (PB7)
/Atmega32/SCL: J2.2 (SCL), R2.2, U5.22 (PC0), U6.14 (SCL)
/Atmega32/SDA: J2.3 (SDA), R3.2, U5.23 (PC1), U6.15 (SDA)
/Atmega32/Tx: J9.3 (Rx), U5.15 (PD1)
/Power Supply/3.3V: C4.1, J2.1 (VCC), J9.1 (VCC), U1.2 (VCC), U4.1 (VO)
/Power Supply/12V: J1.1, J3.1 (VCC), K1.14, U2.1 (IN)
unnamed: C1.1, U5.13 (XTAL1), Y1.1
unnamed: C2.1, C3.1, R1.2, SW1.3 (B), SW1.4 (B), U5.9 (~RESET), U5.12 (XTAL2), Y1.2
unnamed: D1.1 (K), K1.A1, Q1.1 (E)
unnamed: DS1.5 (Vo), RV1.2
unnamed: DS1.6 (RS), U6.4 (P0)
unnamed: DS1.8 (E), U6.5 (P1)
unnamed: DS1.13 (DB4), U6.9 (P4)
unnamed: DS1.14 (DB5), U6.10 (P5)
unnamed: DS1.15 (DB6), U6.11 (P6)
unnamed: DS1.16 (DB7), U6.12 (P7)
unnamed: J5.2 (Echo), U7.1 (Y0)
unnamed: J5.3 (Trig), U7.12 (X0)
unnamed: J6.2 (Echo), U7.5 (Y1)
unnamed: J6.3 (Trig), U7.14 (X1)
unnamed: J7.2 (Echo), U7.2 (Y2)
unnamed: J7.3 (Trig), U7.15 (X2)
unnamed: J8.2 (Echo), U7.4 (Y3)
unnamed: J8.3 (Trig), U7.11 (X3)
unnamed: K1.11, LS1.1
unnamed: Q1.2 (B), R4.2
unnamed: U2.3 (OUT), U3.1 (IN)

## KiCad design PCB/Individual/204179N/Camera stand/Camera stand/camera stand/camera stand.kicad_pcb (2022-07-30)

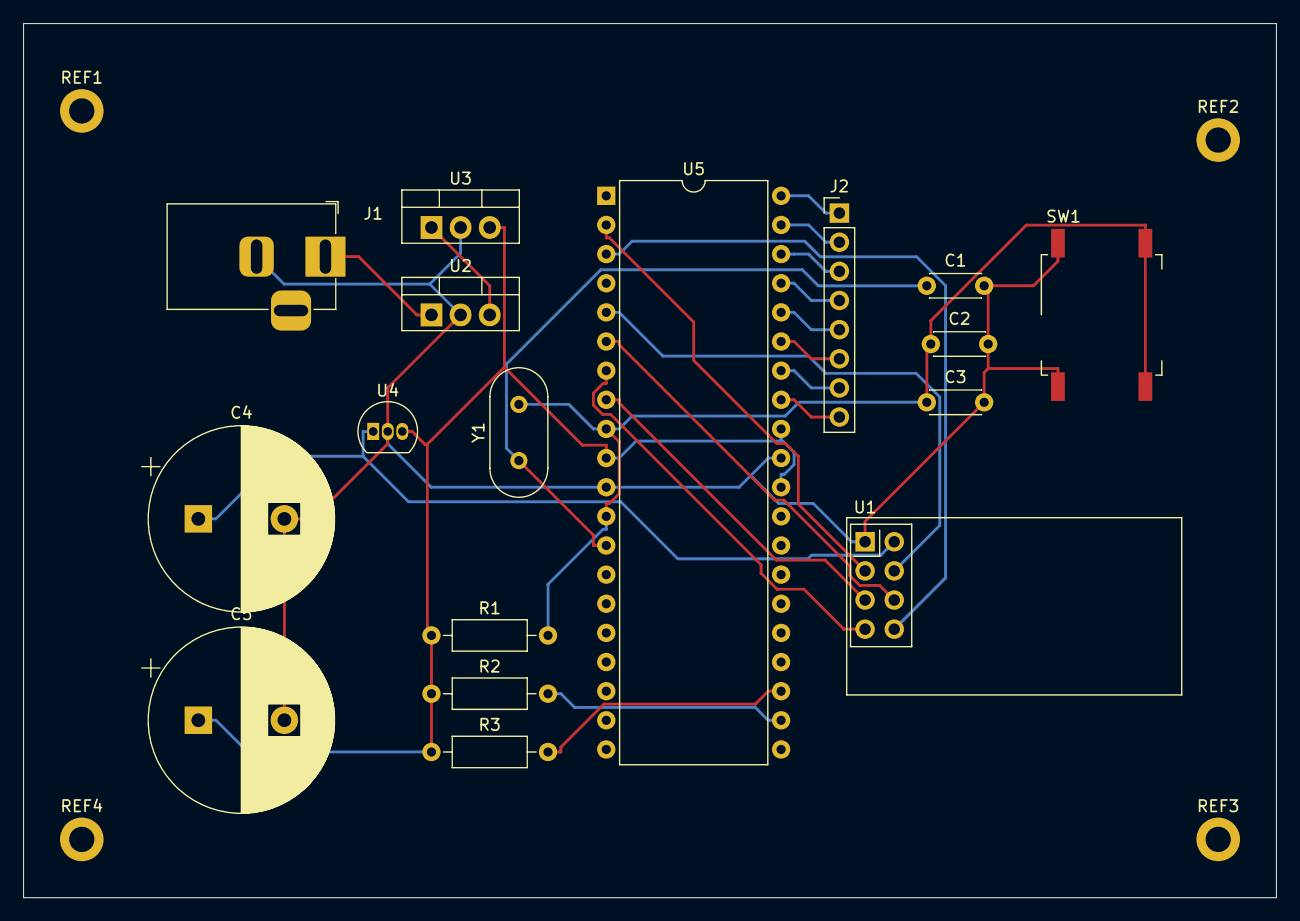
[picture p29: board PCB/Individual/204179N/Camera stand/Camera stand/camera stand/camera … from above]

Board: 2 copper layers, 109.2 x 76.2 mm, 21 parts (0 on the bottom side), 23 nets.

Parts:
C1, C2: 22pF; C_Disc_D4.3mm_W1.9mm_P5.00mm
C3: 10uF; C_Disc_D4.3mm_W1.9mm_P5.00mm
C4, C5: 470uF; CP_Radial_D16.0mm_P7.50mm
J1: Barrel_Jack; BarrelJack_Horizontal
J2: Keypad 4x4; PinHeader_1x08_P2.54mm_Vertical
R1: 10k; R_Axial_DIN0207_L6.3mm_D2.5mm_P10.16mm_Horizontal
R2, R3: 4.7k; R_Axial_DIN0207_L6.3mm_D2.5mm_P10.16mm_Horizontal
REF1: M1; MountingHole_2.2mm_M2_ISO14580_Pad
REF2: M2; MountingHole_2.2mm_M2_ISO14580_Pad
REF3: M3; MountingHole_2.2mm_M2_ISO14580_Pad
REF4: M4; MountingHole_2.2mm_M2_ISO14580_Pad
SW1: Reset Button; SW_MEC_5GSH9
U1: NRF24L01; nRF24L01_Breakout
U2: L7809; TO-220-3_Vertical
U3: L7805; TO-220-3_Vertical
U4: L78L33_TO92; TO-92_Inline
U5: ATmega32-16P; DIP-40_W15.24mm
Y1: Crystal; Crystal_HC18-U_Vertical

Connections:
/Atmega32/5V: C5.1, R1.1, R2.1, R3.1, U3.3 (OUT), U4.3 (VI), U5.10 (VCC), U5.30 (AVCC), U5.32 (AREF)
/Atmega32/A0: J2.1 (Col_A), U5.40 (PA0)
/Atmega32/A1: J2.2 (Col_B), U5.39 (PA1)
/Atmega32/A2: J2.3 (Col_C), U5.38 (PA2)
/Atmega32/A3: J2.4 (Col_D), U5.37 (PA3)
/Atmega32/A4: J2.5 (Row_1), U5.36 (PA4)
/Atmega32/A5: J2.6 (Row_2), U5.35 (PA5)
/Atmega32/A6: J2.7 (Row_3), U5.34 (PA6)
/Atmega32/A7: J2.8 (Row_4), U5.33 (PA7)
/Atmega32/CE: U1.3 (CE), U5.2 (PB1)
/Atmega32/CSN: U1.4 (~CSN), U5.5 (PB4)
/Atmega32/GND: C1.2, C2.2, C3.2, C4.2, C5.2, J1.2, SW1.1 (A), SW1.2 (A), U1.1 (GND), U2.2 (GND), U3.2 (GND), U4.2 (GND), U5.11 (GND), U5.31 (GND)
/Atmega32/IRQ: U1.8 (IRQ), U5.3 (PB2)
/Atmega32/MISO: U1.7 (MISO), U5.7 (PB6)
/Atmega32/MOSI: U1.6 (MOSI), U5.6 (PB5)
/Atmega32/SCK: U1.5 (SCK), U5.8 (PB7)
/Atmega32/SCL: R2.2, U5.22 (PC0)
/Atmega32/SDA: R3.2, U5.23 (PC1)
/Power Supply/3.3V: C4.1, U1.2 (VCC), U4.1 (VO)
/Power Supply/12V: J1.1, U2.1 (IN)
unnamed: C1.1, U5.13 (XTAL1), Y1.1
unnamed: C2.1, C3.1, R1.2, SW1.3 (B), SW1.4 (B), U5.9 (~RESET), U5.12 (XTAL2), Y1.2
unnamed: U2.3 (OUT), U3.1 (IN)

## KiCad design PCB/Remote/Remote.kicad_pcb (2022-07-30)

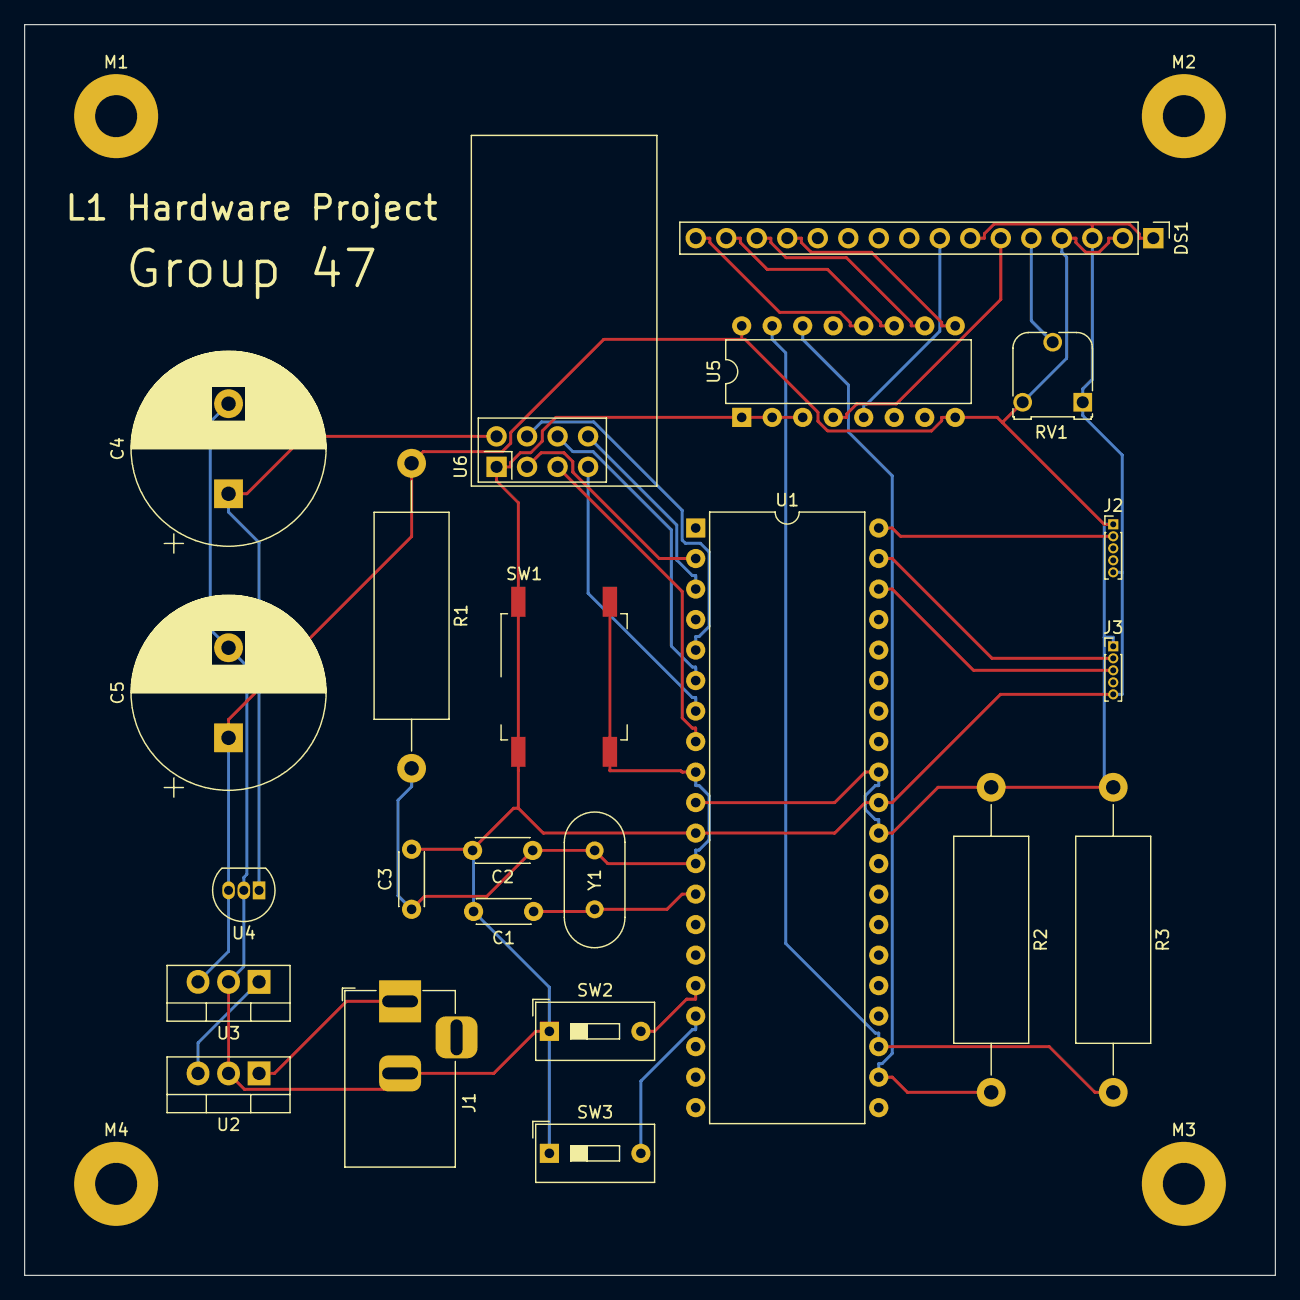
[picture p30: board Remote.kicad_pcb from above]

Board: 2 copper layers, 104.1 x 104.1 mm, 27 parts (0 on the bottom side), 27 nets.

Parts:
C1, C2: 22pF; C_Disc_D4.3mm_W1.9mm_P5.00mm
C3: 10uF; C_Disc_D4.3mm_W1.9mm_P5.00mm
C4, C5: 470uF; CP_Radial_D16.0mm_P7.50mm
DS1: HY1602E; PinHeader_1x16_P2.54mm_Vertical
J1: Barrel_Jack; BarrelJack_Horizontal
J2: Joystick (Servo); PinHeader_1x05_P1.00mm_Vertical
J3: Joystick (Motor); PinHeader_1x05_P1.00mm_Vertical
M1, M2, M3, M4: MountingHole_3.5mm_Pad
R1: 10k; R_Axial_DIN0617_L17.0mm_D6.0mm_P25.40mm_Horizontal
R2, R3: 4.7k; R_Axial_DIN0617_L17.0mm_D6.0mm_P25.40mm_Horizontal
RV1: Potentiometer; Potentiometer_Runtron_RM-065_Vertical
SW1: Reset Button; SW_MEC_5GSH9
SW2: Auto/Manual; SW_DIP_SPSTx01_Slide_9.78x4.72mm_W7.62mm_P2.54mm
SW3: Siren on/off; SW_DIP_SPSTx01_Slide_9.78x4.72mm_W7.62mm_P2.54mm
U1: ATmega32-16P; DIP-40_W15.24mm
U2: L7809; TO-220-3_Vertical
U3: L7805; TO-220-3_Vertical
U4: L78L33_TO92; TO-92_Inline
U5: PCF8574A; DIP-16_W7.62mm
U6: NRF24L01; nRF24L01_Breakout
Y1: Crystal; Crystal_HC18-U_Vertical

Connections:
/Atmega32/5V: C5.1, DS1.2 (LEDA), DS1.4 (VDD), J2.1 (5V), J3.1 (5V), R1.1, R2.1, R3.1, RV1.3, U1.10 (VCC), U1.30 (AVCC), U1.32 (AREF), U3.3 (OUT), U4.3 (VI), U5.8 (VSS), U5.16 (VDD)
/Atmega32/A0: J2.2 (VRx), U1.40 (PA0)
/Atmega32/A1: J3.2 (VRx), U1.39 (PA1)
/Atmega32/A2: J3.3 (VRy), U1.38 (PA2)
/Atmega32/CE: U1.2 (PB1), U6.3 (CE)
/Atmega32/CSN: U1.5 (PB4), U6.4 (~CSN)
/Atmega32/D2: SW2.2 (B), U1.16 (PD2)
/Atmega32/D3: SW3.2 (B), U1.17 (PD3)
/Atmega32/GND: C1.2, C2.2, C3.2, C4.2, C5.2, DS1.1 (LEDK), DS1.3 (VSS), DS1.7 (R/~W), J1.2, J2.5 (GND), J3.5 (GND), RV1.1, SW1.1 (A), SW1.2 (A), SW2.1 (A), SW3.1 (A), U1.11 (GND), U1.31 (GND), U2.2 (GND), U3.2 (GND), U4.2 (GND), U5.1 (A0), U5.2 (A1), U5.3 (A2), U6.1 (GND)
/Atmega32/IRQ: U1.3 (PB2), U6.8 (IRQ)
/Atmega32/MISO: U1.7 (PB6), U6.7 (MISO)
/Atmega32/MOSI: U1.6 (PB5), U6.6 (MOSI)
/Atmega32/SCK: U1.8 (PB7), U6.5 (SCK)
/Atmega32/SCL: R2.2, U1.22 (PC0), U5.14 (SCL)
/Atmega32/SDA: R3.2, U1.23 (PC1), U5.15 (SDA)
/Power Supply/3.3V: C4.1, U4.1 (VO), U6.2 (VCC)
/Power Supply/12V: J1.1, U2.1 (IN)
unnamed: C1.1, U1.13 (XTAL1), Y1.1
unnamed: C2.1, C3.1, R1.2, SW1.3 (B), SW1.4 (B), U1.9 (~RESET), U1.12 (XTAL2), Y1.2
unnamed: DS1.5 (Vo), RV1.2
unnamed: DS1.6 (RS), U5.4 (P0)
unnamed: DS1.8 (E), U5.5 (P1)
unnamed: DS1.13 (DB4), U5.9 (P4)
unnamed: DS1.14 (DB5), U5.10 (P5)
unnamed: DS1.15 (DB6), U5.11 (P6)
unnamed: DS1.16 (DB7), U5.12 (P7)
unnamed: U2.3 (OUT), U3.1 (IN)

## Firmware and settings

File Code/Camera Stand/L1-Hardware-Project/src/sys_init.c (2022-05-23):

/*
 * sys_init.c
 *
 * Created: 11/1/2021 10:33:36 PM
 * 
 */

#include "defines.h"


void sys_init(void) {
	I2C_master_init();
	LCD_init();
	
	LCD_clear_msg("Group 47 Slave");
	LCD_line_2();
	LCD_msg("Initializing....");
	_delay_ms(10);
	
	// Siren
	pin_mode(B0, OUTPUT);
	
	PWM_init();
	motor_init();
	servo_init();
	SPI_master_init();
	
	ultrazonic_init();
	
	Magneto_init();
	
	UART_init(9600);
	UART_SendString("Starting...");
	
	nrf_init(NRF_MODE_PRX, NRF_RX_PLOAD);
	
	LCD_line_2();
	LCD_msg("Init Completed.");
	_delay_ms(500);
	
	LCD_line_1();
	LCD_msg("Enter Location");
	_delay_ms(500);
	
	char *temp;
	
	LCD_line_1();
	LCD_msg("Longitude       ");
	LCD_line_2();
	char longitude[20];
	key_string(longitude, 20);
	destination.longitude = strtod(longitude, temp);
	
	LCD_line_1();
	LCD_msg("Latitude        ");
	LCD_line_2();
	char latitude[20];
	key_string(latitude, 20);
	destination.latitude = strtod(latitude, temp);
}

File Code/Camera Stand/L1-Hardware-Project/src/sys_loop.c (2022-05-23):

/*
 * sys_loop.c
 *
 * Created: 11/1/2021 10:35:03 PM
 * 
 */ 

#include "defines.h"


int kp = 5, kq = 5, kr = 30, ks = 10, base_speed = 100;


void sys_loop(void) {
	uint8_t cam_angle, right, forward, siren, auto_mode;
	
	// Get values from nRF
	nrf_rx_data(&cam_angle, &right, &forward, &siren, &auto_mode);
	
	if (auto_mode == 1) {
		// Auto Mode
		
		// Get GPS coordinates
		GPS_init();
		
		// Calculate angle error from facing direction
		int angle_error = angle_from_north(destination.latitude, destination.longitude) - Magneto_GetHeading();
		
		// Get the direction change occurred by obstacles
		int error = ultrazonic_error();
		
		// Calculate motor speeds with all parameters
		int rPower = base_speed + error * ks + angle_error * kr;
		int lPower = base_speed - error * ks - angle_error * kr;
		
		drive(lPower, rPower);
		servo_write(0);
	} else {
		// Manual Mode
		
		// Calculate motor speeds according to the signals of remote control
		int rPower = forward * kp - right * kq;
		int lPower = forward * kp + right * kq;
		
		// Write speed to motors
		drive(lPower, rPower);
		
		// Rotate servo according to 
		servo_write(cam_angle);
	}
	
	// Start siren when remote siren button pressed
	if (siren == 1)
		digital_write(B0, HIGH);
	else
		digital_write(B0, LOW);
}

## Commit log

2021-10-23 Update Resources.readme
    Added youtube link -ADC testing with proteus
2021-10-27 ADC reading.
2021-10-31 PWM readings
2021-12-03 made the circuit diagram
2021-12-04 New circuit designs.
2022-05-10 add SPI Master
2022-05-11 Add I2C
2022-05-11 Testing on SPI
2022-05-11 fixed SPI issue
2022-05-12 SPI Update
2022-05-13 magnetometer, GPS modified
2022-05-13 Changes in I2C
2022-05-18 motor init
2022-05-22 finalized gps, magnet in slave
2022-06-06 Add PCB
    [Atmega32.kicad_sch, Camera Stand.dsn, Camera Stand.kicad_pcb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]
2022-06-07 3.3v error in PCB
    [Camera Stand.dsn, Camera Stand.kicad_pcb, Camera Stand.kicad_sch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]
2022-06-07 12v to siren
    [Camera Stand.dsn, Camera Stand.kicad_pcb, Camera Stand.kicad_sch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]
2022-06-07 Individual PCB
    [Atmega32.kicad_sch, Camera Stand.dsn, Camera Stand.kicad_pcb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]
2022-06-08 Add individual PCB 204047J
    [204047J ultrasonic.dsn, 204047J ultrasonic.kicad_pcb, 204047J ultrasonic.kicad_sch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]
2022-06-08 Add 204179N Individual pcb
    [Atmega32.kicad_sch, Power_Supply.kicad_sch, camera stand.dsn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]
2022-06-08 added the 204074M PCB
    [Atmega32.kicad_sch, GPS_Magnetometer.dsn, GPS_Magnetometer.kicad_pcb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]
2022-06-08 Add individual pcb 204150T
    [Servo.dsn, Servo.kicad_pcb, Servo.kicad_sch]
2022-06-08 Update Camera Holder PCB 204047J
    [Remote_204047J.kicad_pcb]
2022-06-08 Add simulation
    [Camera Stand.kicad_pcb, Remote.kicad_pcb]
2022-06-08 magnetometer simulation
2022-06-08 Simulation for button
2022-07-30 Update magnetometer.c
    Remove unwanted code part.
